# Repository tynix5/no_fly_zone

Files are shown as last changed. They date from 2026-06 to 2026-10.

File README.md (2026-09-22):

# no_fly_zone
STM32-based quadcopter running on custom hardware and custom flight controller software

## /firmware
Contains STM32 libraries, source code, and build settings for remote and quadcopter

### /no_fly_zone
Contains STM32 flight controller software

### /no_fly_zone_remote
Contains remote control software

### /scripts
AI-generated scripts for testing and validating flight controller outputs

### /stm32_lib
Contains all relevant libraries for sensors and peripheral management

## /hardware
Contains KiCAD schematics + PCB designs for remote and quadcopter

## /screenshots
Contains relevant screenshots for those in other READMEs

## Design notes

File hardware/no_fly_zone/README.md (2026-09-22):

# no_fly_zone Schematic + PCB

## Overview

The quadcopter requires several components

1. Microcontroller
2. Sensor Suite
3. Radio Communication
4. Power Circuitry
5. ESC
6. Motors

The flight controller chosen was the STM32F446RCT for its high maximum clock frequency, dedicated FPU, and abundant communication modules. The sensor suite in Revision 1.0 consists of a 6DOF IMU, magnetometer, barometer, and GPS. Each of these sensors provides useful data for the flight controller. The IMU provides information on pitch and roll, magnetometer on yaw, barometer on altitude, and GPS for extended yaw support as well as location tracking for future revisions. Onboard magnetometers are very susceptible to EMF fields from motors, other sensors, as well as PCB traces. Thus, the GPS can be used as a backup for heading. 

The nRF24L01 was chosen to communicate with the remote, also using the nRF24L01. In the future, a dedicated PA + LNA chip may be added on board to extend quadcopter range.

The power circuitry consists of an onboard buck converter on the bottom side of the PCB in order to reduce noise to other components. More details below.

## Revision 1.0
### Summary

The single schematic given here is separated into two boards. A singular board containing all components was not able to fit onto the quadcopter frame. Thus, a separate MCU board and sensor board were produced using KiKit and connectors were used to share power and communication.

### Schematics

#### Hierarchal Schematic

The hierarchal schematic provides a top-level overview of the two boards. The ESC connectors, power schematic, and RF schematic were all included on the MCU board. The sensor board contains only the sensor schematic.

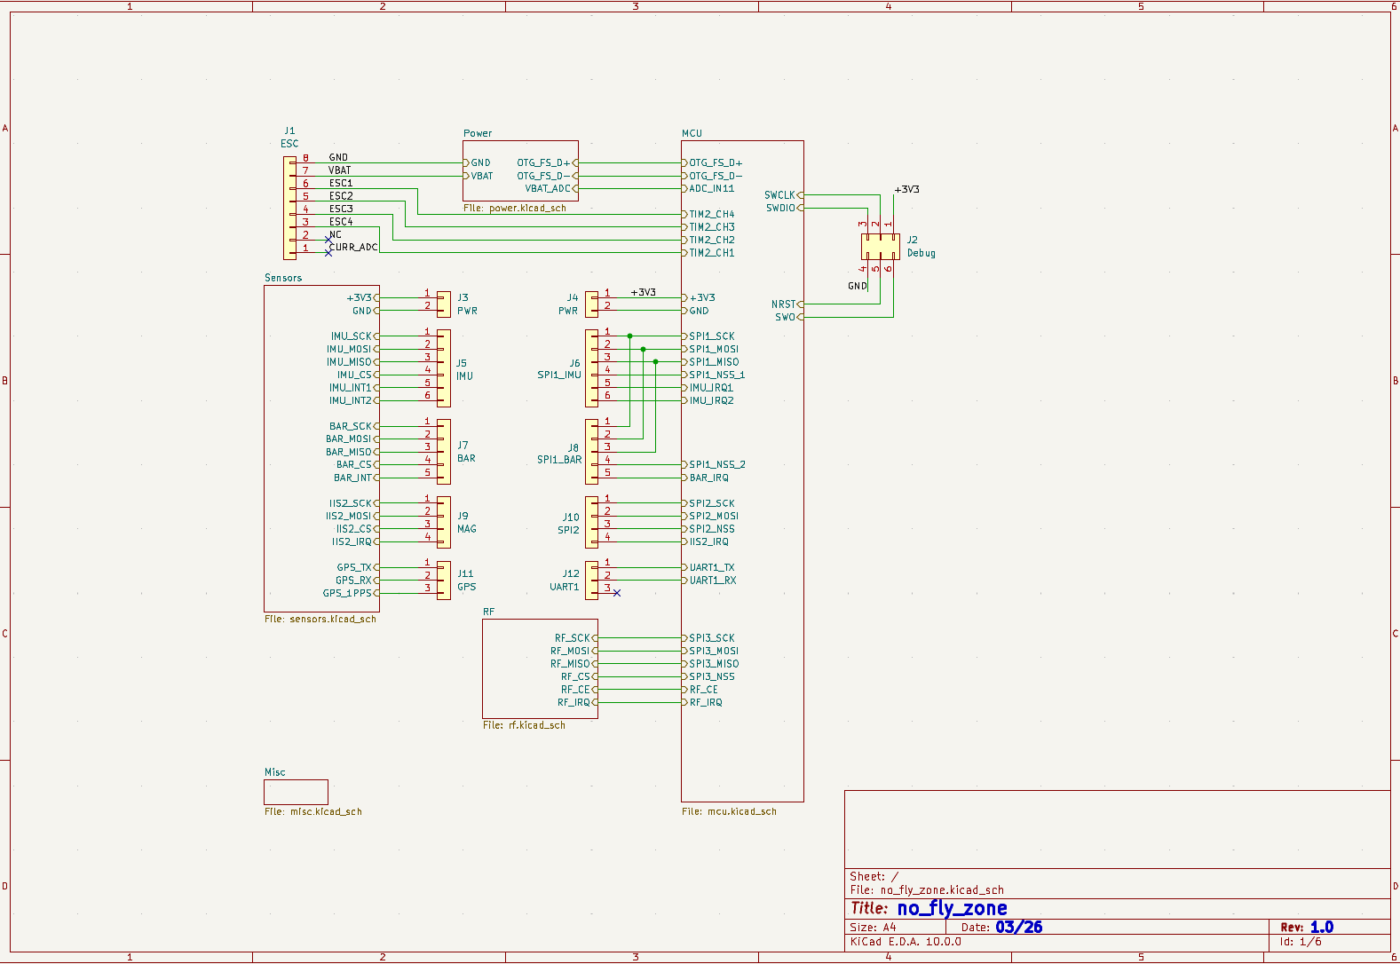
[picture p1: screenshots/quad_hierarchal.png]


#### MCU

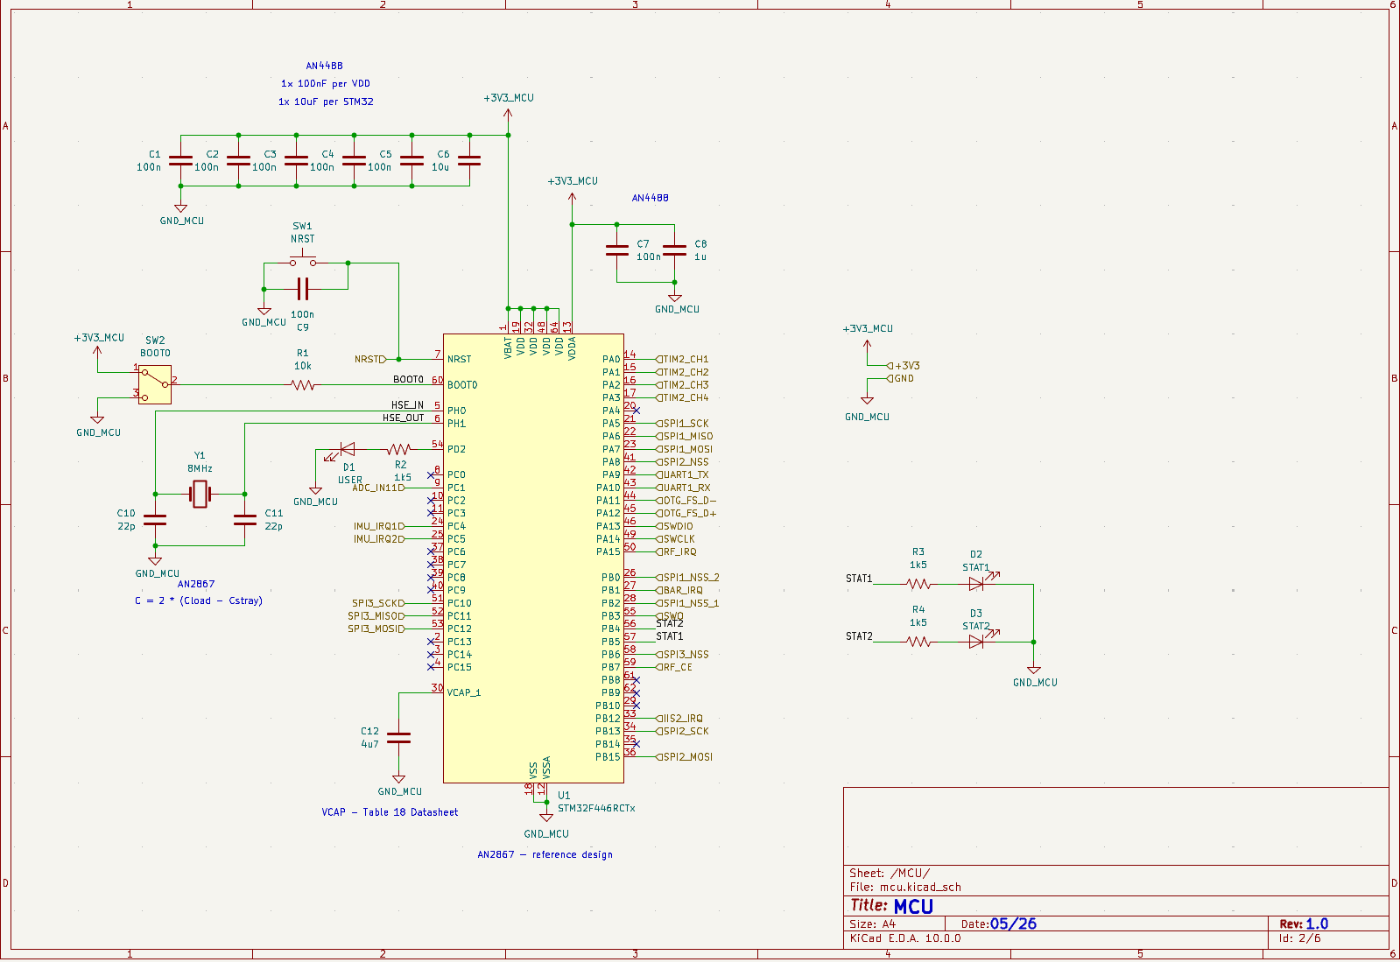
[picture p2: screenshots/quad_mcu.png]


#### Sensors

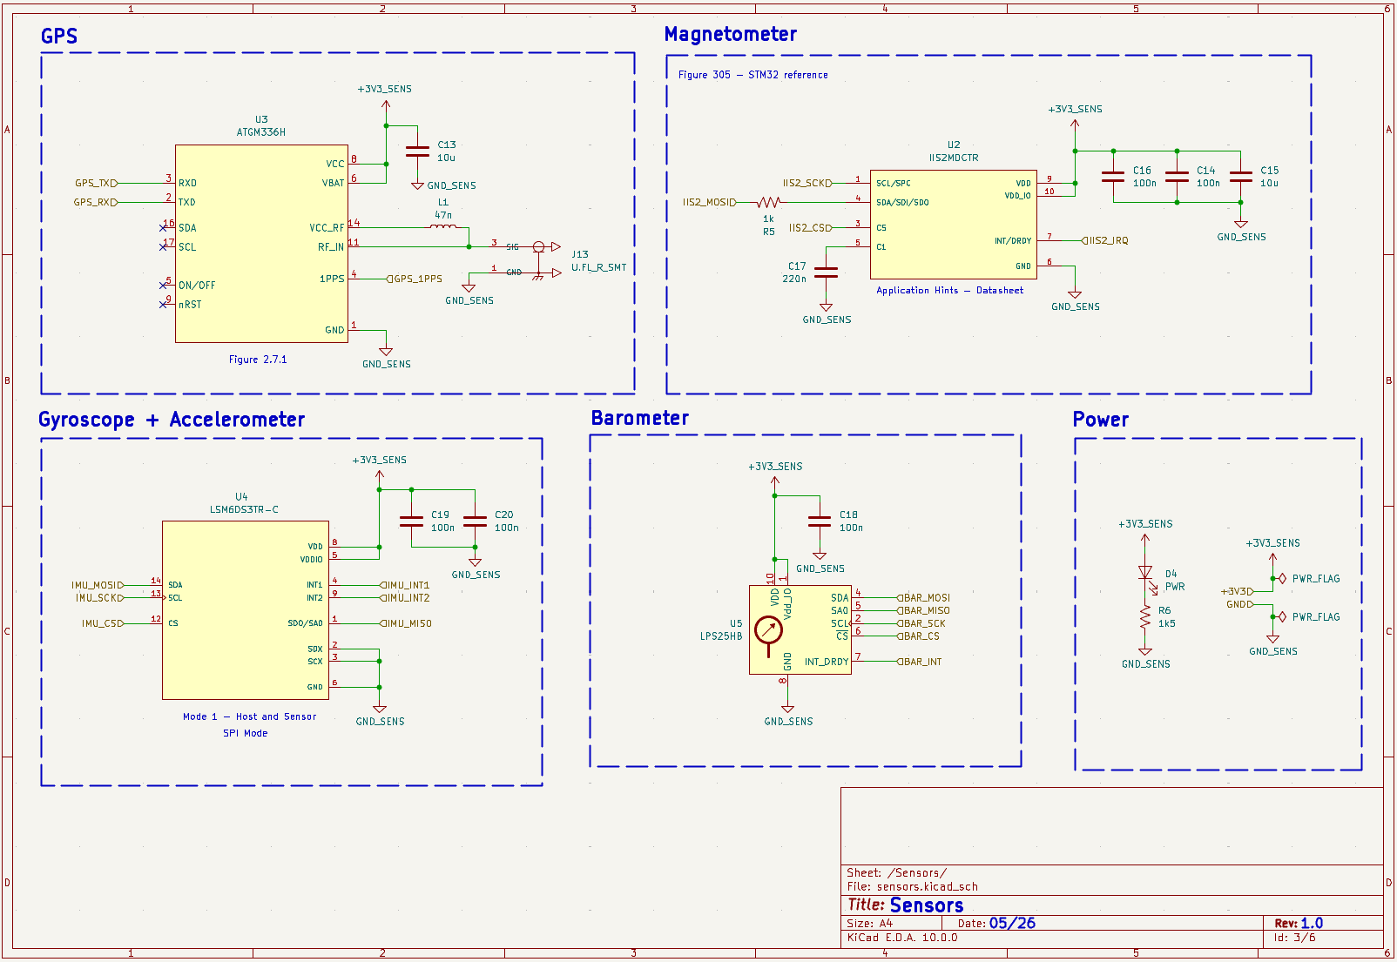
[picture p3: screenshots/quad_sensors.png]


#### Power

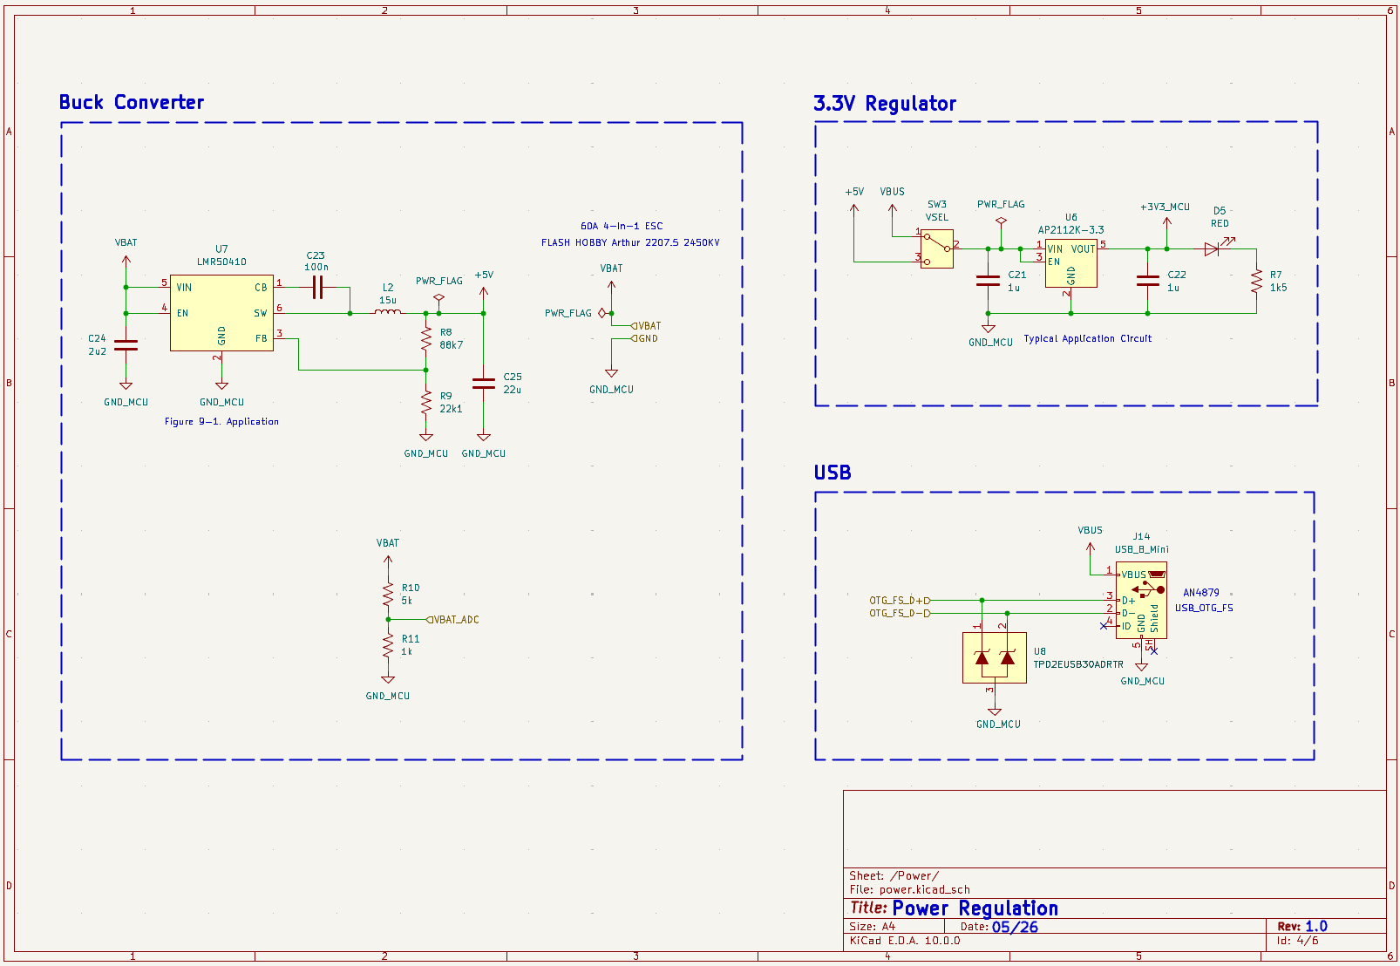
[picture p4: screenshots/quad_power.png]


#### RF

Like the RF section on the remote, the nRF24L01 is surrounded by a continuous ground plane on the top layer as well as the layer directly underneath the antenna for stability. Stitching vias are placed about ~6mm apart (between lambda/10 - lambda/20 of 2.4 GHz wavelength) near antenna for shielding.

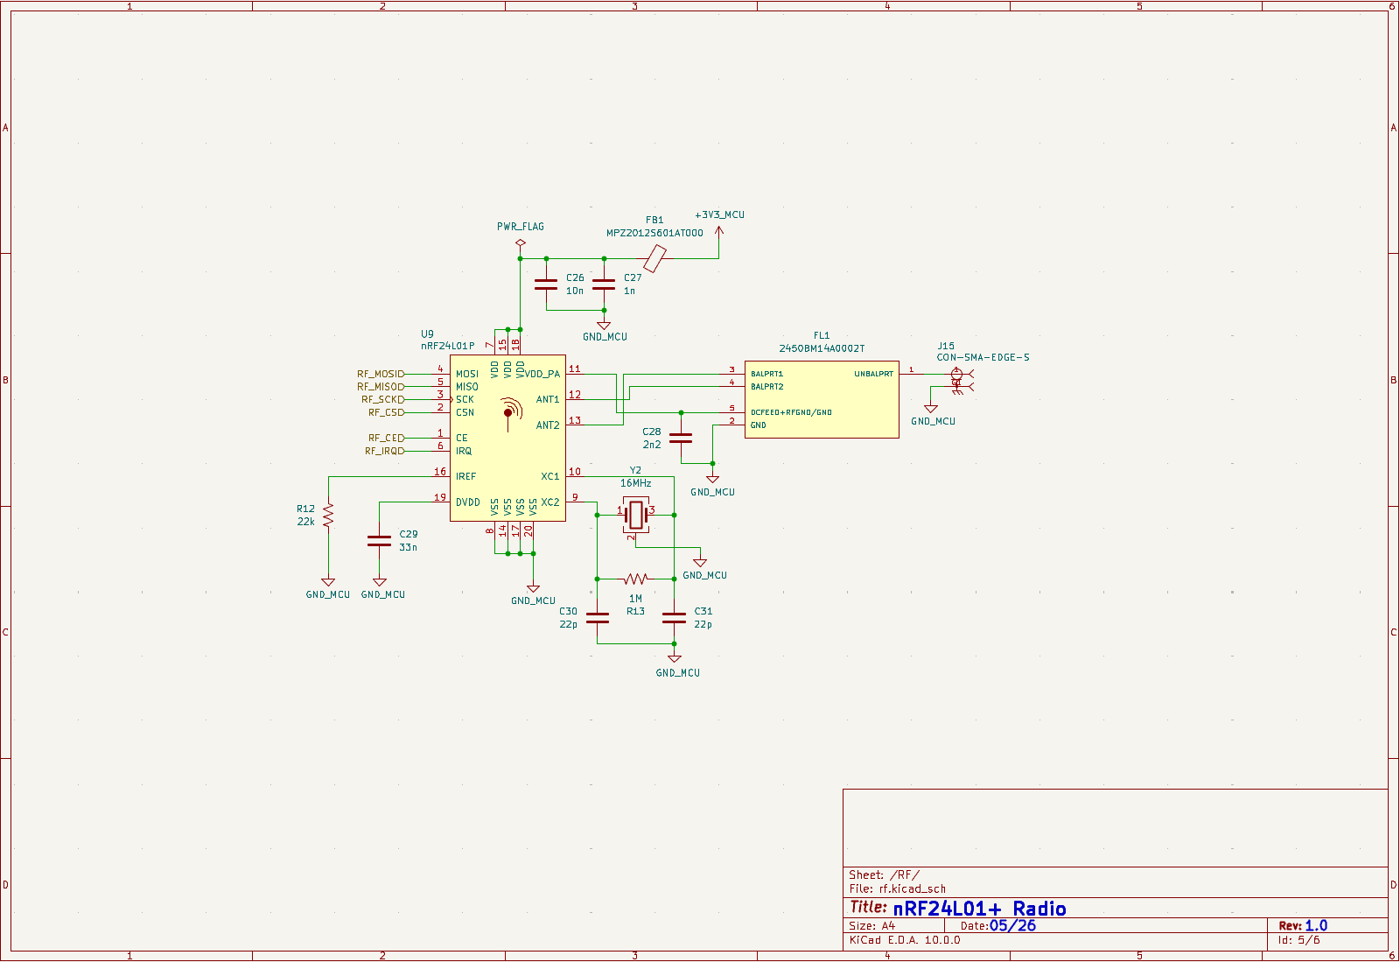
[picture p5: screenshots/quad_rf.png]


#### Misc

Contains 8 M3 screw holes, 4 for each board. Not shown for brevity.

#### PCB

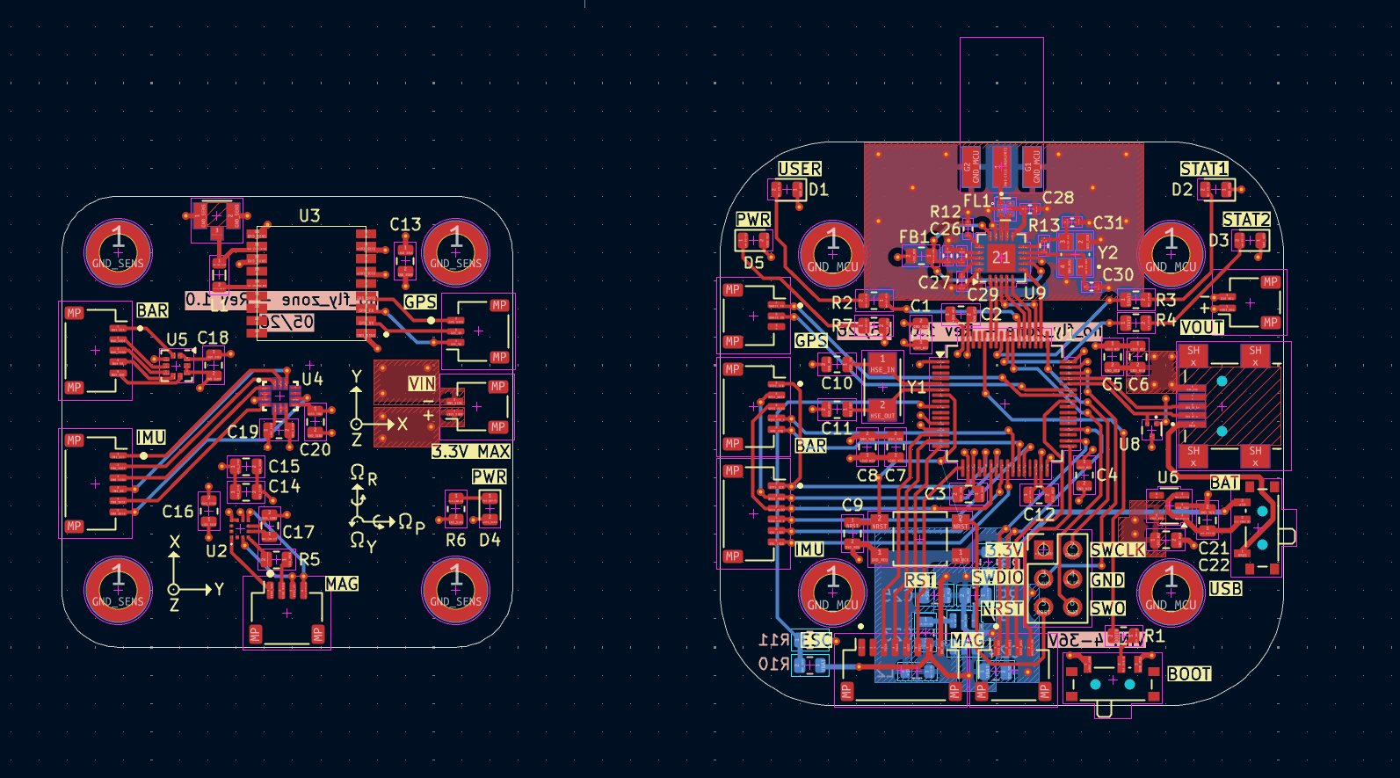
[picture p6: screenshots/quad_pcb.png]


#### 3D

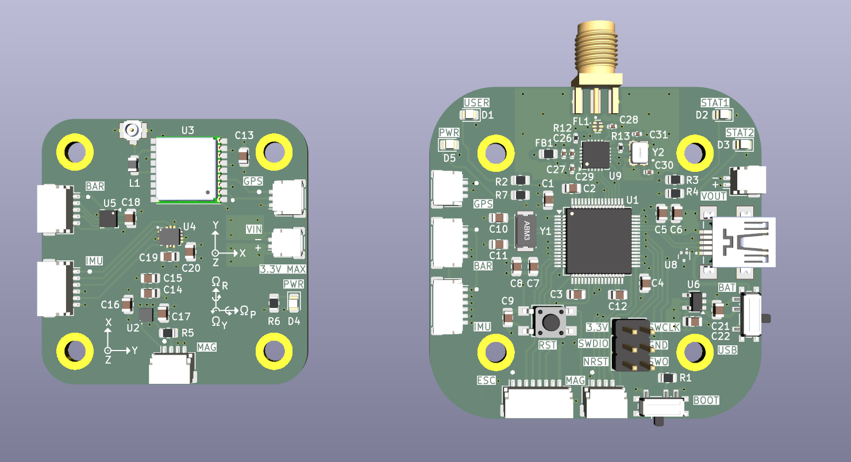
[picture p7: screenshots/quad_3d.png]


## Revision 2.0

### Summary 
This revision involved consolidating the sensor board and MCU and removing the onboard magnetometer and GPS. The goal of this project was to achieve simple flight manuevers and hovering, and using these sensors would require more in depth sensor fusion algorithms. The antenna section was improved with further RF shielding and stitching vias, as well as a taper from the RF unbalanced port to the SMA pad. The board stackup changed from SIG - GND - 3.3V - SIG to a SIG - GND - GND - SIG + 3.3V to reduce buck converter and RF noise. 

Revision 1.0 board worked, but there were some problems with the JST connectors, making it hard to keep communication with the sensors, and they would not have been very reliable in a noisy and harsh environment. Ground lines were needed next to every signal line, but only one ground line was used on the entire board (power connector).

### Changes
- Consolidated sensor and controller board
- Removed magnetometer and GPS
- Improved RF shielding and layout
- Layer stackup changed from SIG-GND-3.3V-SIG to SIG-GND-GND-3.3V

### Schematics

### Hierarchal Schematic
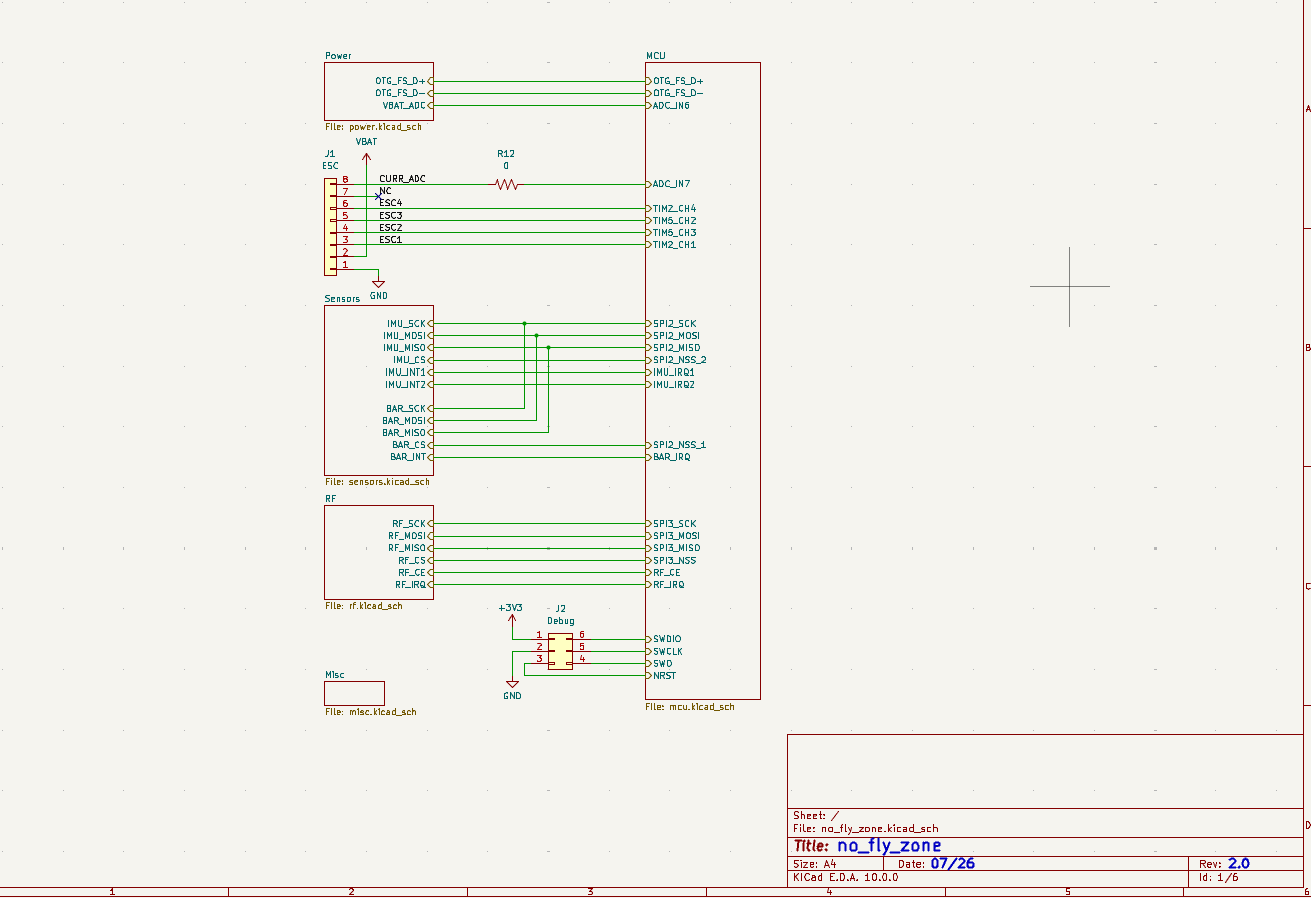
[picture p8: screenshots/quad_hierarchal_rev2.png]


#### MCU
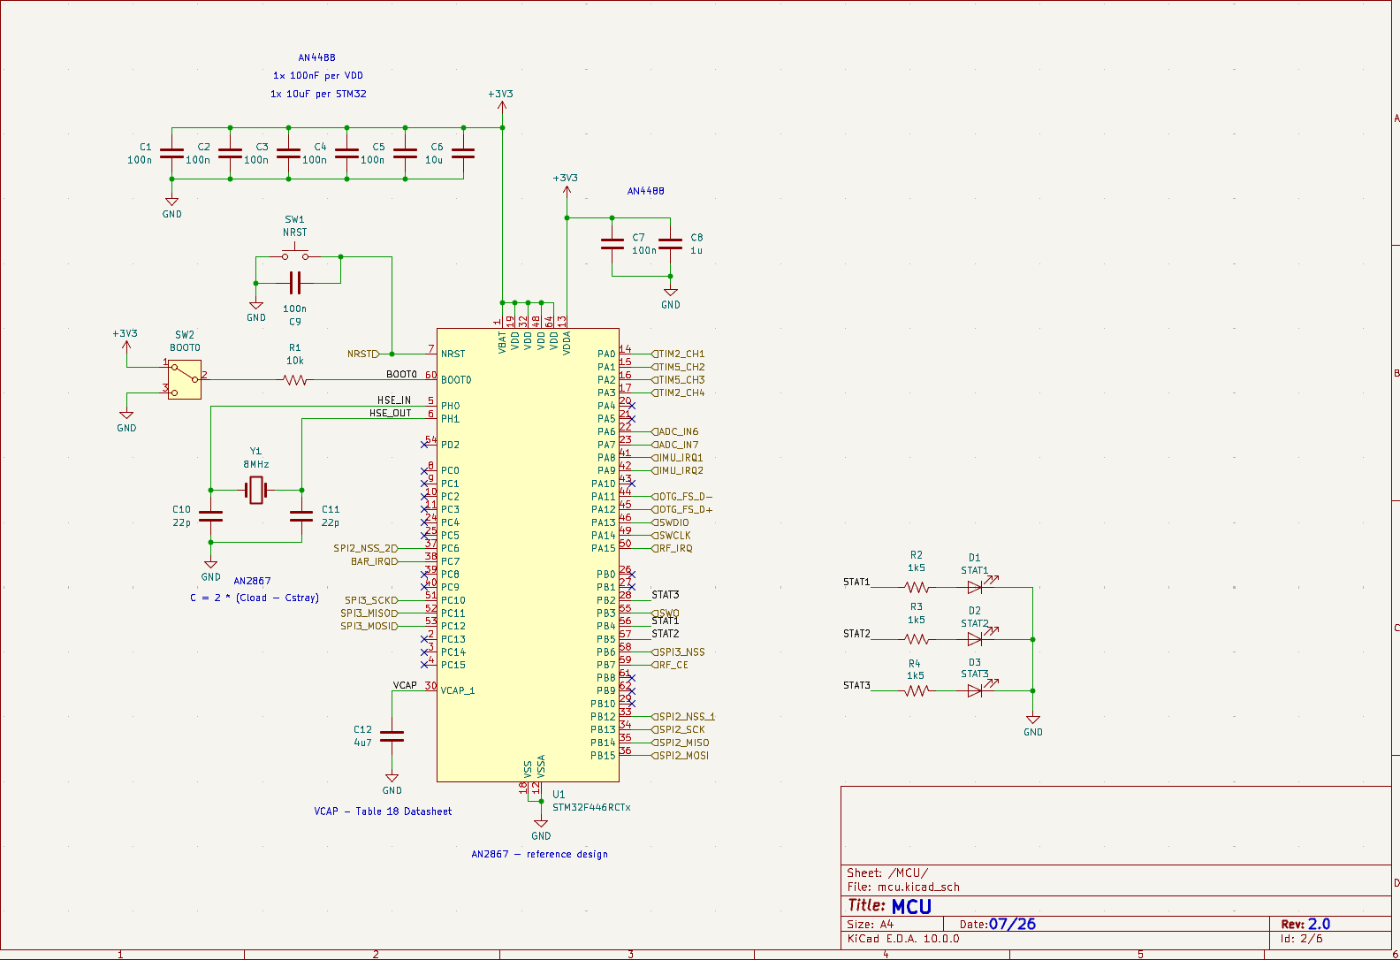
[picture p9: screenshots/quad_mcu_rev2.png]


#### Sensors
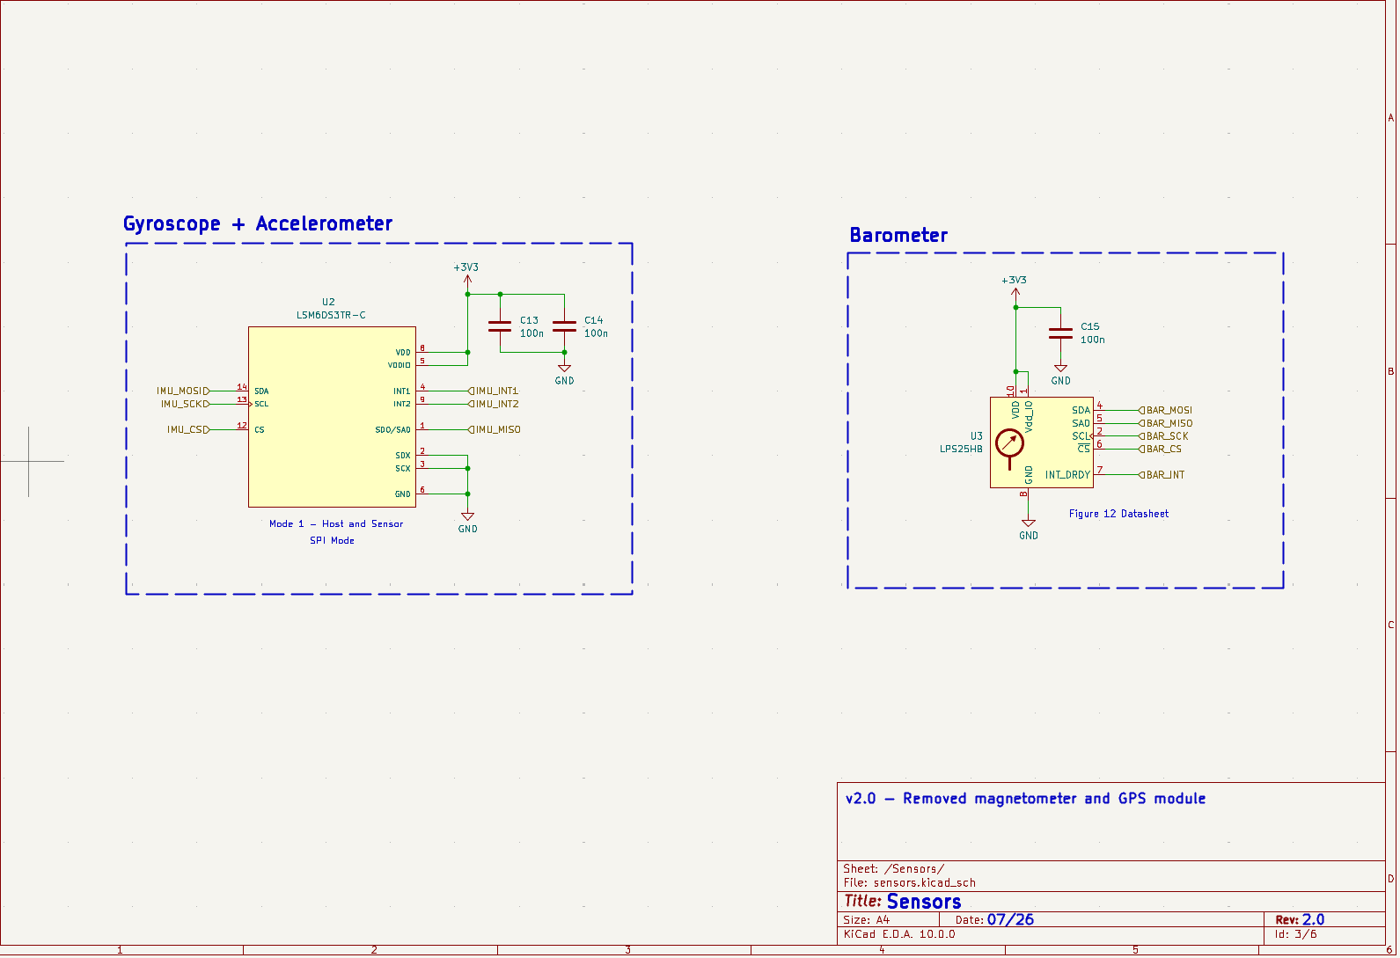
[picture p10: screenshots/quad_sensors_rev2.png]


#### Power
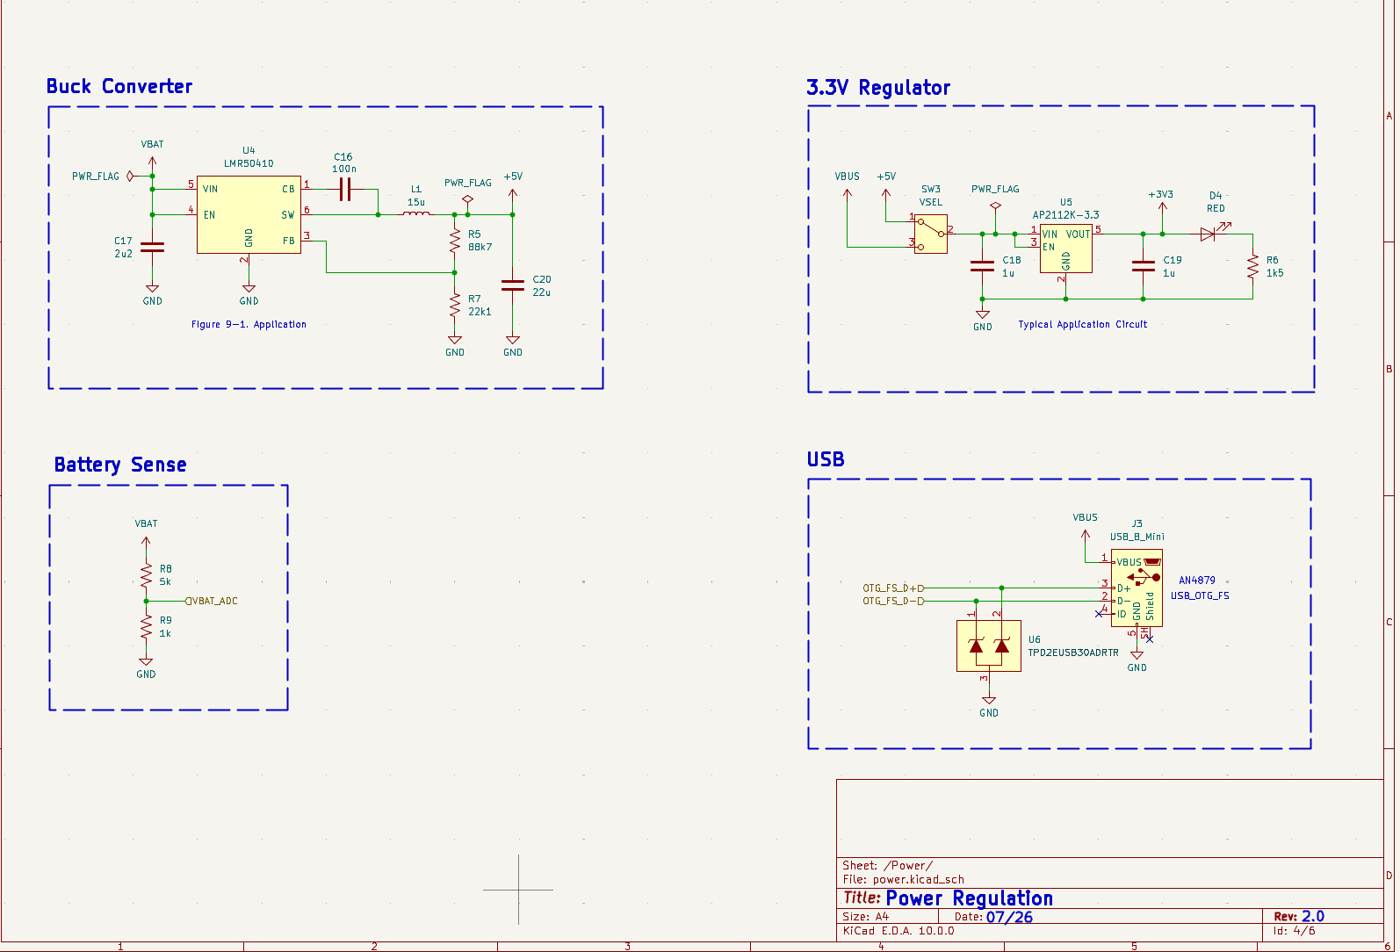
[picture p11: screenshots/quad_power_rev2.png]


#### RF
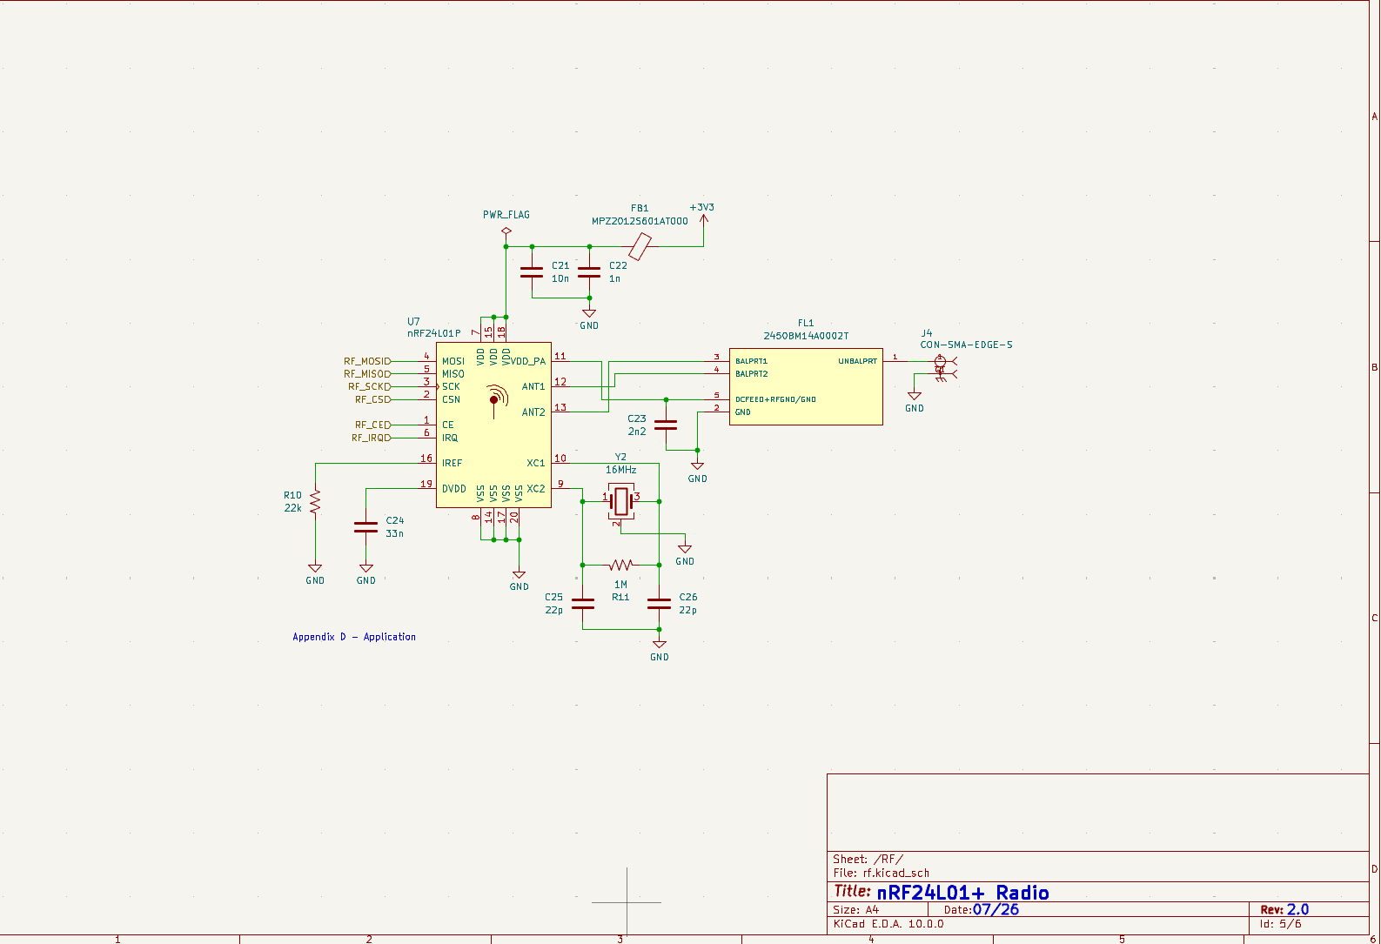
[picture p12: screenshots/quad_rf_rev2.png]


#### PCB

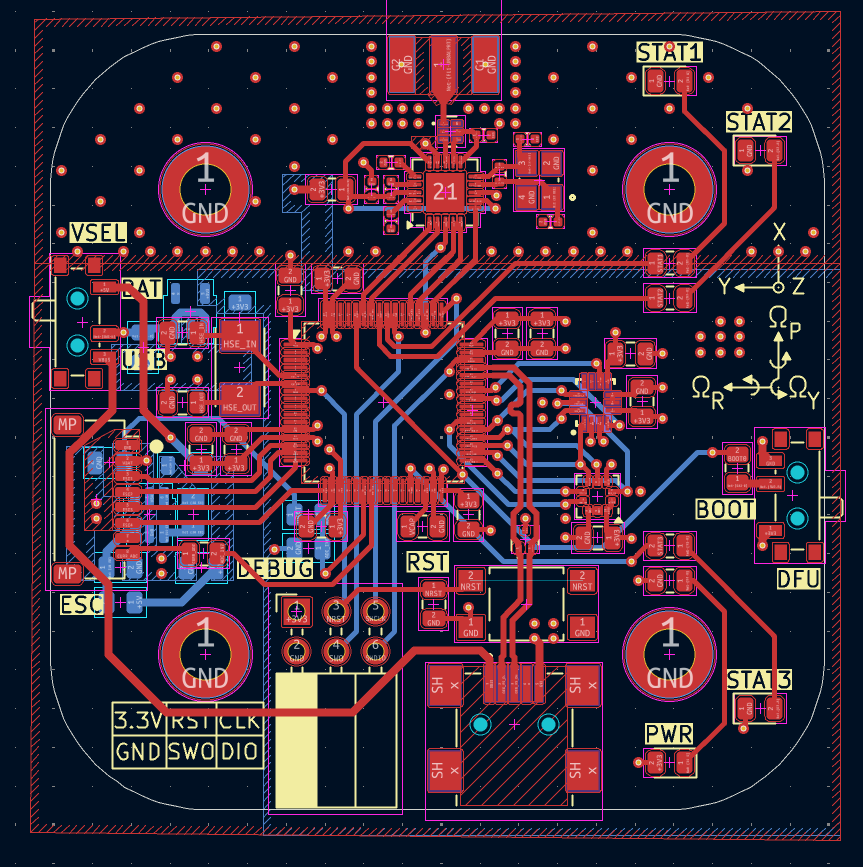
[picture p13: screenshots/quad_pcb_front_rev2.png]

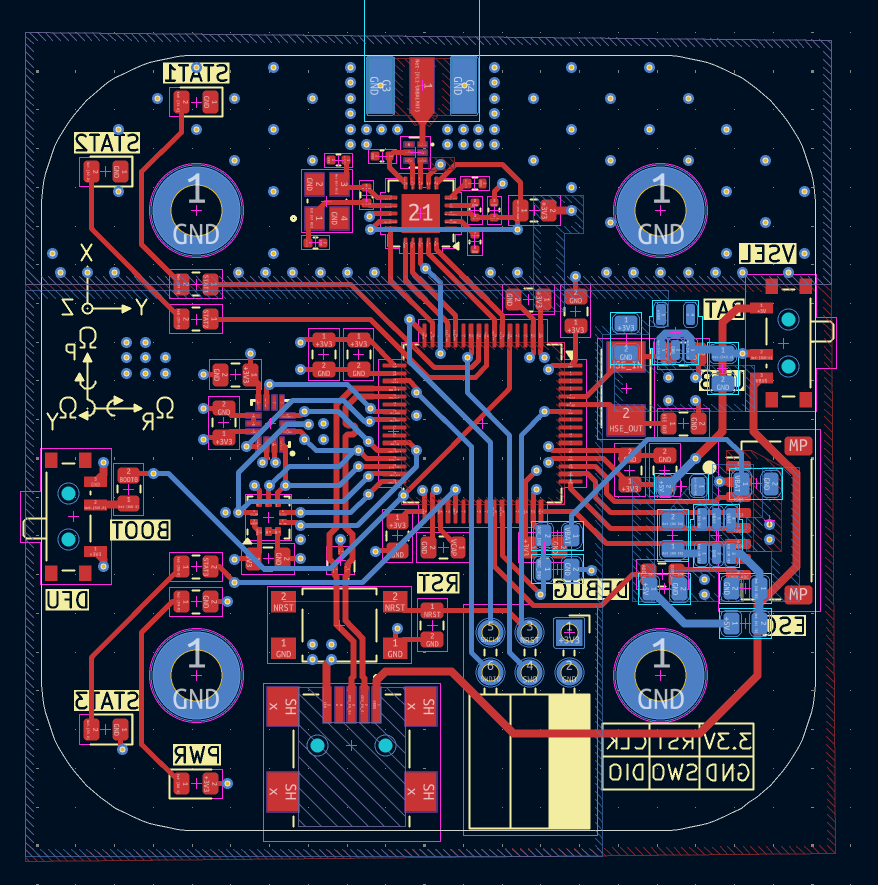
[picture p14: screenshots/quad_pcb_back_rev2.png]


#### 3D

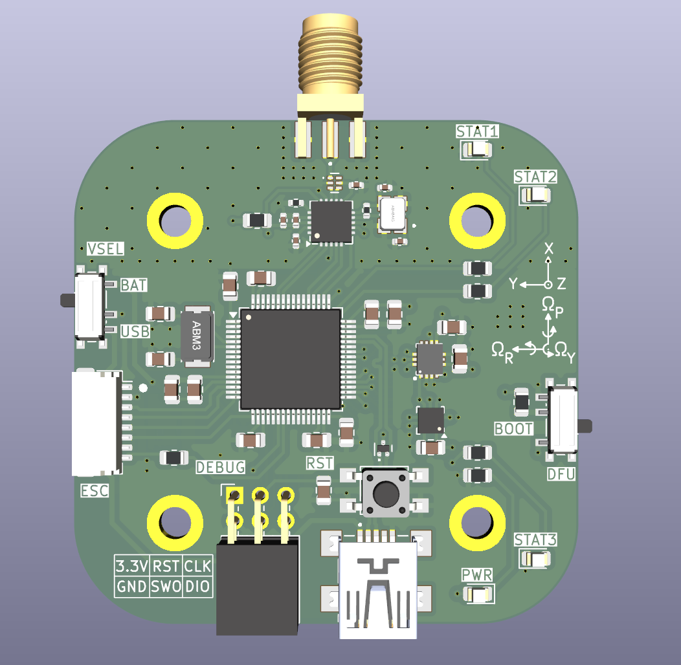
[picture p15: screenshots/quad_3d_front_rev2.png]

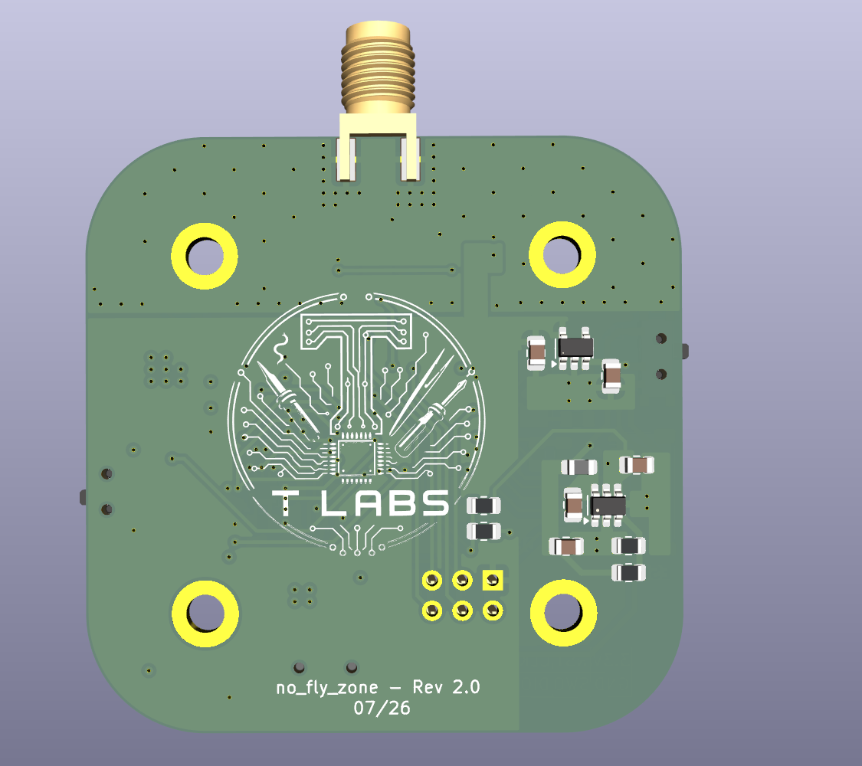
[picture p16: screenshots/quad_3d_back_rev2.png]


## Revision 2.1

### Summary 
While working with the Revision 2.0 flight controller, it was too large to fit comfortably on the quadcopter frame, so changes were made to reduce size while keeping functionality

### Changes
- Board size reduced from 50mm x 50mm to 40mm x 40mm
- Most part footprints reduced from 0805 packages to 0603
- Added TVS diodes to power inputs and connectors
- Removed ferrite bead in series with RF power supply
- Changed debug connector to STLINK specific
- Moved STAT3 from PB2 to PB8

#### MCU
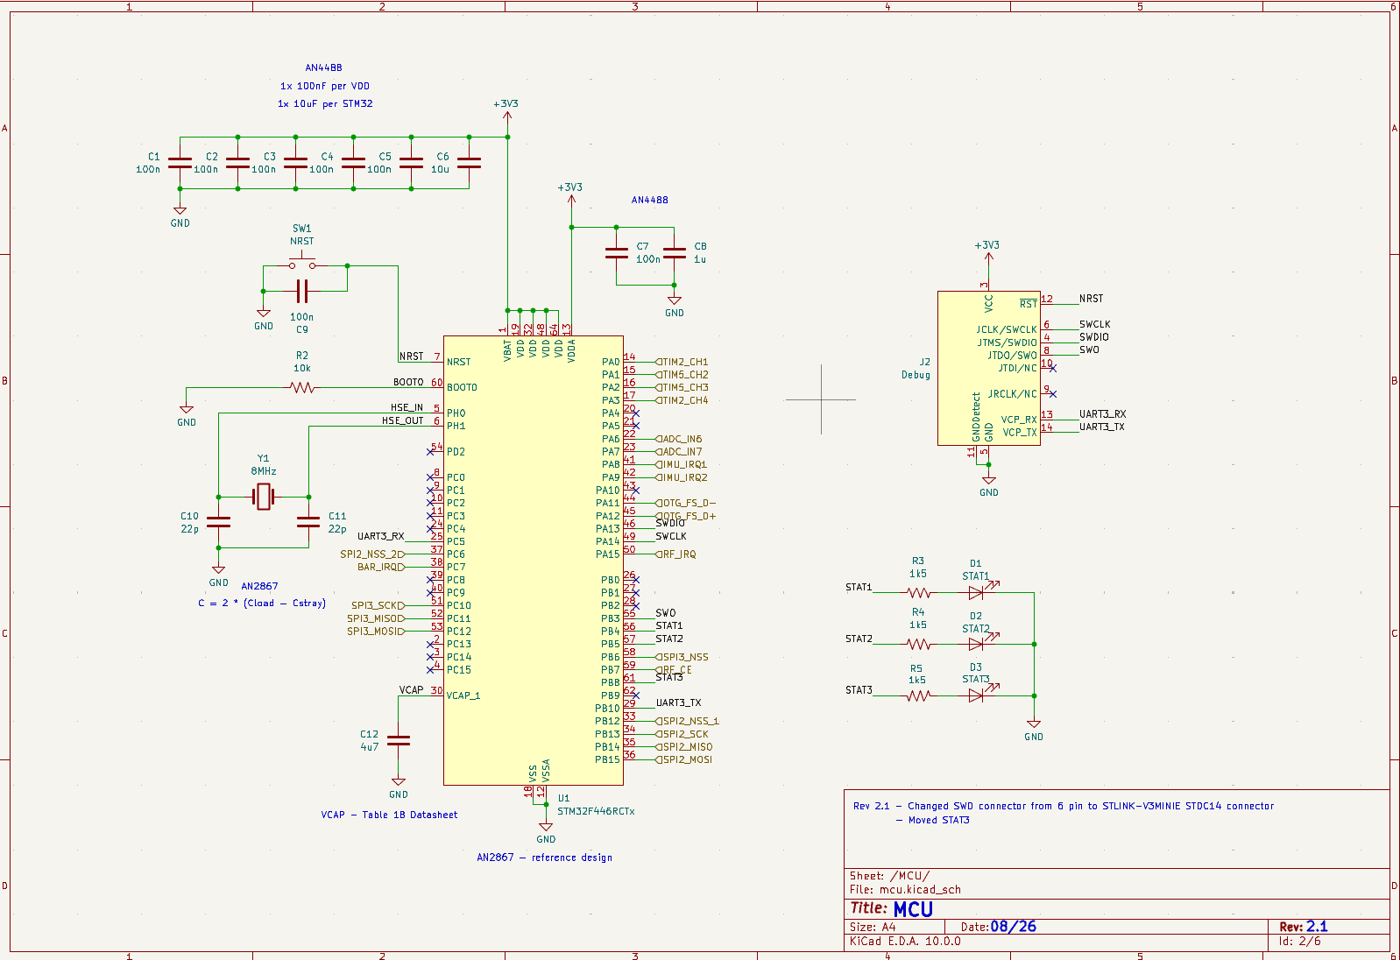
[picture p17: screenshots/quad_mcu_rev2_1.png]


#### Sensors
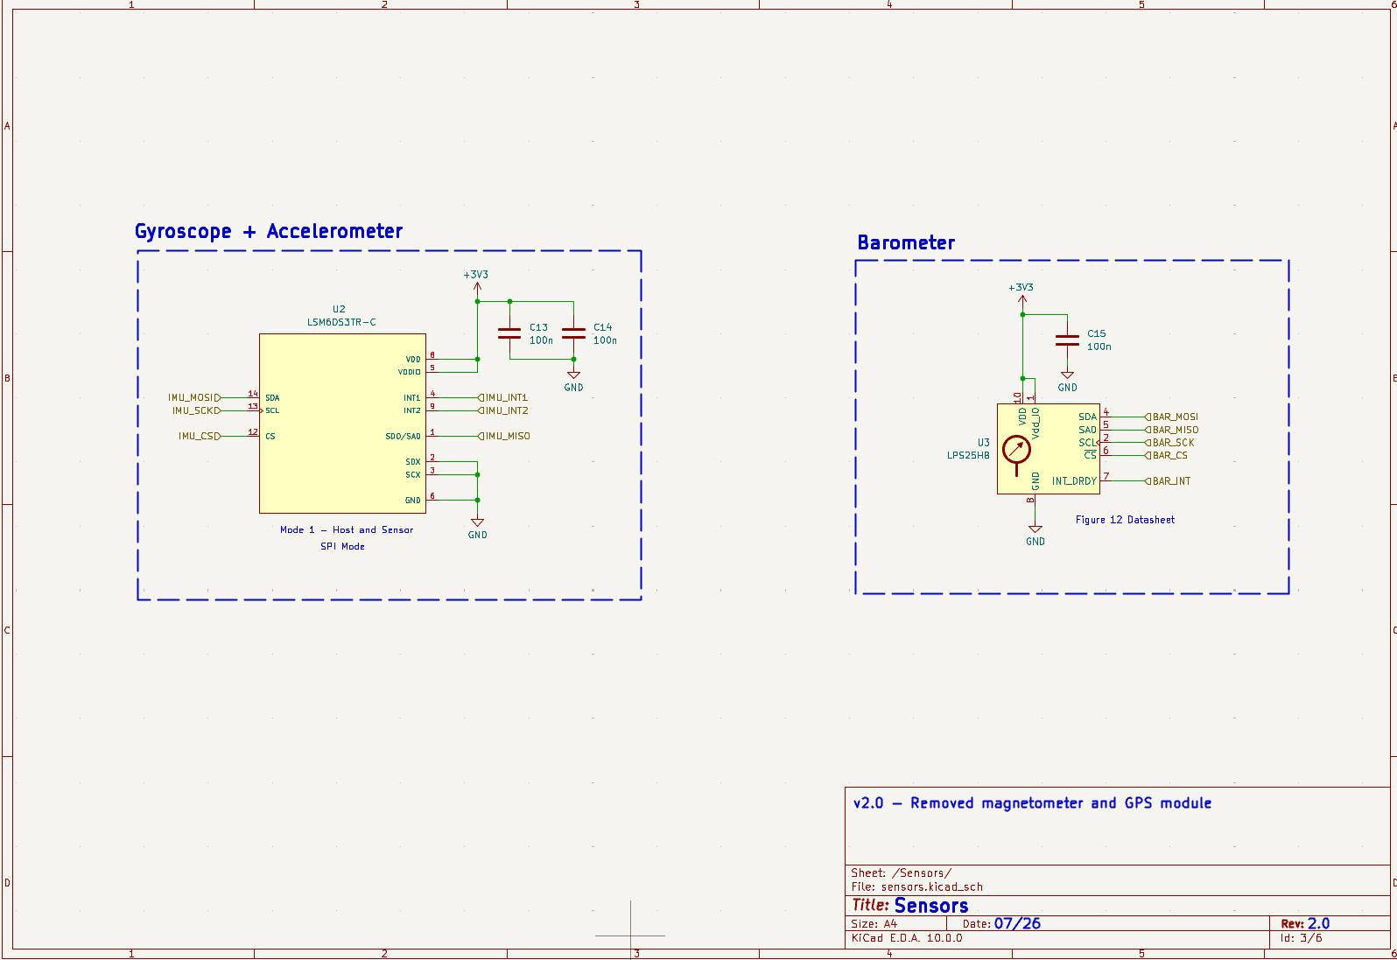
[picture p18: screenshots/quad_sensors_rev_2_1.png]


#### Power
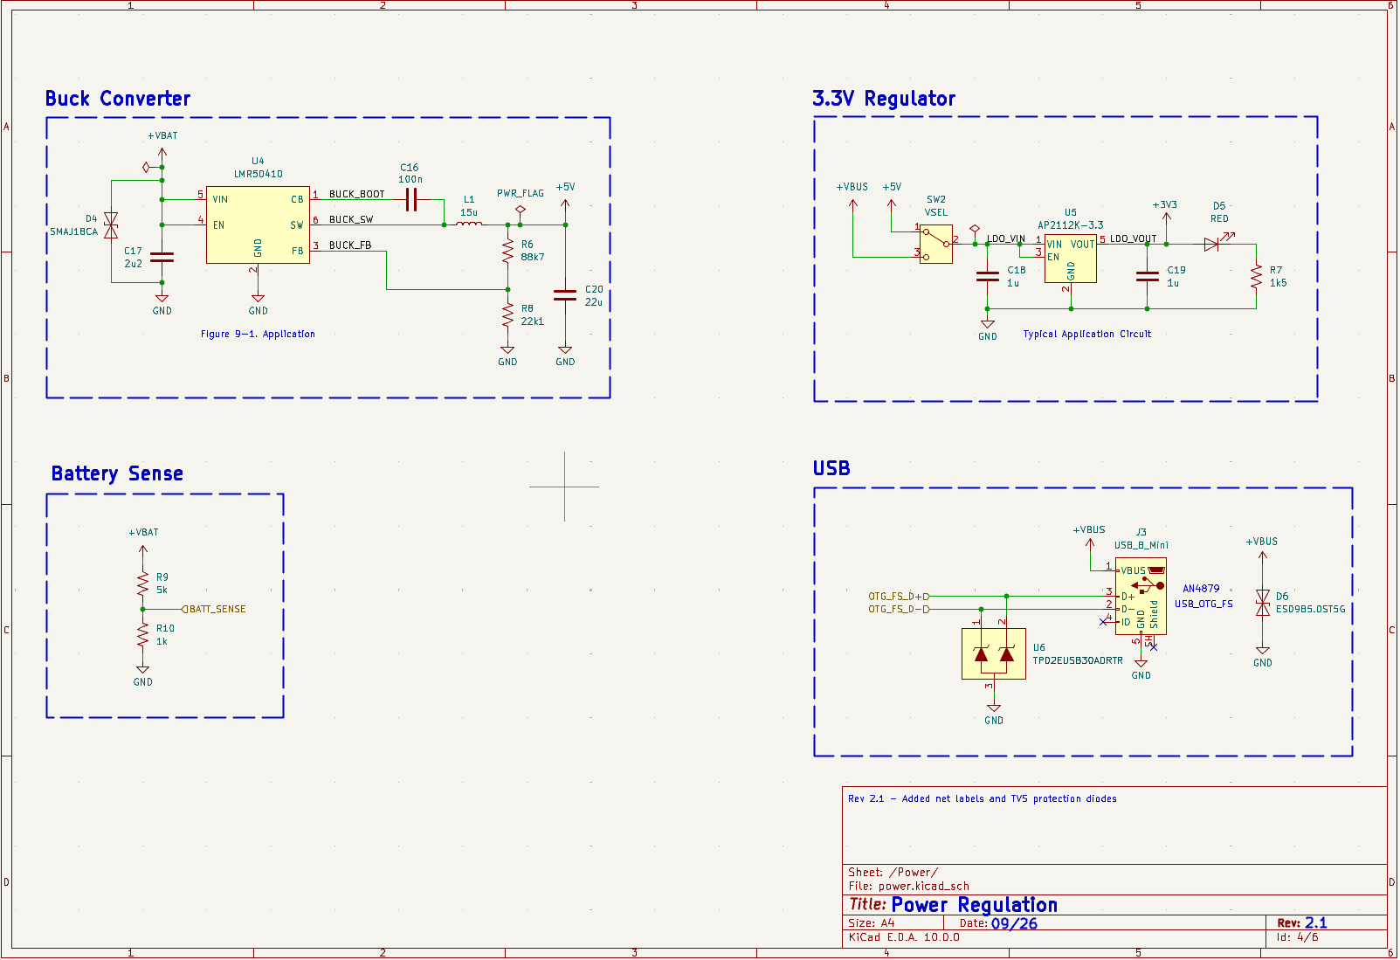
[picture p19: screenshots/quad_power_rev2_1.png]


#### RF
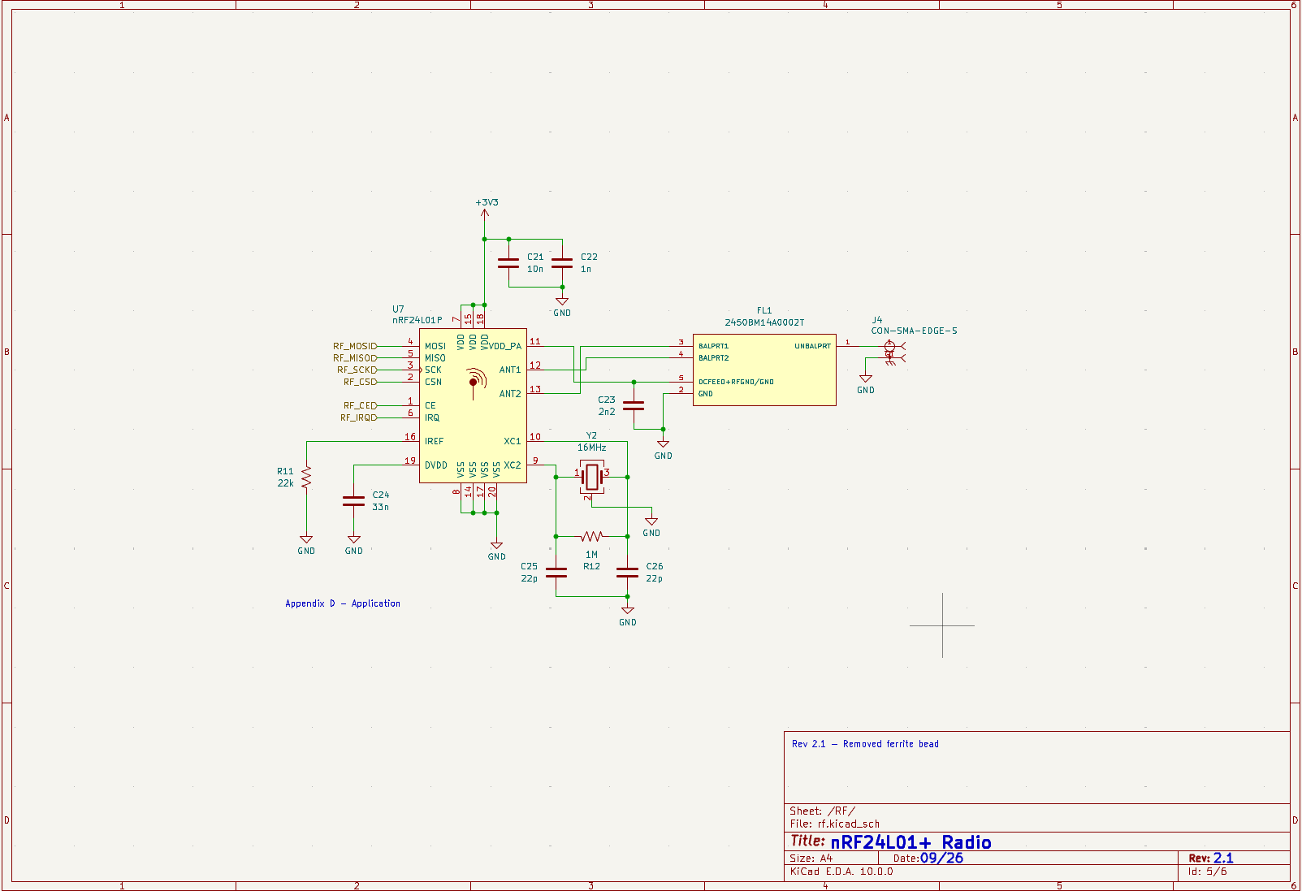
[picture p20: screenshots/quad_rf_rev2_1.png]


#### 3D
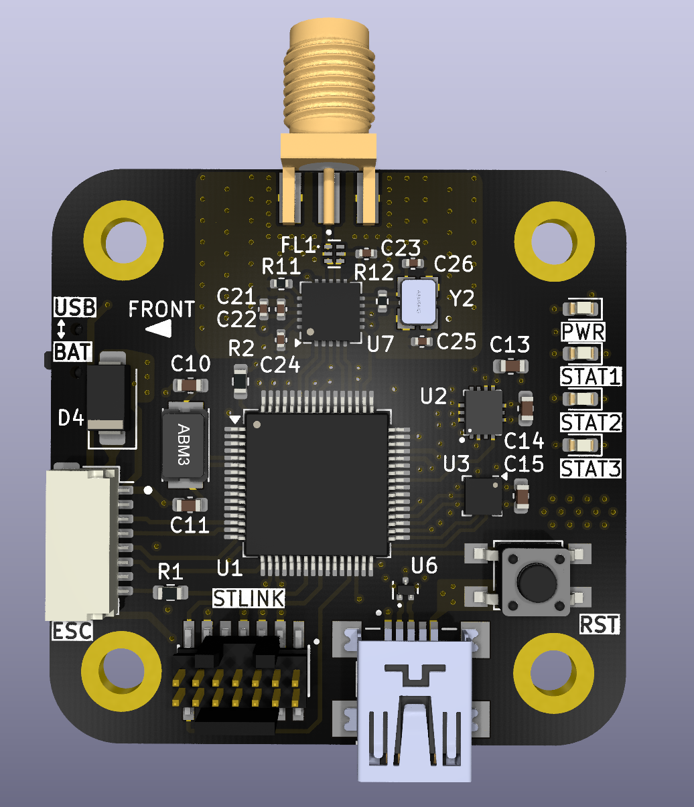
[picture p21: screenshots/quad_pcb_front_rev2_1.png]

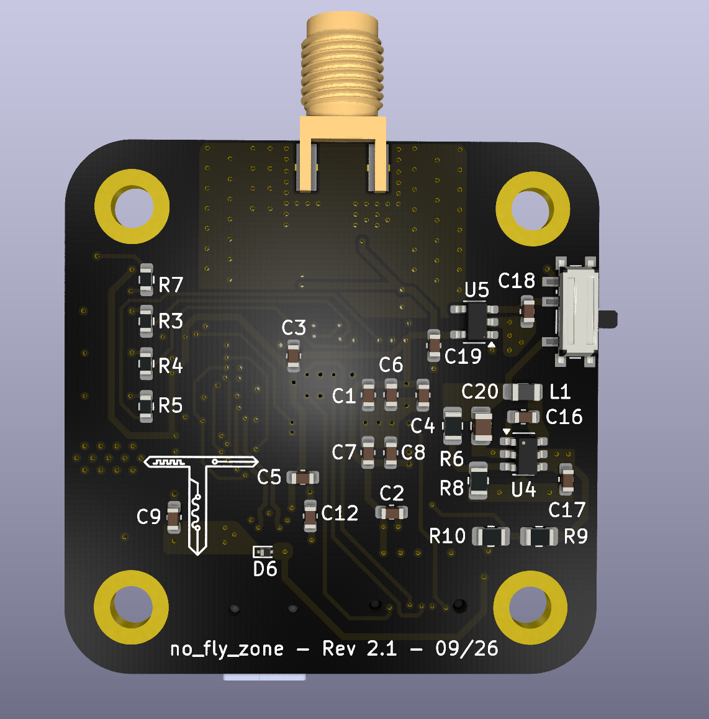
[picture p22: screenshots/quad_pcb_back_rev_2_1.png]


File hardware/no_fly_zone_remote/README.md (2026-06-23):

# no_fly_zone_remote Schematic + PCB
## Overview

The remote for this quadcopter requires several things

1. Microcontroller
2. Control Inputs - Joysticks, Encoders
3. Wireless Communication
4. Charging Circuitry
5. OLED

The STM32L432KC microcontroller was chosen for its small package, low power draw, and adequate maximum clock speed. The joysticks, PS5 TMR (Tunnel Magnetoresistance), were chosen due to their low deadzones, small footprint, and wide availability. The joysticks control the quadcopters throttle, yaw, pitch, and roll. The encoder included on the PCB is used to switch between various menus, displayed on the SSD1306 OLED, and for tuning quadcopter PID parameters easily. The nRF24L01 radio was chosen for its high availablity and simplicity in function. The charging circuity involves an autoswitching power multiplexer and a linear 1S LiPo charger. The autoswitcher IC automatically chooses the highest available power source. If only LiPo is connected, it is used to power the remote, but if LiPo and USB power are present, USB power is used to power the board and simultaneously charge the LiPo. The board can also be powered using only USB without a LiPo.

More details are given on the schematics for exact component parameters.

All footprints and schematics symbols were found online or in KiCAD libraries.

## Versions

The folder structure indicates there are two versions of the PCB: original and revised. The original PCB was never manufactured and used the wrong footprints for several parts, as well as did not have great PCB design characteristics. Instead, the revised version was manufactured and shows all correct footprints and better PCB design methodology. 

An important note on the revised version is Revision 1.0 used the wrong TVS diodes for USB D+ and D-, but these were changed to dedicated USB TVS diodes in a later revision.

## Schematics

### Hierarchal Schematic

The hierarchal schematic details how the MCU, sensors, and power schematics are connected.

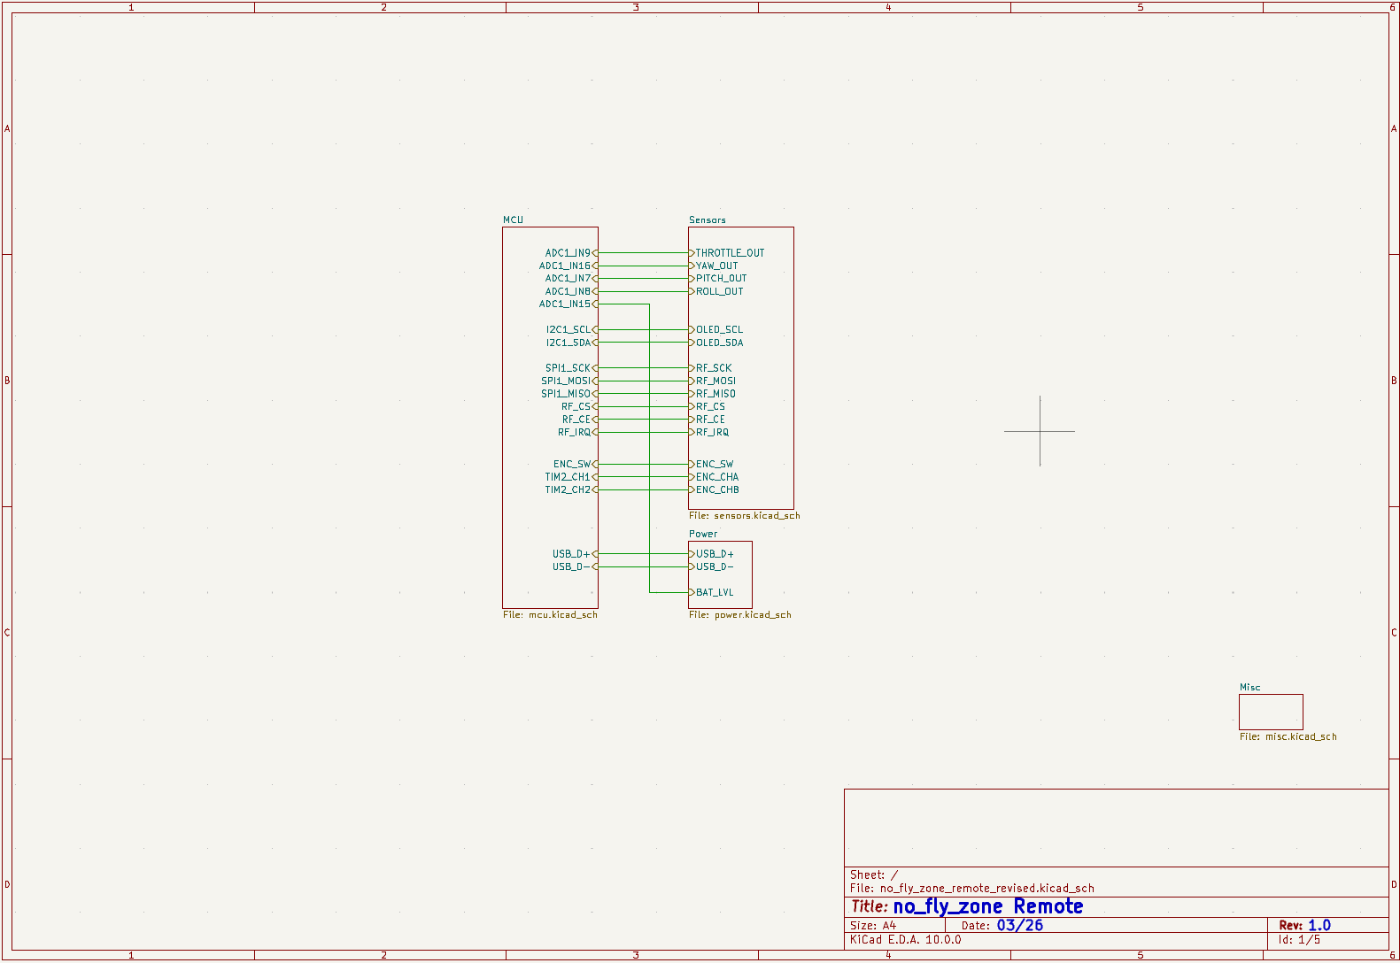
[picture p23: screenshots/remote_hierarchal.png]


### MCU

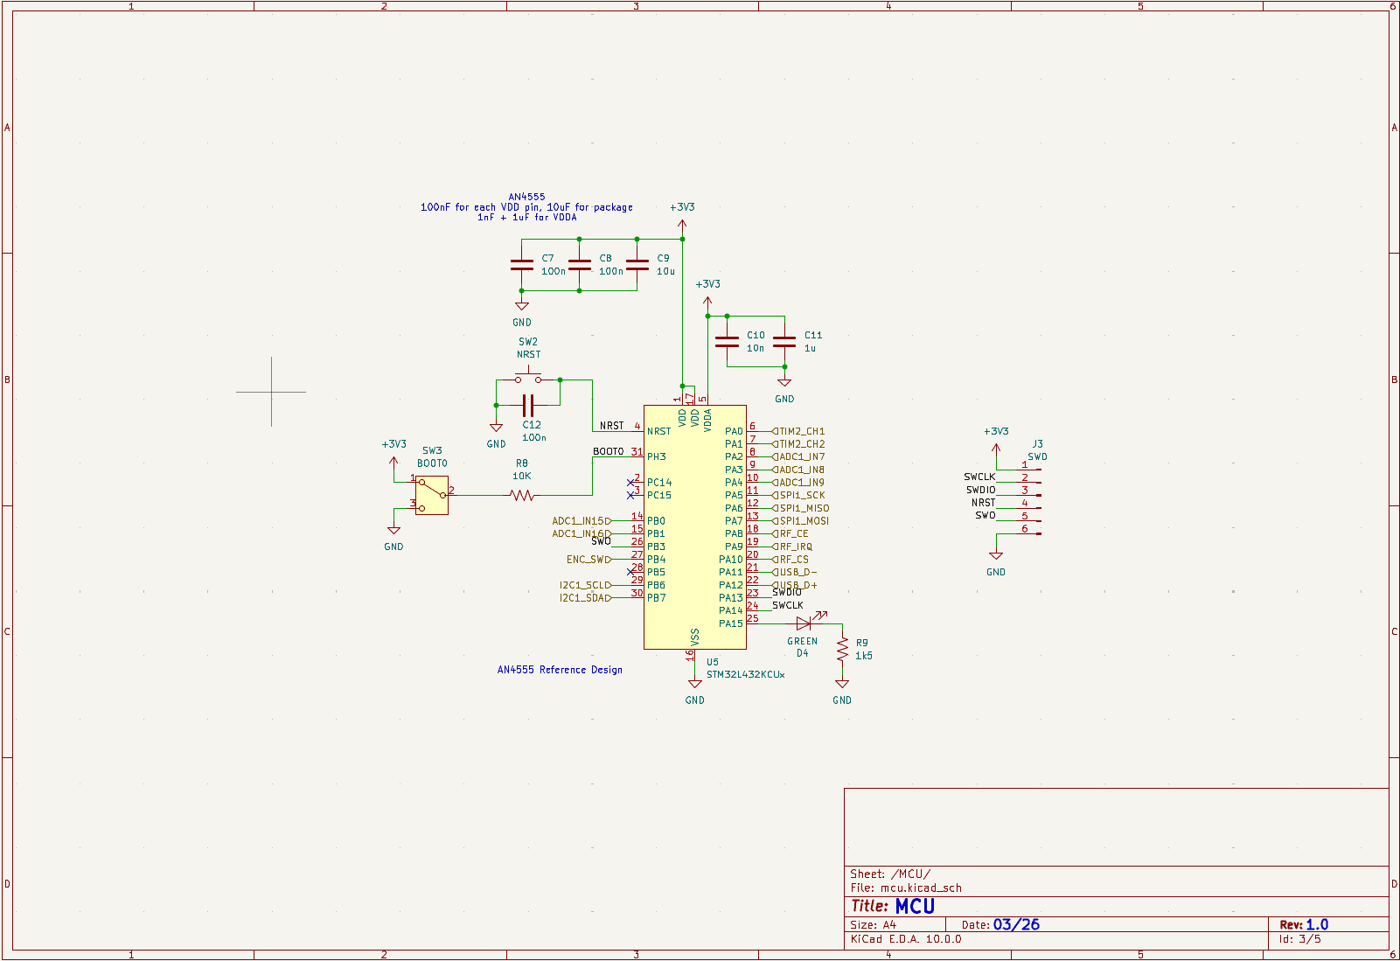
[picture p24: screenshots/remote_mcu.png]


### Sensors (Radio, OLED, Joysticks, Encoder)



### Misc

Contains four M3 screws with pads, not shown for brevity

### PCB

Note on radio layout: the nRF24L01 is surrounded by a continuous ground plane on the top layer as well as the layer directly underneath the antenna for stability. Stitching vias are placed about ~6mm apart (between lambda/10 - lambda/20 of 2.4 GHz wavelength) near antenna for shielding.



### 3D Model



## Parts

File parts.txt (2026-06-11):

Quadcopter
CPU: STM32F466RCT6
IMU (accel + gyro): LSM6DS3TR-C
Magnetometer: IIS2MDCTR
GPS: ATGM336H
Barometer: LPS25HB
Radio: nRF24L01
Motors: FLASH HOBBY Arthur 2207.5 Outrunner 2450KV
ESC: AERO SERLFIE 60A 4IN1 ESC 2S-6S LiPo
Rotors:
Battery:
Frame: FPVDrone 225mm FPV Racing Drone 5 inch

Controller
CPU: STM32L432KC
Joystick: Gulikit TMR
Encoder: Bourns PEC11R-2415F-S0024
Radio: nRF24L01
Battery: EEMB 3.7V LiPo Battery 1100mAh

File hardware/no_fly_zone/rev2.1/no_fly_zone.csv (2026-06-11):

Id | Designator | Footprint | Quantity | Designation | Supplier and ref
1 | C1, C2, C3, C4, C5, C7, C9, C14, C16, C18, C19, C20, C23 | C_0805_2012Metric | 13 | 100n
2 | C6, C13, C15 | C_0805_2012Metric | 3 | 10u
3 | C8, C21, C22 | C_0805_2012Metric | 3 | 1u
4 | C10, C11 | C_0805_2012Metric | 2 | 22p
5 | C12 | C_0805_2012Metric | 1 | 4u7
6 | C17 | C_0805_2012Metric | 1 | 220n
7 | C24 | C_0805_2012Metric | 1 | 2u2
8 | C25 | C_0805_2012Metric | 1 | 22u
9 | C26 | C_0402_1005Metric | 1 | 10n
10 | C27 | C_0402_1005Metric | 1 | 1n
11 | C28 | C_0402_1005Metric | 1 | 2n2
12 | C29 | C_0402_1005Metric | 1 | 33n
13 | C30, C31 | C_0402_1005Metric | 2 | 22p
14 | D1 | LED_0805_2012Metric | 1 | USER
15 | D2 | LED_0805_2012Metric | 1 | STAT1
16 | D3 | LED_0805_2012Metric | 1 | STAT2
17 | D4 | LED_0805_2012Metric | 1 | PWR
18 | D5 | LED_0805_2012Metric | 1 | RED
19 | FB1 | R_0805_2012Metric | 1 | MPZ2012S601AT000
20 | FL1 | FIL_2450BM14A0002T | 1 | 2450BM14A0002T
21 | J1 | JST_SH_SM08B-SRSS-TB_1x08-1MP_P1.00mm_Horizontal | 1 | ESC
22 | J2 | PinHeader_2x03_P2.54mm_Vertical | 1 | Debug
23 | J3, J4 | JST_SH_SM02B-SRSS-TB_1x02-1MP_P1.00mm_Horizontal | 2 | PWR
24 | J5 | JST_SH_SM06B-SRSS-TB_1x06-1MP_P1.00mm_Horizontal | 1 | IMU
25 | J6 | JST_SH_SM06B-SRSS-TB_1x06-1MP_P1.00mm_Horizontal | 1 | SPI1_IMU
26 | J7 | JST_SH_SM05B-SRSS-TB_1x05-1MP_P1.00mm_Horizontal | 1 | BAR
27 | J8 | JST_SH_SM05B-SRSS-TB_1x05-1MP_P1.00mm_Horizontal | 1 | SPI1_BAR
28 | J9 | JST_SH_SM04B-SRSS-TB_1x04-1MP_P1.00mm_Horizontal | 1 | MAG
29 | J10 | JST_SH_SM04B-SRSS-TB_1x04-1MP_P1.00mm_Horizontal | 1 | SPI2
30 | J11 | JST_SH_SM03B-SRSS-TB_1x03-1MP_P1.00mm_Horizontal | 1 | GPS
31 | J12 | JST_SH_SM03B-SRSS-TB_1x03-1MP_P1.00mm_Horizontal | 1 | UART1
32 | J13 | HRS_UFL_R_SMT | 1 | U.FL_R_SMT
33 | J14 | EDAC_690-005-299-043 | 1 | USB_B_Mini
34 | J15 | RFSOLUTIONS_CON-SMA-EDGE-S | 1 | CON-SMA-EDGE-S
35 | L1 | L_0805_2012Metric | 1 | 47n
36 | L2 | L_0805_2012Metric | 1 | 15u
37 | R1 | R_0805_2012Metric | 1 | 10k
38 | R2, R3, R4, R7 | R_0805_2012Metric | 4 | 1k5
39 | R5, R11 | R_0805_2012Metric | 2 | 1k
40 | R6 | R_0805_2012Metric | 1 | R_US
41 | R8 | R_0805_2012Metric | 1 | 88k7
42 | R9 | R_0805_2012Metric | 1 | 22k1
43 | R10 | R_0805_2012Metric | 1 | 5k
44 | R12 | R_0402_1005Metric | 1 | 22k
45 | R13 | R_0402_1005Metric | 1 | 1M
46 | SW1 | SW_SPST_TL3305A | 1 | NRST
47 | SW2 | SW_SPDT_PCM12 | 1 | BOOT0
48 | SW3 | SW_SPDT_PCM12 | 1 | VSEL
49 | U1 | LQFP-64_10x10mm_P0.5mm | 1 | STM32F446RCTx
50 | U2 | IIS2MDCTR | 1 | IIS2MDCTR
51 | U3 | ATGM336H | 1 | ATGM336H
52 | U4 | LSM6DS3TR | 1 | LSM6DS3TR-C
53 | U5 | ST_HLGA-10_2.5x2.5mm_P0.6mm_LayoutBorder3x2y | 1 | LPS25HB
54 | U6 | SOT-23-5 | 1 | AP2112K-3.3
55 | U7 | SOT-23-6 | 1 | LMR50410
56 | U8 | SOT-723 | 1 | ~
57 | U9 | QFN-20-1EP_4x4mm_P0.5mm_EP2.5x2.5mm | 1 | nRF24L01P
58 | Y1 | XTAL_ABM3-16.000MHZ-D2Y-T | 1 | 8MHz
59 | Y2 | XTAL_ABM8AIG-16.000MHZ-12-2Z-T3 | 1 | 16MHz

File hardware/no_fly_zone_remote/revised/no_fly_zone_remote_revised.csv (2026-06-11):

Id | Designator | Footprint | Quantity | Designation | Supplier and ref
1 | C1, C2, C7, C8, C12, C19, C20 | C_0805_2012Metric | 7 | 100n
2 | C3, C4, C11 | C_0805_2012Metric | 3 | 1u
3 | C5, C6, C9 | C_0805_2012Metric | 3 | 10u
4 | C10 | C_0805_2012Metric | 1 | 10n
5 | C13 | C_0402_1005Metric | 1 | 10n
6 | C14 | C_0402_1005Metric | 1 | 1n
7 | C15 | C_0402_1005Metric | 1 | 2n2
8 | C16 | C_0402_1005Metric | 1 | 33n
9 | C17, C18 | C_0402_1005Metric | 2 | 22p
10 | D1 | LED_0805_2012Metric | 1 | RED
11 | D2, D3 | DO-219AD_VIS | 2 | MSP3V3
12 | D4 | LED_0805_2012Metric | 1 | FULL
13 | D5 | LED_0805_2012Metric | 1 | CHARGING
14 | D6 | LED_0805_2012Metric | 1 | GREEN
15 | FB1 | R_0805_2012Metric | 1 | MPZ2012S601AT000
16 | FL1 | FIL_2450BM14A0002T | 1 | 2450BM14A0002T
17 | J1 | JST_PH_S2B-PH-K_1x02_P2.00mm_Horizontal | 1 | VBAT
18 | J2 | EDAC_690-005-299-043 | 1 | USB_B_Mini
19 | J3 | PinHeader_1x06_P2.54mm_Vertical | 1 | SWD
20 | J4 | RFSOLUTIONS_CON-SMA-EDGE-S | 1 | CON-SMA-EDGE-S
21 | R1, R2, R5, R6, R9 | R_0805_2012Metric | 5 | 1k5
22 | R3, R4 | R_0805_2012Metric | 2 | 50k
23 | R7 | R_0805_2012Metric | 1 | 6k
24 | R8 | R_0805_2012Metric | 1 | 10K
25 | R10 | R_0402_1005Metric | 1 | 22k
26 | R11, R12, R13, R15, R16 | R_0805_2012Metric | 5 | 10k
27 | R14 | R_0402_1005Metric | 1 | 1M
28 | S1 | XDCR_PEC11R-4220F-S0024 | 1 | PEC11R-4220F-S0024
29 | SW1 | SW_SPDT_PCM12 | 1 | ON/OFF
30 | SW2 | SW_SPST_TL3305A | 1 | NRST
31 | SW3 | SW_SPDT_PCM12 | 1 | BOOT0
32 | U1 | SOT-23-5 | 1 | AP2112K-3.3
33 | U2 | TPS2115A-TSSOP-8 | 1 | TPS2115
34 | U3 | SOIC-8-1EP_3.9x4.9mm_P1.27mm_EP2.41x3.3mm | 1 | TP4056-42-ESOP8
35 | U4 | QFN-32-1EP_5x5mm_P0.5mm_EP3.45x3.45mm | 1 | STM32L432KCUx
36 | U5 | PinHeader_1x04_P2.54mm_Vertical | 1 | ~
37 | U6 | QFN-20-1EP_4x4mm_P0.5mm_EP2.5x2.5mm | 1 | nRF24L01P
38 | U7, U8 | PS5_Joystick | 2 | PS5
39 | Y1 | XTAL_ABM8AIG-16.000MHZ-12-2Z-T3 | 1 | 16MHz

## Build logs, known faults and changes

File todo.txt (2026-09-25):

no_fly_zone_remote
1. how to speed up loop time
2. add handling if not receiving ack packets
3. add ssd1306_busy() function and do not attempt to create oled buffer if busy
4. add watchdog
5. add delay_ms and get_ms_tick replacing HAL_GetTick() (make sure timer is 32-bits)
6. add a joystick tuning page (page 2?)

no_fly_zone
Note. worst case scenario loop time is below 200us
1. Determine tau_z direction based on motor placement/direction
2. attempt recovery for failure to init
3. place torque commands into matrix for cleaner math
4. test to see why data is being sent faster than 200Hz?

stm32_lib
1. check for null pointers in delay_ms and delay_us (nrf)
2. dynamic memory allocation for dshot?
3. add comments to all libraries
4. clean up encoder implementation --> messy, hard to read
5. make public
6. Modify all libraries to separate API calls from physical layer calls
7. Add functionality for DMA, polling/blocking, EXTI, etc to libraries
8. Change universal return type to status_t
9. Change all structs *params to *_handle_t
10. Rename all private variables in struct starting with _
11. determine whether to use dynamic allocation or allow user to give presized array for pointers for buffers
12. change all functions to have form part_function() instead of genericName_function()
13. add input output functionality comments to all functions
14. specific enums instead of generic
15. user owns memory and passes it to struct
16. use const as much as possible
17. update comments on function input/output
18. static asserts
19. static size config for dshot
20. stdbool.h for Boolean
21. check for init in functions 
22. units in variable names

Hardware
1. Determine and set motor CW/CCW directions
2. Verify VBAT_SENSE and CURR_SENSE ranges on test board

Github
1. Add BOM for both remote and flight controller
2. Add more detail and pictures to READMEs

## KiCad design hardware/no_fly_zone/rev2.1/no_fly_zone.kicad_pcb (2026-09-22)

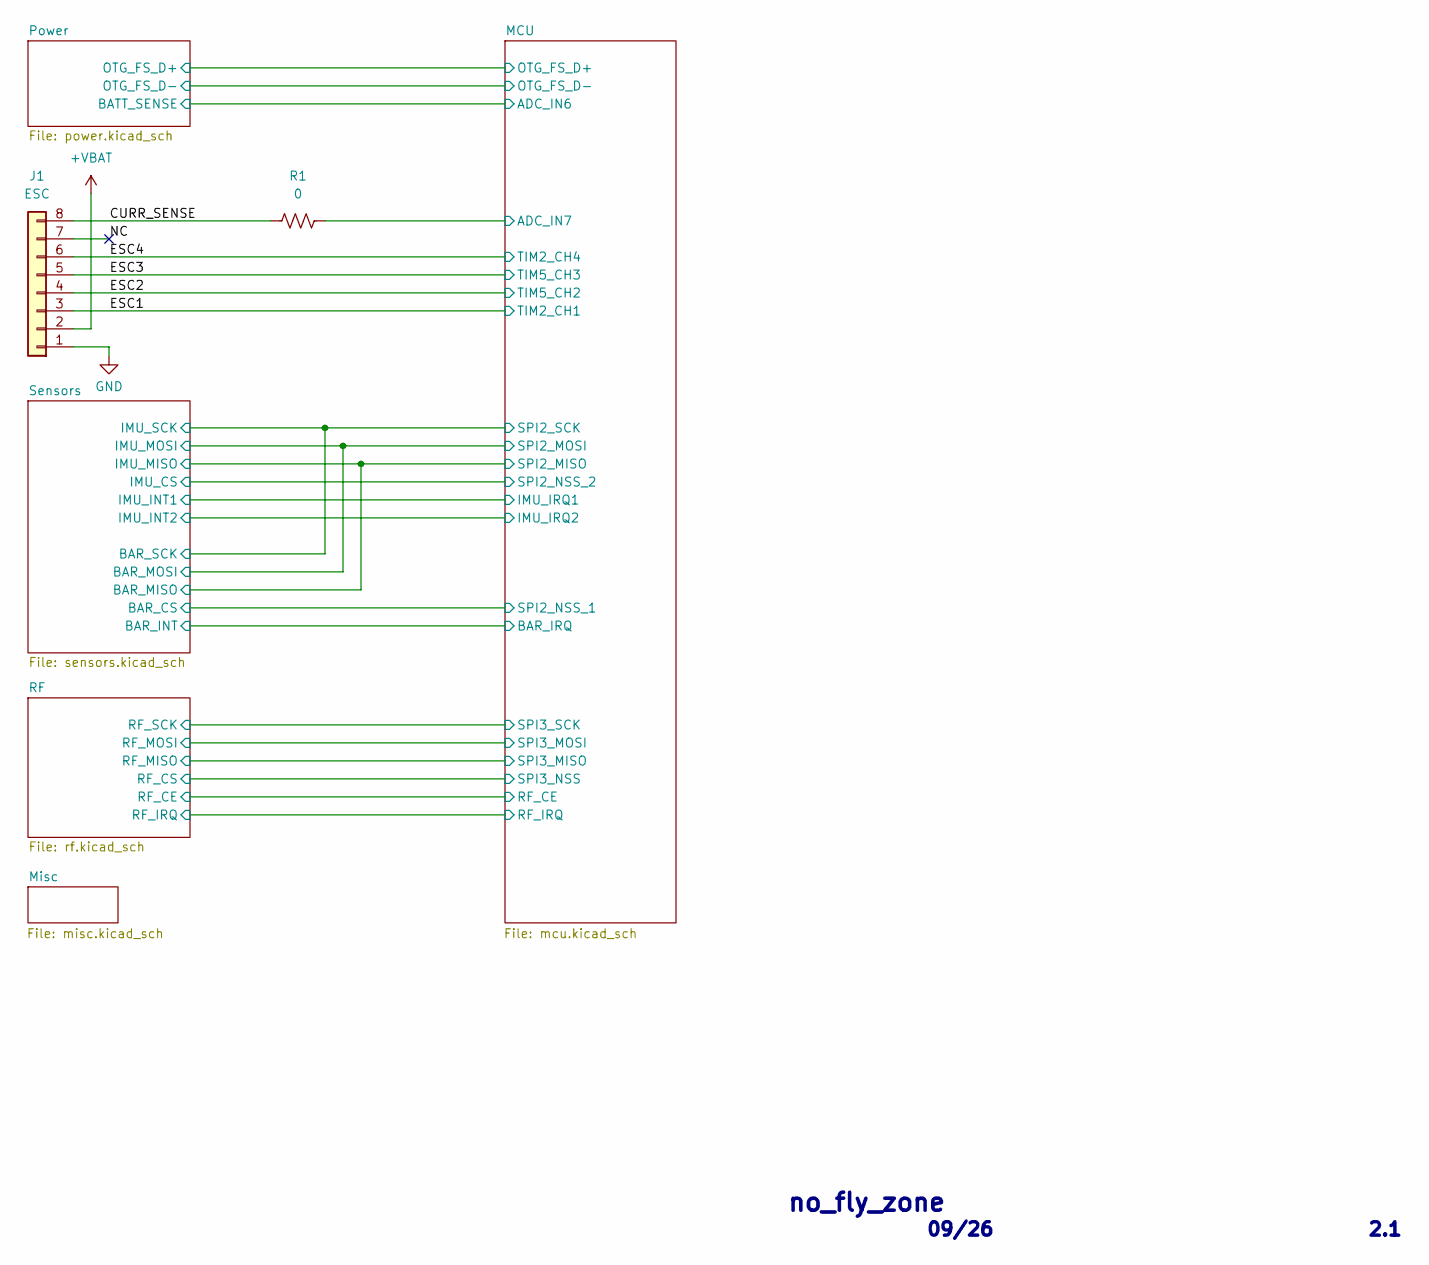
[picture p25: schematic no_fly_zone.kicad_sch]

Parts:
J1: ESC; JST_SH_SM08B-SRSS-TB_1x08-1MP_P1.00mm_Horizontal
R1: 0; R_0603_1608Metric

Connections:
+VBAT: J1.2; also elsewhere on the board
/CURR_SENSE: J1.8, R1.1
/ESC1: J1.3; also elsewhere on the board
/ESC2: J1.4; also elsewhere on the board
/ESC3: J1.5; also elsewhere on the board
/ESC4: J1.6; also elsewhere on the board
/MCU/ADC_IN7: R1.2; also elsewhere on the board
/NC: J1.7
GND: J1.1; also elsewhere on the board

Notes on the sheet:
no_fly_zone
2.1
09/26

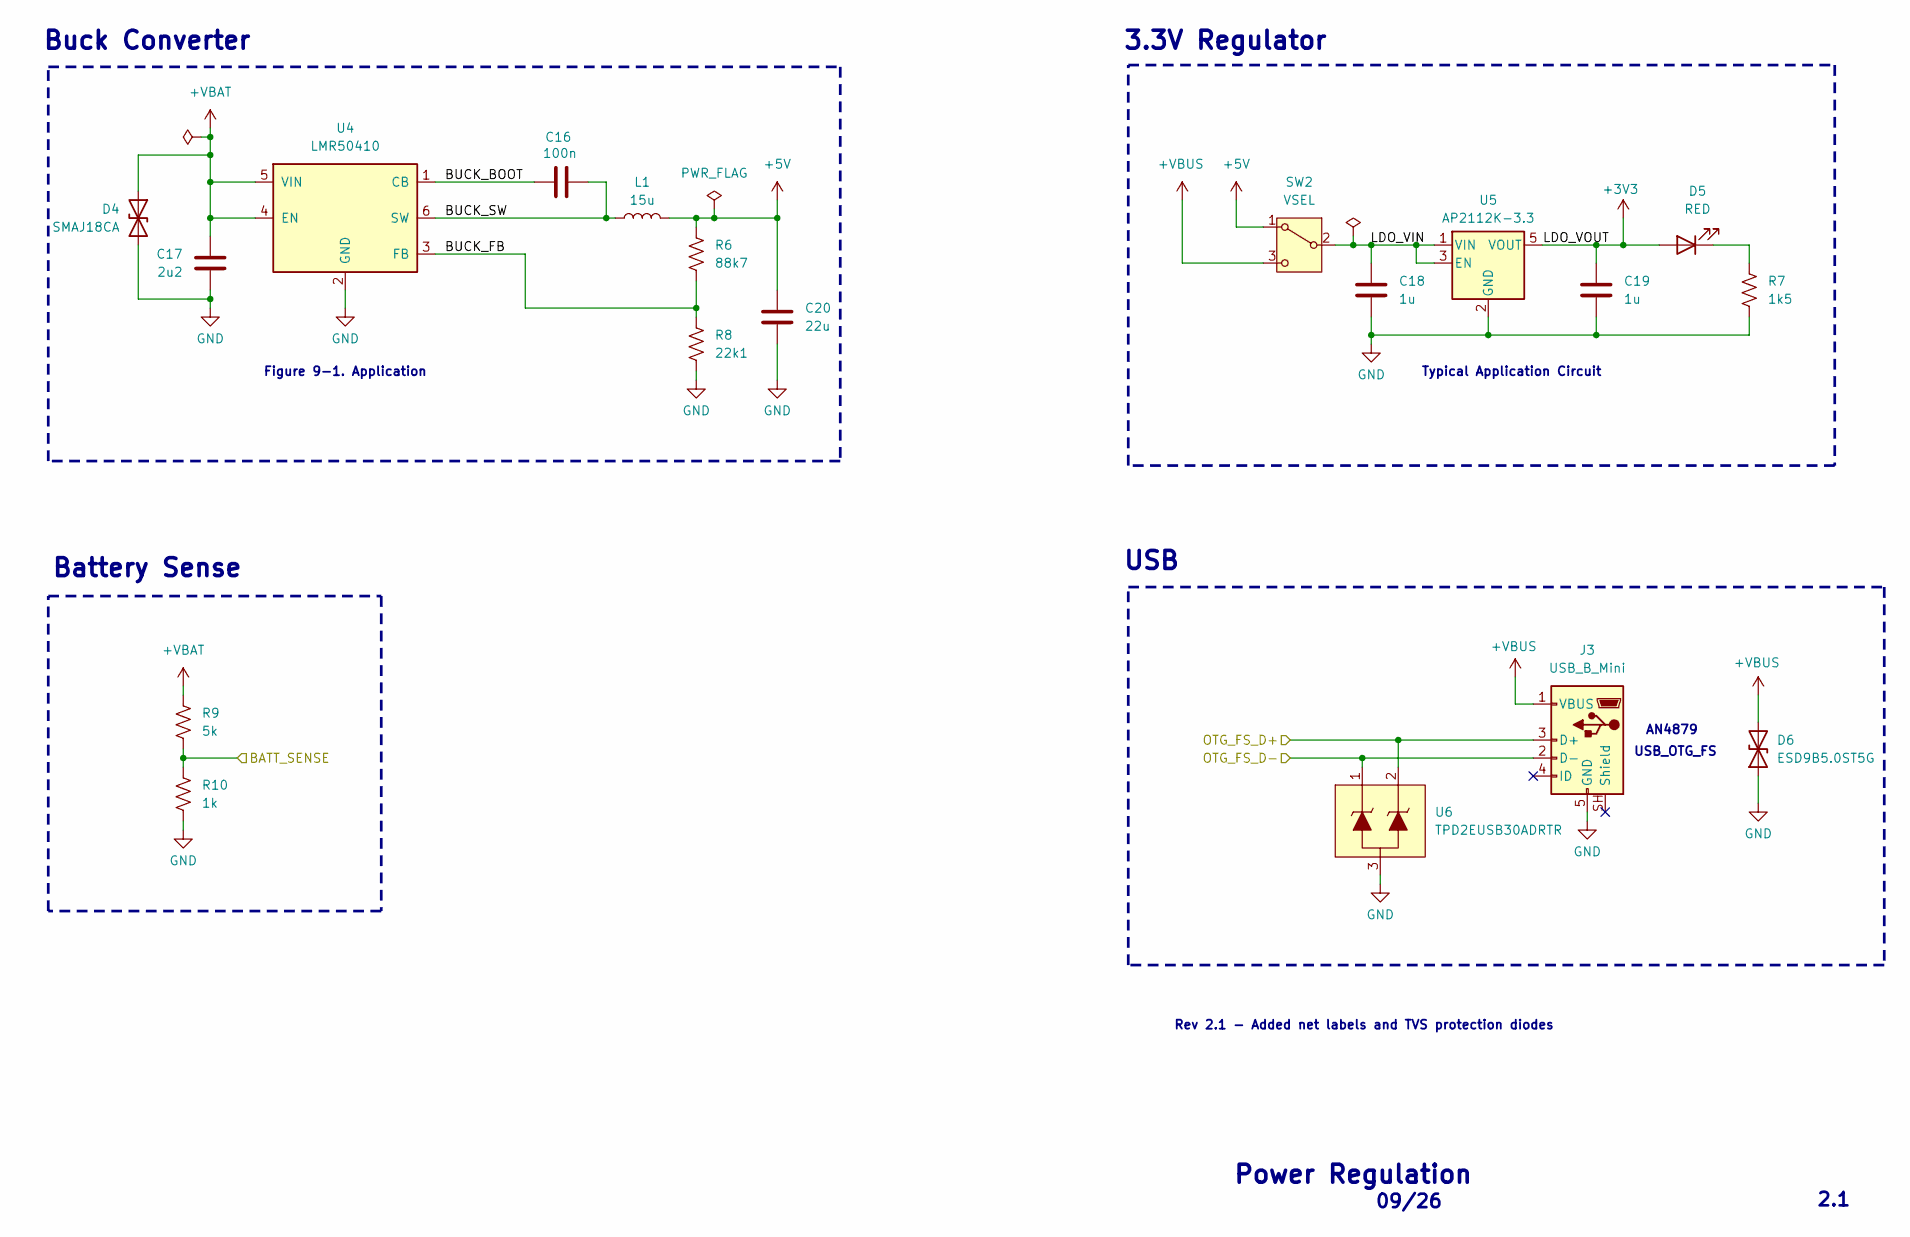
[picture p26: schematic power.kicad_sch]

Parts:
C16: 100n; C_0603_1608Metric
C17: 2u2; C_0603_1608Metric
C18, C19: 1u; C_0603_1608Metric
C20: 22u; C_0805_2012Metric
D4: SMAJ18CA; D_SMA
D5: RED; LED_0603_1608Metric
D6: ESD9B5.0ST5G; D_SOD-923
J3: USB_B_Mini; EDAC_690-005-299-043
L1: 15u; L_0805_2012Metric
R6: 88k7; R_0805_2012Metric
R7: 1k5; R_0603_1608Metric
R8: 22k1; R_0805_2012Metric
R9: 5k; R_0805_2012Metric
R10: 1k; R_0805_2012Metric
SW2: VSEL; SW_SPDT_PCM12
U4: LMR50410; SOT-23-6
U5: AP2112K-3.3; SOT-23-5
U6: SOT-723

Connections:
+3V3: C19.1, D5.2 (A), U5.5 (VOUT); also elsewhere on the board
+5V: C20.1, L1.2, R6.1, SW2.1 (A)
+VBAT: C17.1, D4.1 (A1), R9.1, U4.4 (EN), U4.5 (VIN); also elsewhere on the board
+VBUS: D6.2 (A2), J3.1 (VBUS), SW2.3 (C)
/MCU/ADC_IN6: R9.2, R10.1; also elsewhere on the board
/MCU/OTG_FS_D+: J3.3 (D+), U6.2; also elsewhere on the board
/MCU/OTG_FS_D-: J3.2 (D-), U6.1; also elsewhere on the board
/Power/BUCK_BOOT: C16.1, U4.1 (CB)
/Power/BUCK_FB: R6.2, R8.1, U4.3 (FB)
/Power/BUCK_SW: C16.2, L1.1, U4.6 (SW)
/Power/LDO_VIN: C18.1, SW2.2 (B), U5.1 (VIN), U5.3 (EN)
GND: C17.2, C18.2, C19.2, C20.2, D4.2 (A2), D6.1 (A1), J3.5 (GND), R7.2, R8.2, R10.2, U4.2 (GND), U5.2 (GND), U6.3; also elsewhere on the board
unnamed: D5.1 (K), R7.1

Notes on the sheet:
USB
Figure 9-1. Application
USB_OTG_FS
09/26
AN4879
Buck Converter
Power Regulation
3.3V Regulator
Rev 2.1 - Added net labels and TVS protection diodes
2.1
Battery Sense
Typical Application Circuit

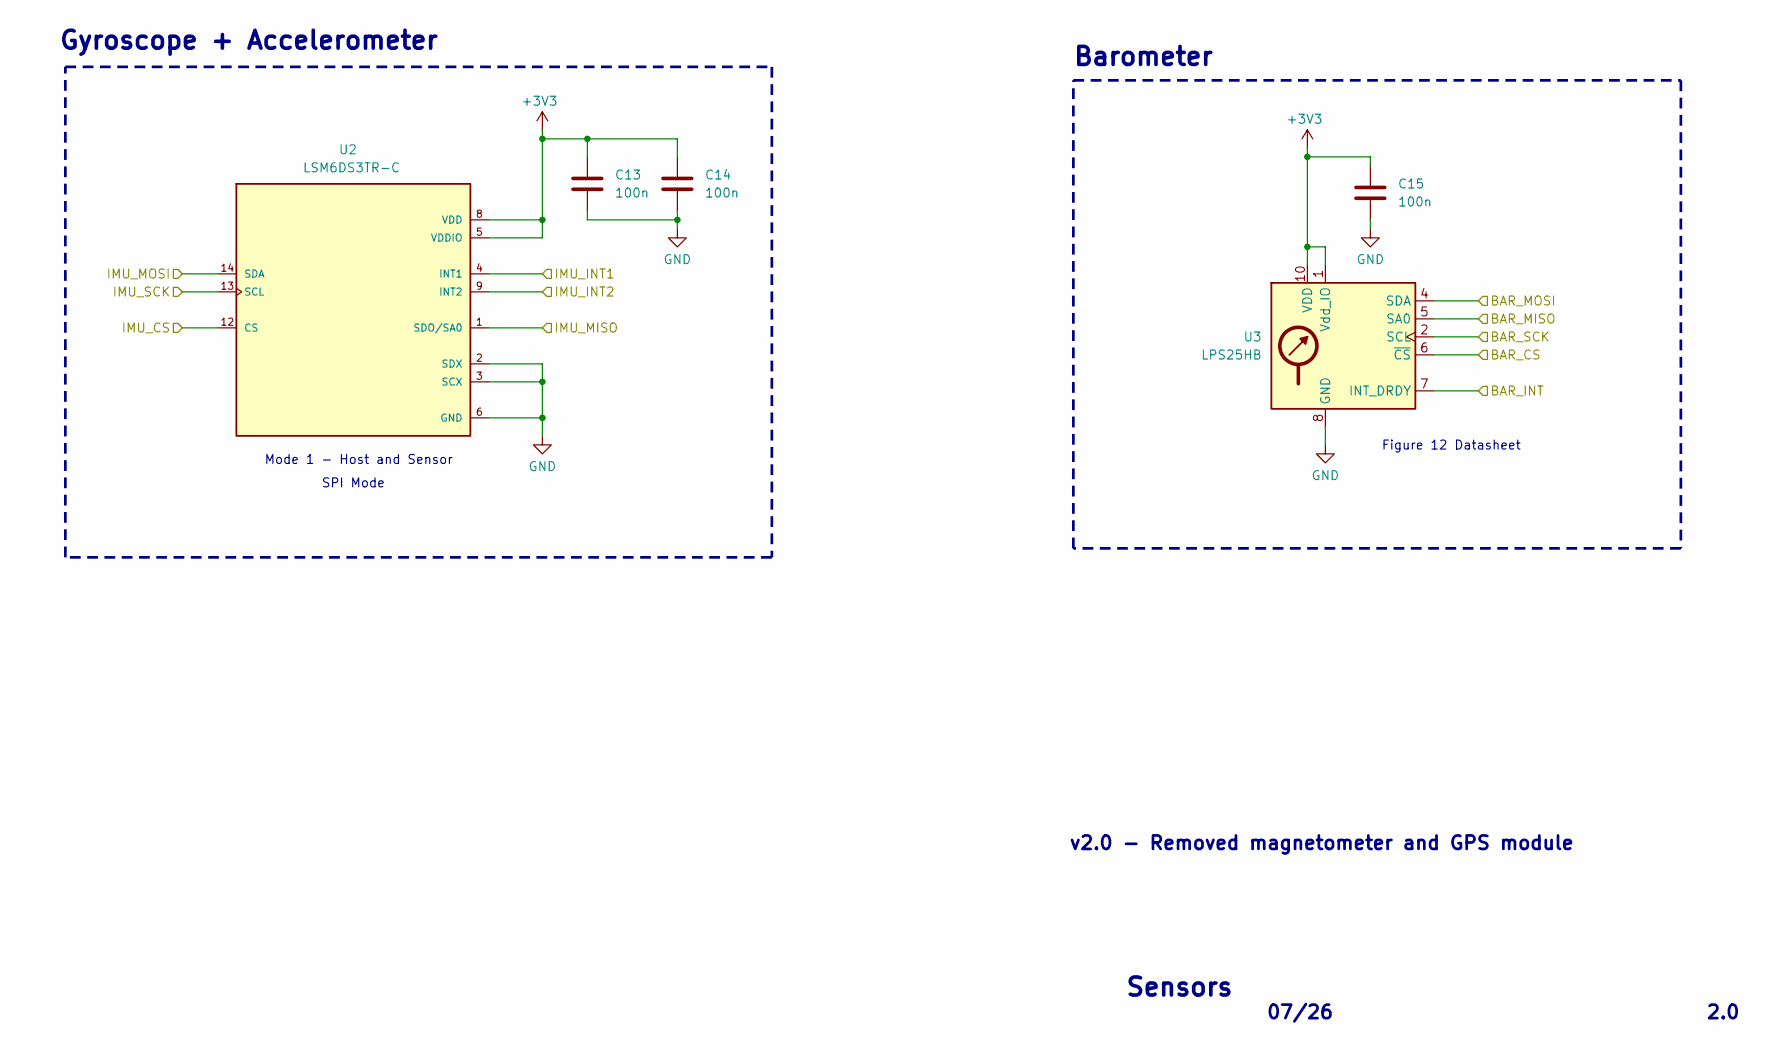
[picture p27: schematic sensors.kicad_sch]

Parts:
C13, C14, C15: 100n; C_0603_1608Metric
U2: LSM6DS3TR-C; LSM6DS3TR
U3: LPS25HB; ST_HLGA-10_2.5x2.5mm_P0.6mm_LayoutBorder3x2y

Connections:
+3V3: C13.1, C14.1, C15.1, U2.5 (VDDIO), U2.8 (VDD), U3.1 (Vdd_IO), U3.10 (VDD); also elsewhere on the board
/MCU/BAR_IRQ: U3.7 (INT_DRDY); also elsewhere on the board
/MCU/IMU_IRQ1: U2.4 (INT1); also elsewhere on the board
/MCU/IMU_IRQ2: U2.9 (INT2); also elsewhere on the board
/MCU/SPI2_MISO: U2.1 (SDO/SA0), U3.5 (SA0); also elsewhere on the board
/MCU/SPI2_MOSI: U2.14 (SDA), U3.4 (SDA); also elsewhere on the board
/MCU/SPI2_NSS_1: U3.6 (~CS); also elsewhere on the board
/MCU/SPI2_NSS_2: U2.12 (CS); also elsewhere on the board
/MCU/SPI2_SCK: U2.13 (SCL), U3.2 (SCL); also elsewhere on the board
GND: C13.2, C14.2, C15.2, U2.2 (SDX), U2.3 (SCX), U2.6 (GND), U2.7 (GND), U3.3 (GND), U3.8 (GND), U3.9 (GND); also elsewhere on the board

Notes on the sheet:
SPI Mode
Barometer
07/26
Mode 1 - Host and Sensor
2.0
Gyroscope + Accelerometer
Figure 12 Datasheet
v2.0 - Removed magnetometer and GPS module
Sensors

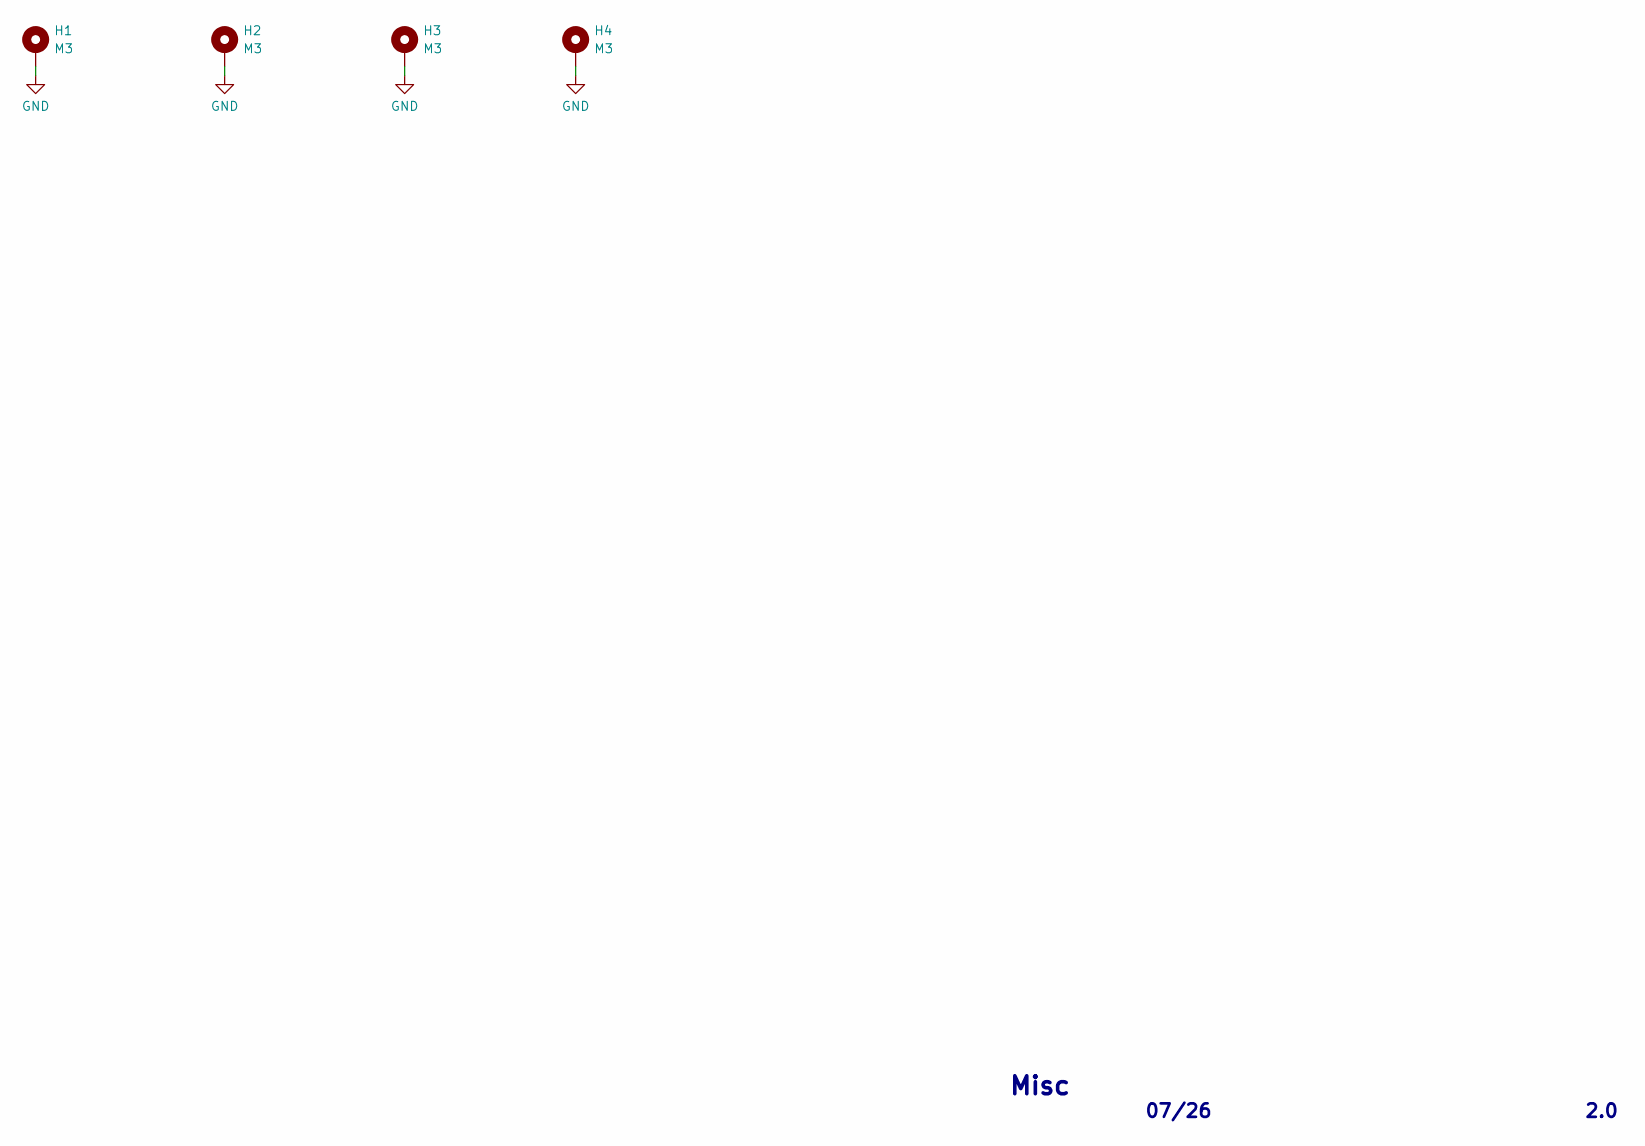
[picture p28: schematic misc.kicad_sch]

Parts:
H1, H2, H3, H4: M3; MountingHole_3.2mm_M3_DIN965_Pad

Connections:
GND: H1.1 (1_1), H2.1 (1_1), H3.1 (1_1), H4.1 (1_1); also elsewhere on the board

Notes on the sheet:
07/26
2.0
Misc

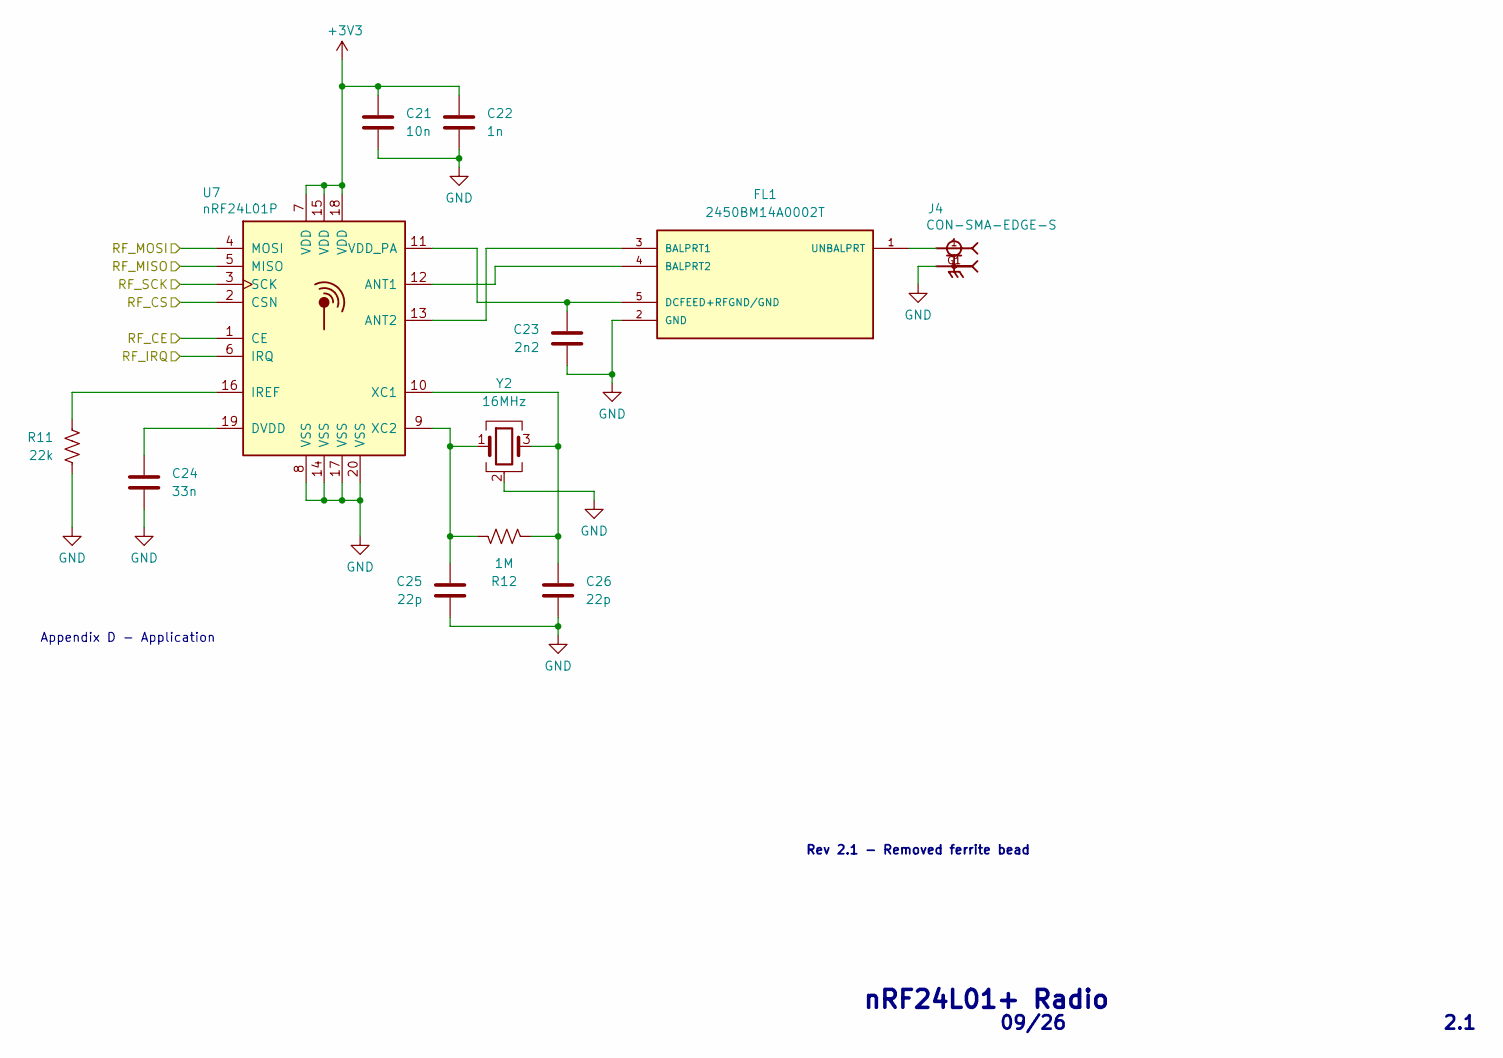
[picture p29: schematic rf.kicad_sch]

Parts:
C21: 10n; C_0402_1005Metric
C22: 1n; C_0402_1005Metric
C23: 2n2; C_0402_1005Metric
C24: 33n; C_0402_1005Metric
C25, C26: 22p; C_0402_1005Metric
FL1: 2450BM14A0002T; FIL_2450BM14A0002T
J4: CON-SMA-EDGE-S; RFSOLUTIONS_CON-SMA-EDGE-S
R11: 22k; R_0402_1005Metric
R12: 1M; R_0402_1005Metric
U7: nRF24L01P; QFN-20-1EP_4x4mm_P0.5mm_EP2.5x2.5mm
Y2: 16MHz; XTAL_ABM8AIG-16.000MHZ-12-2Z-T3

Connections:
+3V3: C21.1, C22.1, U7.7 (VDD), U7.15 (VDD), U7.18 (VDD); also elsewhere on the board
/MCU/RF_CE: U7.1 (CE); also elsewhere on the board
/MCU/RF_IRQ: U7.6 (IRQ); also elsewhere on the board
/MCU/SPI3_MISO: U7.5 (MISO); also elsewhere on the board
/MCU/SPI3_MOSI: U7.4 (MOSI); also elsewhere on the board
/MCU/SPI3_NSS: U7.2 (CSN); also elsewhere on the board
/MCU/SPI3_SCK: U7.3 (SCK); also elsewhere on the board
GND: C21.2, C22.2, C23.2, C24.2, C25.2, C26.2, FL1.2 (GND), J4.G1, J4.G2, J4.G3, J4.G4, R11.2, U7.8 (VSS), U7.14 (VSS), U7.17 (VSS), U7.20 (VSS), Y2.2 (G), Y2.4 (G); also elsewhere on the board
unnamed: FL1.3 (BALPRT1), U7.13 (ANT2)
unnamed: FL1.4 (BALPRT2), U7.12 (ANT1)
unnamed: C23.1, FL1.5 (DCFEED+RFGND/GND), U7.11 (VDD_PA)
unnamed: FL1.1 (UNBALPRT), J4.1
unnamed: C24.1, U7.19 (DVDD)
unnamed: R11.1, U7.16 (IREF)
unnamed: C26.1, R12.1, U7.10 (XC1), Y2.3
unnamed: C25.1, R12.2, U7.9 (XC2), Y2.1

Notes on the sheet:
Appendix D - Application
Rev 2.1 - Removed ferrite bead
2.1
nRF24L01+ Radio
09/26

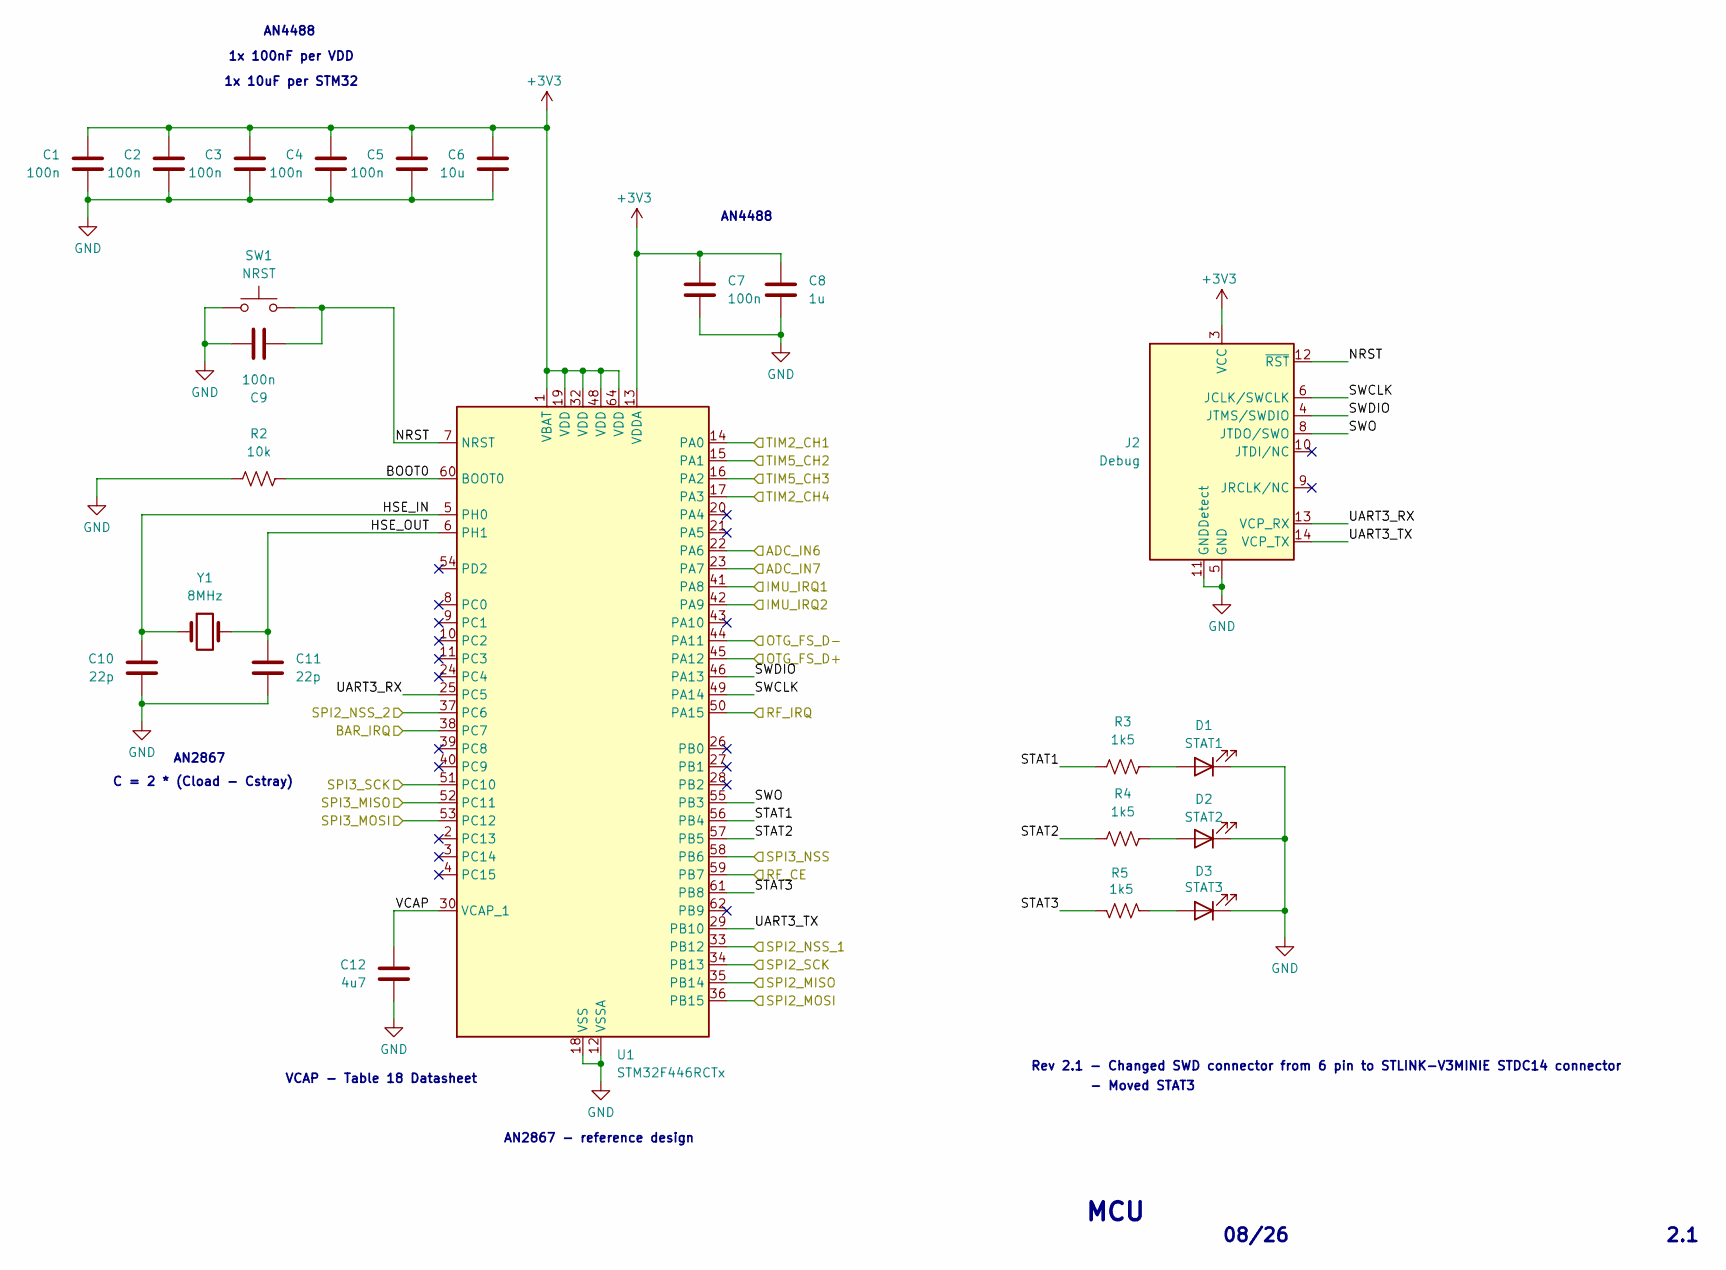
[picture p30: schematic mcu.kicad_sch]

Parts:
C1, C2, C3, C4, C5, C7, C9: 100n; C_0603_1608Metric
C6: 10u; C_0603_1608Metric
C8: 1u; C_0603_1608Metric
C10, C11: 22p; C_0603_1608Metric
C12: 4u7; C_0603_1608Metric
D1: STAT1; LED_0603_1608Metric
D2: STAT2; LED_0603_1608Metric
D3: STAT3; LED_0603_1608Metric
J2: Debug; SAMTEC_FTSH-107-01-L-DV-K-A
R2: 10k; R_0603_1608Metric
R3, R4, R5: 1k5; R_0603_1608Metric
SW1: NRST; SW_SPST_TL3305A
U1: STM32F446RCTx; LQFP-64_10x10mm_P0.5mm
Y1: 8MHz; XTAL_ABM3-16.000MHZ-D2Y-T

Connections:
+3V3: C1.1, C2.1, C3.1, C4.1, C5.1, C6.1, C7.1, C8.1, J2.3 (VCC), U1.1 (VBAT), U1.13 (VDDA), U1.19 (VDD), U1.32 (VDD), U1.48 (VDD), U1.64 (VDD); also elsewhere on the board
/ESC1: U1.14 (PA0); also elsewhere on the board
/ESC2: U1.15 (PA1); also elsewhere on the board
/ESC3: U1.16 (PA2); also elsewhere on the board
/ESC4: U1.17 (PA3); also elsewhere on the board
/MCU/ADC_IN6: U1.22 (PA6); also elsewhere on the board
/MCU/ADC_IN7: U1.23 (PA7); also elsewhere on the board
/MCU/BAR_IRQ: U1.38 (PC7); also elsewhere on the board
/MCU/BOOT0: R2.2, U1.60 (BOOT0)
/MCU/HSE_IN: C10.1, U1.5 (PH0), Y1.1
/MCU/HSE_OUT: C11.1, U1.6 (PH1), Y1.2
/MCU/IMU_IRQ1: U1.41 (PA8); also elsewhere on the board
/MCU/IMU_IRQ2: U1.42 (PA9); also elsewhere on the board
/MCU/NRST: C9.1, J2.12 (~RST), SW1.2, U1.7 (NRST)
/MCU/OTG_FS_D+: U1.45 (PA12); also elsewhere on the board
/MCU/OTG_FS_D-: U1.44 (PA11); also elsewhere on the board
/MCU/RF_CE: U1.59 (PB7); also elsewhere on the board
/MCU/RF_IRQ: U1.50 (PA15); also elsewhere on the board
/MCU/SPI2_MISO: U1.35 (PB14); also elsewhere on the board
/MCU/SPI2_MOSI: U1.36 (PB15); also elsewhere on the board
/MCU/SPI2_NSS_1: U1.33 (PB12); also elsewhere on the board
/MCU/SPI2_NSS_2: U1.37 (PC6); also elsewhere on the board
/MCU/SPI2_SCK: U1.34 (PB13); also elsewhere on the board
/MCU/SPI3_MISO: U1.52 (PC11); also elsewhere on the board
/MCU/SPI3_MOSI: U1.53 (PC12); also elsewhere on the board
/MCU/SPI3_NSS: U1.58 (PB6); also elsewhere on the board
/MCU/SPI3_SCK: U1.51 (PC10); also elsewhere on the board
/MCU/STAT1: R3.1, U1.56 (PB4)
/MCU/STAT2: R4.1, U1.57 (PB5)
/MCU/STAT3: R5.2, U1.61 (PB8)
/MCU/SWCLK: J2.6 (JCLK/SWCLK), U1.49 (PA14)
/MCU/SWDIO: J2.4 (JTMS/SWDIO), U1.46 (PA13)
/MCU/SWO: J2.8 (JTDO/SWO), U1.55 (PB3)
/MCU/UART3_RX: J2.13 (VCP_RX), U1.25 (PC5)
/MCU/UART3_TX: J2.14 (VCP_TX), U1.29 (PB10)
/MCU/VCAP: C12.1, U1.30 (VCAP_1)
GND: C1.2, C2.2, C3.2, C4.2, C5.2, C6.2, C7.2, C8.2, C9.2, C10.2, C11.2, C12.2, D1.1 (K), D2.1 (K), D3.1 (K), J2.5 (GND), J2.7 (GND), J2.11 (GNDDetect), R2.1, SW1.1, U1.12 (VSSA), U1.18 (VSS), U1.31 (VSS), U1.47 (VSS), U1.63 (VSS); also elsewhere on the board
unnamed: D1.2 (A), R3.2
unnamed: D2.2 (A), R4.2
unnamed: D3.2 (A), R5.1

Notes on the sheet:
AN4488
1x 100nF per VDD
2.1
MCU
08/26
- Moved STAT3
VCAP - Table 18 Datasheet
Rev 2.1 - Changed SWD connector from 6 pin to STLINK-V3MINIE STDC14 connector
AN2867 - reference design
1x 10uF per STM32
C = 2 * (Cload - Cstray)
AN2867

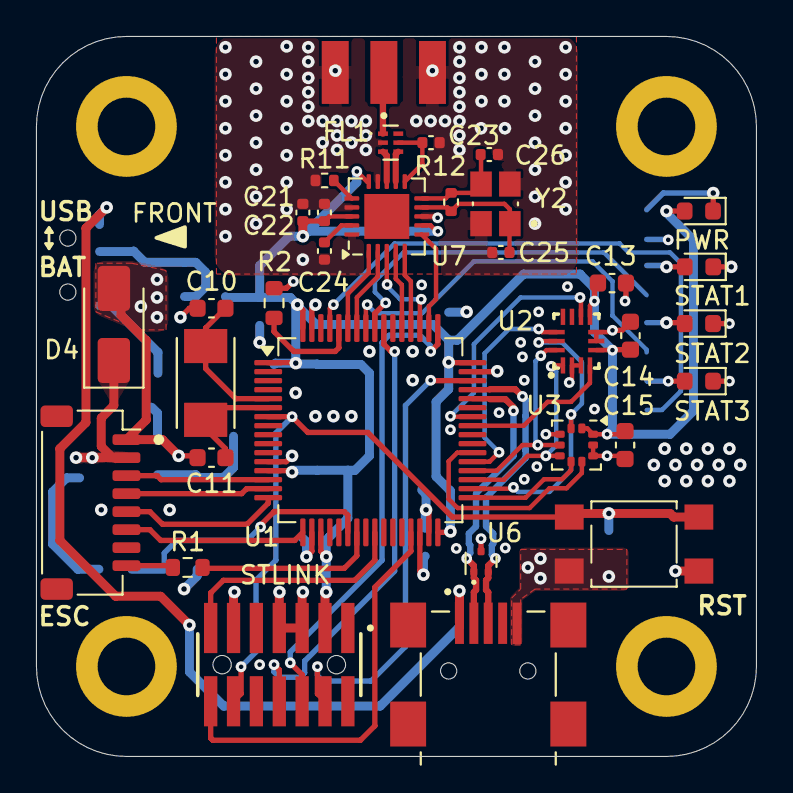
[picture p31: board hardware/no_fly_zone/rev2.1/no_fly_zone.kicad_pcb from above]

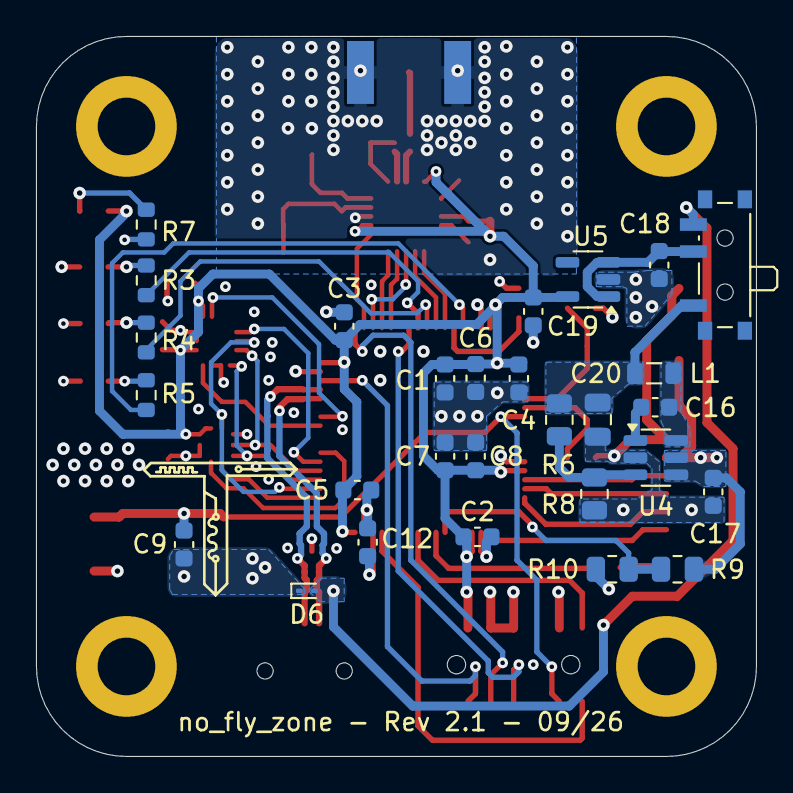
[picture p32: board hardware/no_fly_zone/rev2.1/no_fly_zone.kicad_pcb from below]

Board: 4 copper layers, 40.0 x 40.0 mm, 65 parts (28 on the bottom side), 57 nets.

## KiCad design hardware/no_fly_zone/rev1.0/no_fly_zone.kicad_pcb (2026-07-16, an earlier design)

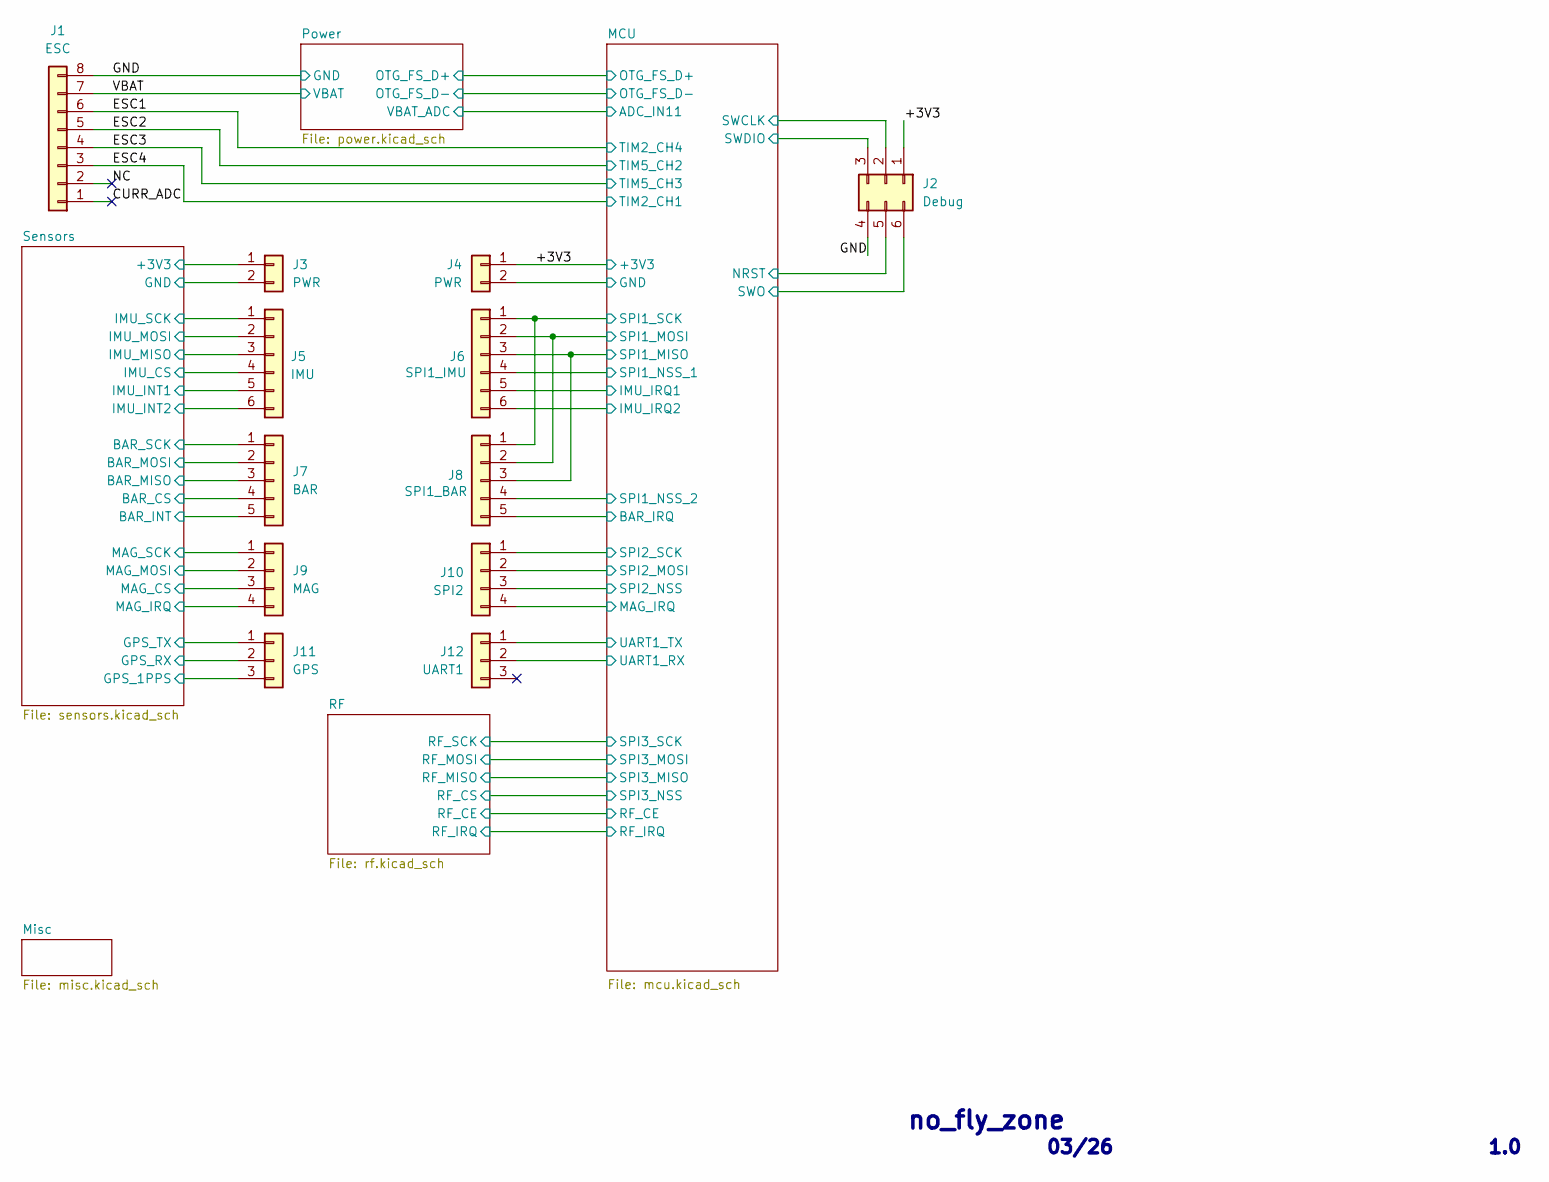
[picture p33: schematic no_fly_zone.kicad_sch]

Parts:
J1: ESC; JST_SH_SM08B-SRSS-TB_1x08-1MP_P1.00mm_Horizontal
J2: Debug; PinHeader_2x03_P2.54mm_Vertical
J3, J4: PWR; JST_SH_SM02B-SRSS-TB_1x02-1MP_P1.00mm_Horizontal
J5: IMU; JST_SH_SM06B-SRSS-TB_1x06-1MP_P1.00mm_Horizontal
J6: SPI1_IMU; JST_SH_SM06B-SRSS-TB_1x06-1MP_P1.00mm_Horizontal
J7: BAR; JST_SH_SM05B-SRSS-TB_1x05-1MP_P1.00mm_Horizontal
J8: SPI1_BAR; JST_SH_SM05B-SRSS-TB_1x05-1MP_P1.00mm_Horizontal
J9: MAG; JST_SH_SM04B-SRSS-TB_1x04-1MP_P1.00mm_Horizontal
J10: SPI2; JST_SH_SM04B-SRSS-TB_1x04-1MP_P1.00mm_Horizontal
J11: GPS; JST_SH_SM03B-SRSS-TB_1x03-1MP_P1.00mm_Horizontal
J12: UART1; JST_SH_SM03B-SRSS-TB_1x03-1MP_P1.00mm_Horizontal

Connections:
+3V3_MCU: J2.1, J4.1; also elsewhere on the board
+3V3_SENS: J3.1; also elsewhere on the board
/CURR_ADC: J1.1
/ESC1: J1.6; also elsewhere on the board
/ESC2: J1.5; also elsewhere on the board
/ESC3: J1.4; also elsewhere on the board
/ESC4: J1.3; also elsewhere on the board
/MCU/BAR_IRQ: J8.5; also elsewhere on the board
/MCU/IIS2_IRQ: J10.4; also elsewhere on the board
/MCU/IMU_IRQ1: J6.5; also elsewhere on the board
/MCU/IMU_IRQ2: J6.6; also elsewhere on the board
/MCU/NRST: J2.5; also elsewhere on the board
/MCU/SPI1_MISO: J6.3, J8.3; also elsewhere on the board
/MCU/SPI1_MOSI: J6.2, J8.2; also elsewhere on the board
/MCU/SPI1_NSS_1: J6.4; also elsewhere on the board
/MCU/SPI1_NSS_2: J8.4; also elsewhere on the board
/MCU/SPI1_SCK: J6.1, J8.1; also elsewhere on the board
/MCU/SPI2_MOSI: J10.2; also elsewhere on the board
/MCU/SPI2_NSS: J10.3; also elsewhere on the board
/MCU/SPI2_SCK: J10.1; also elsewhere on the board
/MCU/SWCLK: J2.2; also elsewhere on the board
/MCU/SWDIO: J2.3; also elsewhere on the board
/MCU/SWO: J2.6; also elsewhere on the board
/MCU/UART1_RX: J12.2; also elsewhere on the board
/MCU/UART1_TX: J12.1; also elsewhere on the board
/NC: J1.2
/Sensors/BAR_CS: J7.4; also elsewhere on the board
/Sensors/BAR_INT: J7.5; also elsewhere on the board
/Sensors/BAR_MISO: J7.3; also elsewhere on the board
/Sensors/BAR_MOSI: J7.2; also elsewhere on the board
/Sensors/BAR_SCK: J7.1; also elsewhere on the board
/Sensors/GPS_1PPS: J11.3; also elsewhere on the board
/Sensors/GPS_RX: J11.2; also elsewhere on the board
/Sensors/GPS_TX: J11.1; also elsewhere on the board
/Sensors/IMU_CS: J5.4; also elsewhere on the board
/Sensors/IMU_INT1: J5.5; also elsewhere on the board
/Sensors/IMU_INT2: J5.6; also elsewhere on the board
/Sensors/IMU_MISO: J5.3; also elsewhere on the board
/Sensors/IMU_MOSI: J5.2; also elsewhere on the board
/Sensors/IMU_SCK: J5.1; also elsewhere on the board
/Sensors/MAG_CS: J9.3; also elsewhere on the board
/Sensors/MAG_IRQ: J9.4; also elsewhere on the board
/Sensors/MAG_MOSI: J9.2; also elsewhere on the board
/Sensors/MAG_SCK: J9.1; also elsewhere on the board
GND_MCU: J1.8, J2.4, J4.2; also elsewhere on the board
GND_SENS: J3.2; also elsewhere on the board
VBAT: J1.7; also elsewhere on the board

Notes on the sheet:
no_fly_zone
1.0
03/26

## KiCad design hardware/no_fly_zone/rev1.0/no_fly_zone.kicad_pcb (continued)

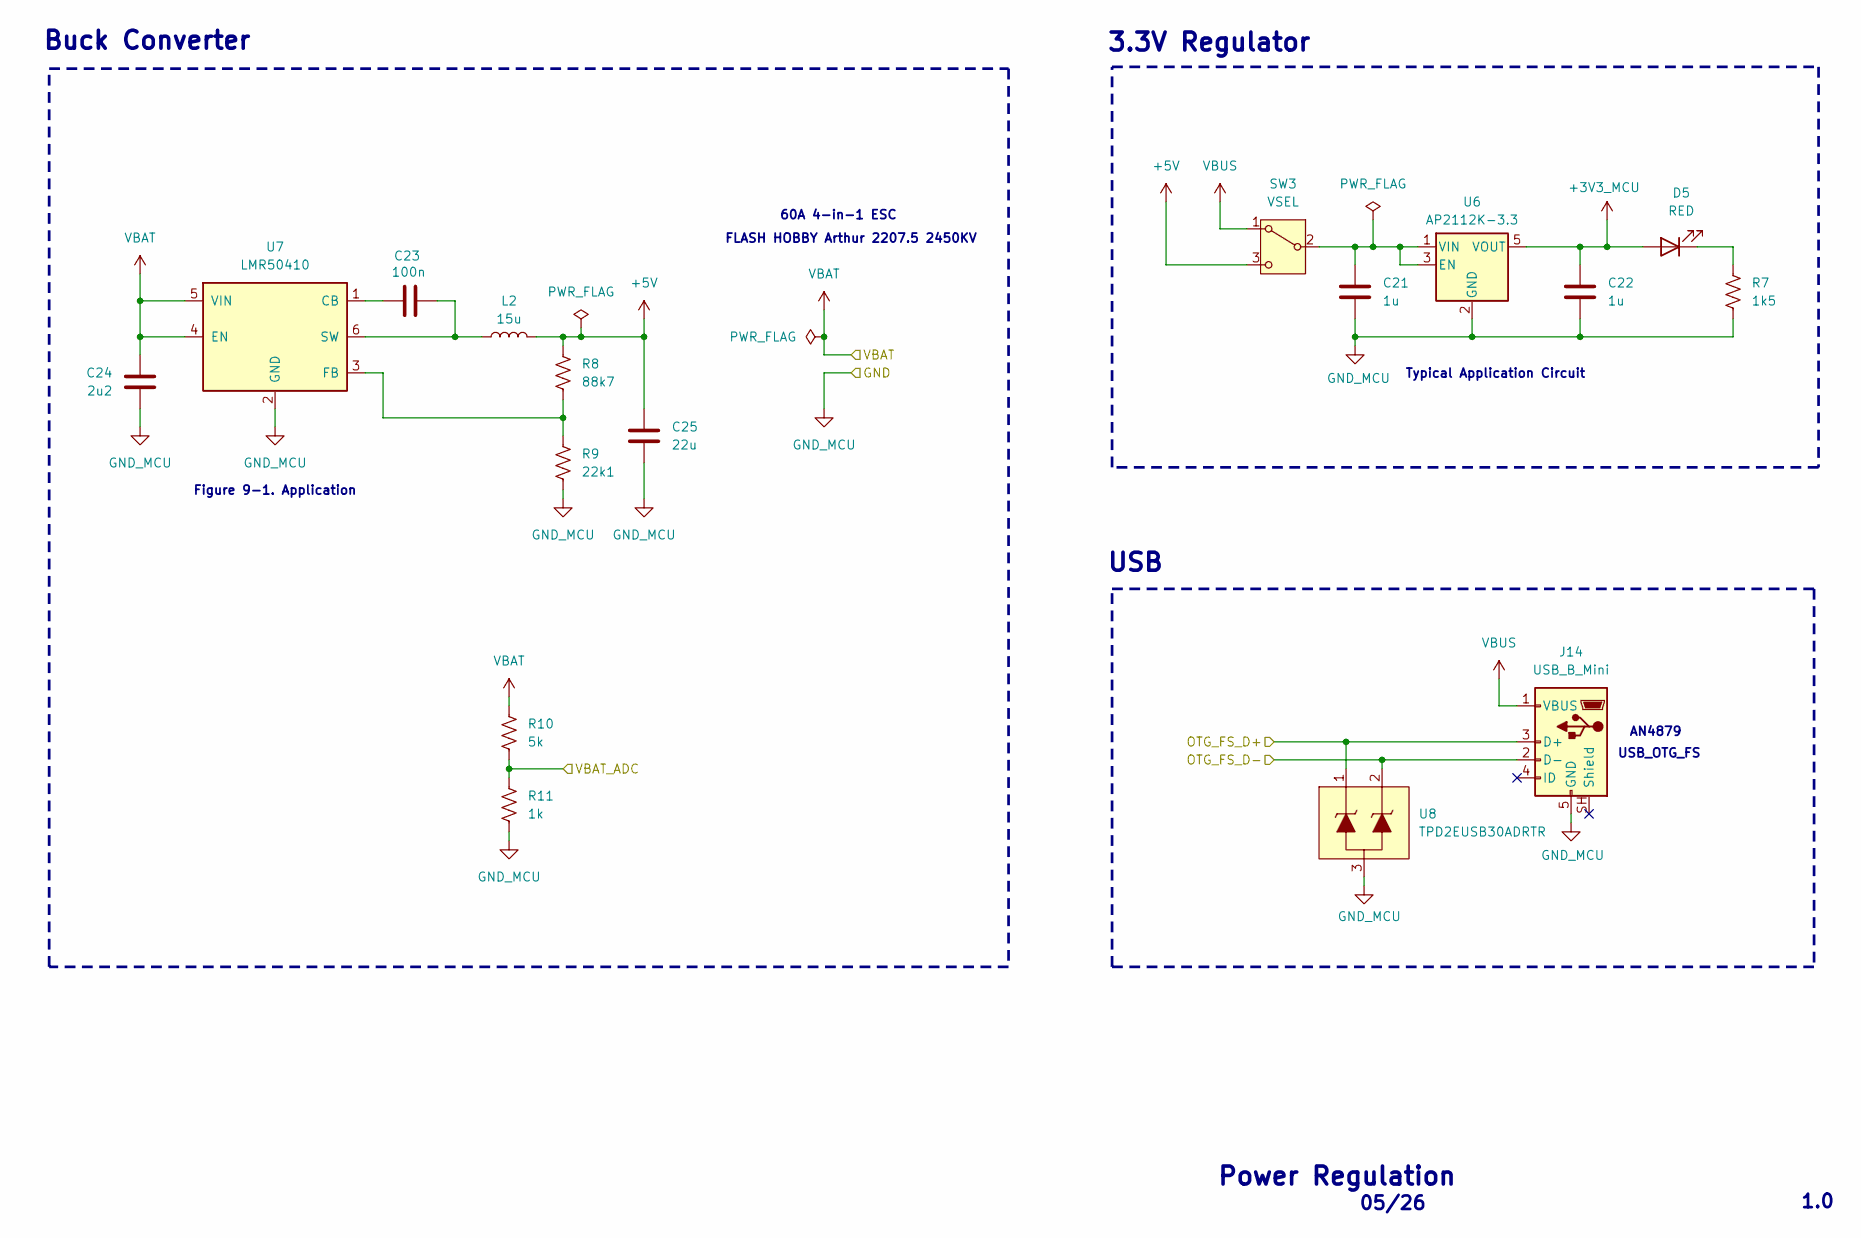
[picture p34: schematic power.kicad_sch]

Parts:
C21, C22: 1u; C_0805_2012Metric
C23: 100n; C_0805_2012Metric
C24: 2u2; C_0805_2012Metric
C25: 22u; C_0805_2012Metric
D5: RED; LED_0805_2012Metric
J14: USB_B_Mini; EDAC_690-005-299-043
L2: 15u; L_0805_2012Metric
R7: 1k5; R_0805_2012Metric
R8: 88k7; R_0805_2012Metric
R9: 22k1; R_0805_2012Metric
R10: 5k; R_0805_2012Metric
R11: 1k; R_0805_2012Metric
SW3: VSEL; SW_SPDT_PCM12
U6: AP2112K-3.3; SOT-23-5
U7: LMR50410; SOT-23-6
U8: SOT-723

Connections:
+3V3_MCU: C22.1, D5.2 (A), U6.5 (VOUT); also elsewhere on the board
+5V: C25.1, L2.2, R8.1, SW3.3 (C)
/MCU/ADC_IN11: R10.2, R11.1; also elsewhere on the board
/MCU/OTG_FS_D+: J14.3 (D+), U8.1; also elsewhere on the board
/MCU/OTG_FS_D-: J14.2 (D-), U8.2; also elsewhere on the board
GND_MCU: C21.2, C22.2, C24.2, C25.2, J14.5 (GND), R7.2, R9.2, R11.2, U6.2 (GND), U7.2 (GND), U8.3; also elsewhere on the board
unnamed: D5.1 (K), R7.1
unnamed: C21.1, SW3.2 (B), U6.1 (VIN), U6.3 (EN)
unnamed: C23.1, U7.1 (CB)
unnamed: R8.2, R9.1, U7.3 (FB)
unnamed: C23.2, L2.1, U7.6 (SW)
VBAT: C24.1, R10.1, U7.4 (EN), U7.5 (VIN); also elsewhere on the board
VBUS: J14.1 (VBUS), SW3.1 (A)

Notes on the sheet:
USB
Figure 9-1. Application
USB_OTG_FS
60A 4-in-1 ESC
FLASH HOBBY Arthur 2207.5 2450KV
05/26
AN4879
Buck Converter
Power Regulation
3.3V Regulator
1.0
Typical Application Circuit

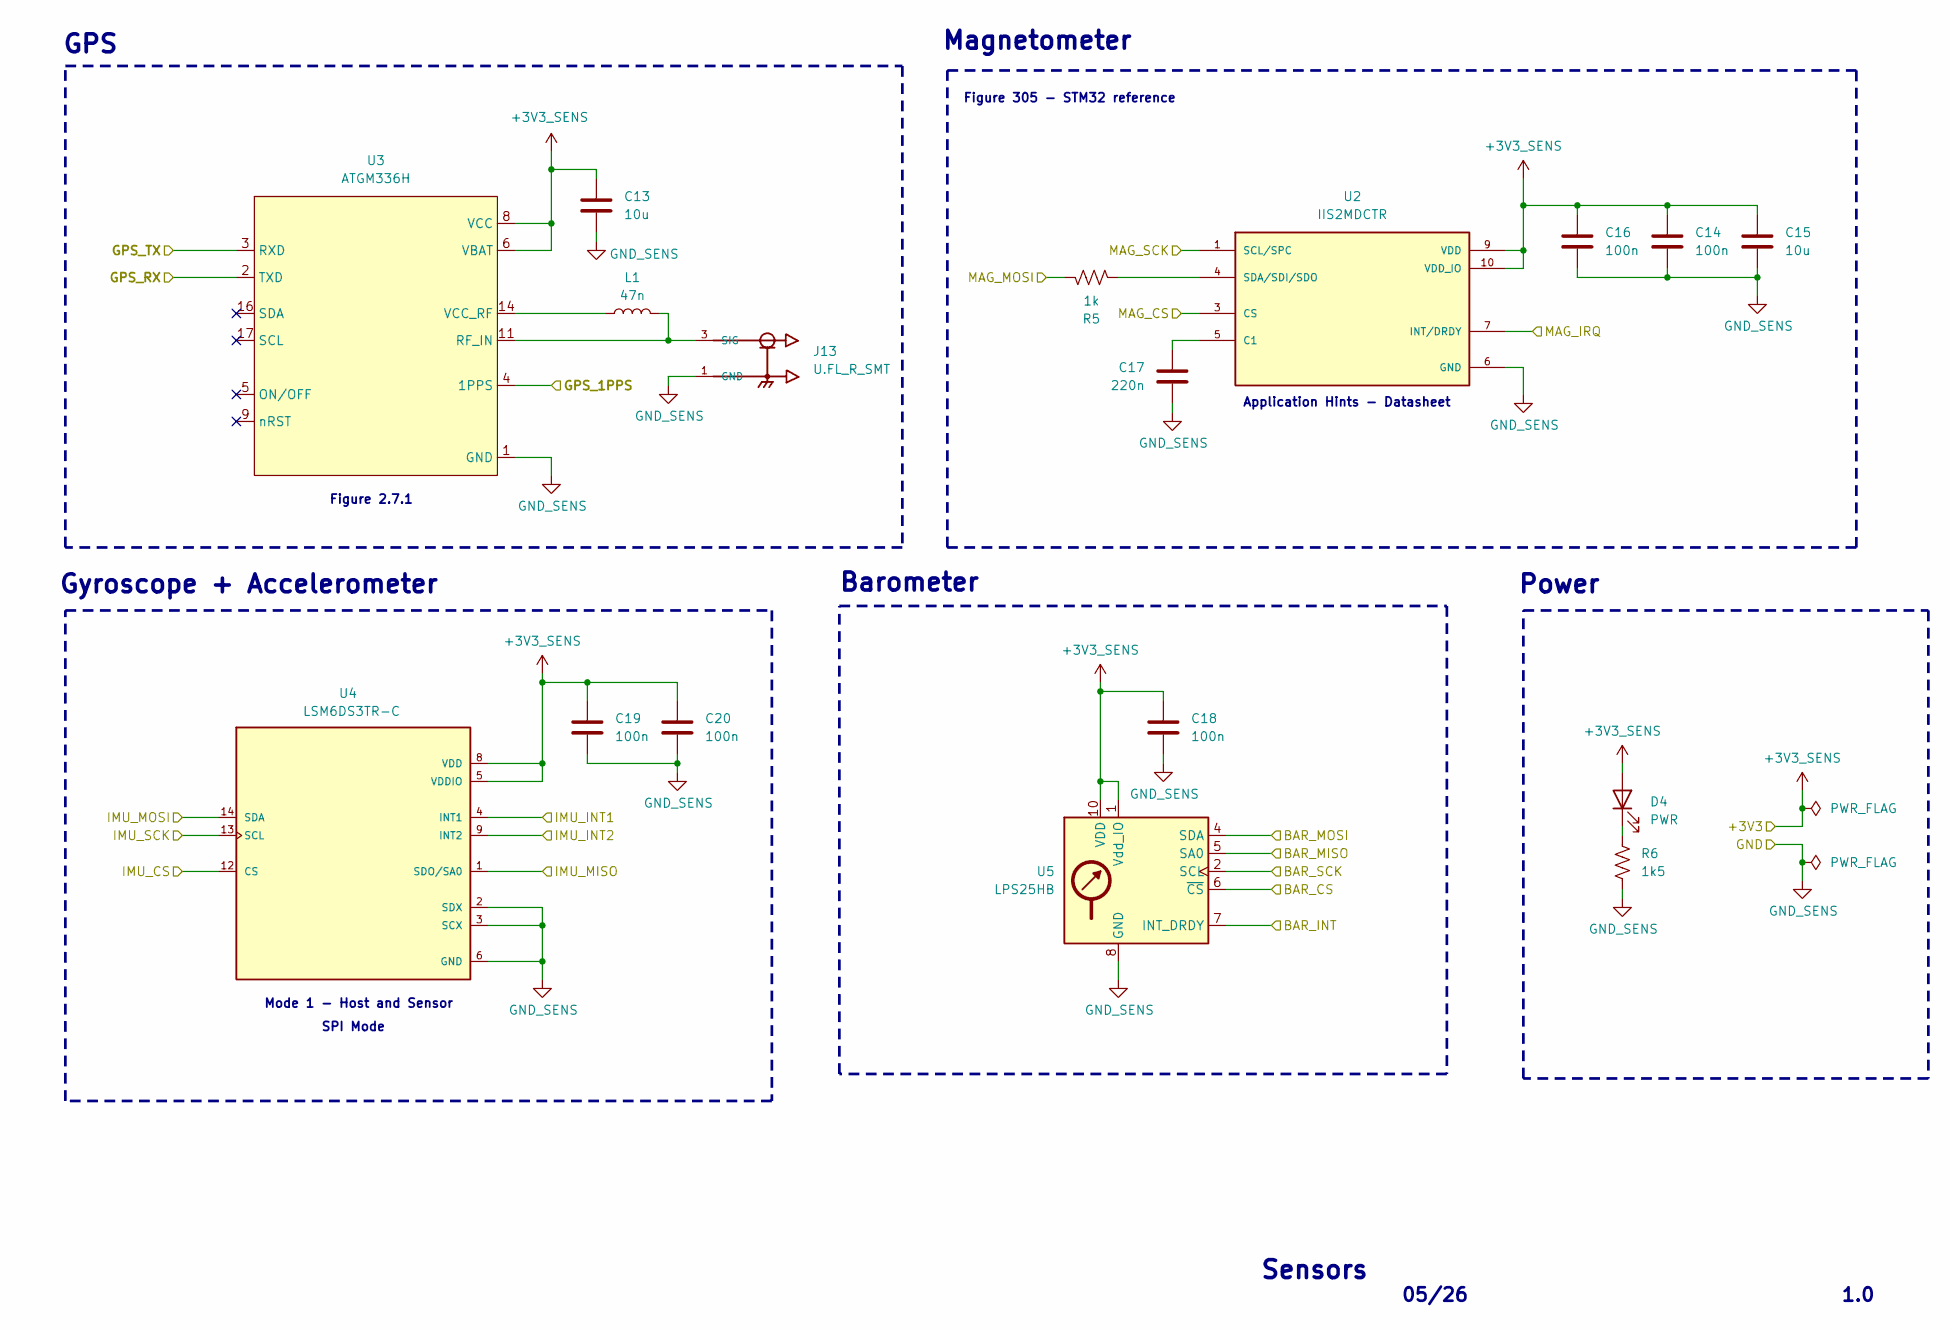
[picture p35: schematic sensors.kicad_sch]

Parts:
C13, C15: 10u; C_0805_2012Metric
C14, C16, C18, C19, C20: 100n; C_0805_2012Metric
C17: 220n; C_0805_2012Metric
D4: PWR; LED_0805_2012Metric
J13: U.FL_R_SMT; HRS_UFL_R_SMT
L1: 47n; L_0805_2012Metric
R5: 1k; R_0805_2012Metric
R6: 1k5; R_0805_2012Metric
U2: IIS2MDCTR; MOUSER_PART_NUMBER 511-IIS2MDCTR
U3: ATGM336H
U4: LSM6DS3TR-C; LSM6DS3TR
U5: LPS25HB; ST_HLGA-10_2.5x2.5mm_P0.6mm_LayoutBorder3x2y

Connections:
+3V3_SENS: C13.1, C14.1, C15.1, C16.1, C18.1, C19.1, C20.1, D4.2 (A), U2.9 (VDD), U2.10 (VDD_IO), U3.6 (VBAT), U3.8 (VCC), U4.5 (VDDIO), U4.8 (VDD), U5.1 (Vdd_IO), U5.10 (VDD); also elsewhere on the board
/Sensors/BAR_CS: U5.6 (~CS); also elsewhere on the board
/Sensors/BAR_INT: U5.7 (INT_DRDY); also elsewhere on the board
/Sensors/BAR_MISO: U5.5 (SA0); also elsewhere on the board
/Sensors/BAR_MOSI: U5.4 (SDA); also elsewhere on the board
/Sensors/BAR_SCK: U5.2 (SCL); also elsewhere on the board
/Sensors/GPS_1PPS: U3.4 (1PPS); also elsewhere on the board
/Sensors/GPS_RX: U3.2 (TXD); also elsewhere on the board
/Sensors/GPS_TX: U3.3 (RXD); also elsewhere on the board
/Sensors/IMU_CS: U4.12 (CS); also elsewhere on the board
/Sensors/IMU_INT1: U4.4 (INT1); also elsewhere on the board
/Sensors/IMU_INT2: U4.9 (INT2); also elsewhere on the board
/Sensors/IMU_MISO: U4.1 (SDO/SA0); also elsewhere on the board
/Sensors/IMU_MOSI: U4.14 (SDA); also elsewhere on the board
/Sensors/IMU_SCK: U4.13 (SCL); also elsewhere on the board
/Sensors/MAG_CS: U2.3 (CS); also elsewhere on the board
/Sensors/MAG_IRQ: U2.7 (INT/DRDY); also elsewhere on the board
/Sensors/MAG_MOSI: R5.1; also elsewhere on the board
/Sensors/MAG_SCK: U2.1 (SCL/SPC); also elsewhere on the board
GND_SENS: C13.2, C14.2, C15.2, C16.2, C17.2, C18.2, C19.2, C20.2, J13.1 (GND), J13.2 (GND), R6.2, U2.6 (GND), U2.8 (GND), U3.1 (GND), U3.10 (GND), U3.12 (GND), U4.2 (SDX), U4.3 (SCX), U4.6 (GND), U4.7 (GND), U5.3 (GND), U5.8 (GND), U5.9 (GND); also elsewhere on the board
unnamed: D4.1 (K), R6.1
unnamed: J13.3 (SIG), L1.1, U3.11 (RF_IN)
unnamed: C17.1, U2.5 (C1)
unnamed: R5.2, U2.4 (SDA/SDI/SDO)
unnamed: L1.2, U3.14 (VCC_RF)

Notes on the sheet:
SPI Mode
Barometer
05/26
GPS
Figure 305 - STM32 reference
Mode 1 - Host and Sensor
1.0
Application Hints - Datasheet
Gyroscope + Accelerometer
Power
Magnetometer
Figure 2.7.1
Sensors

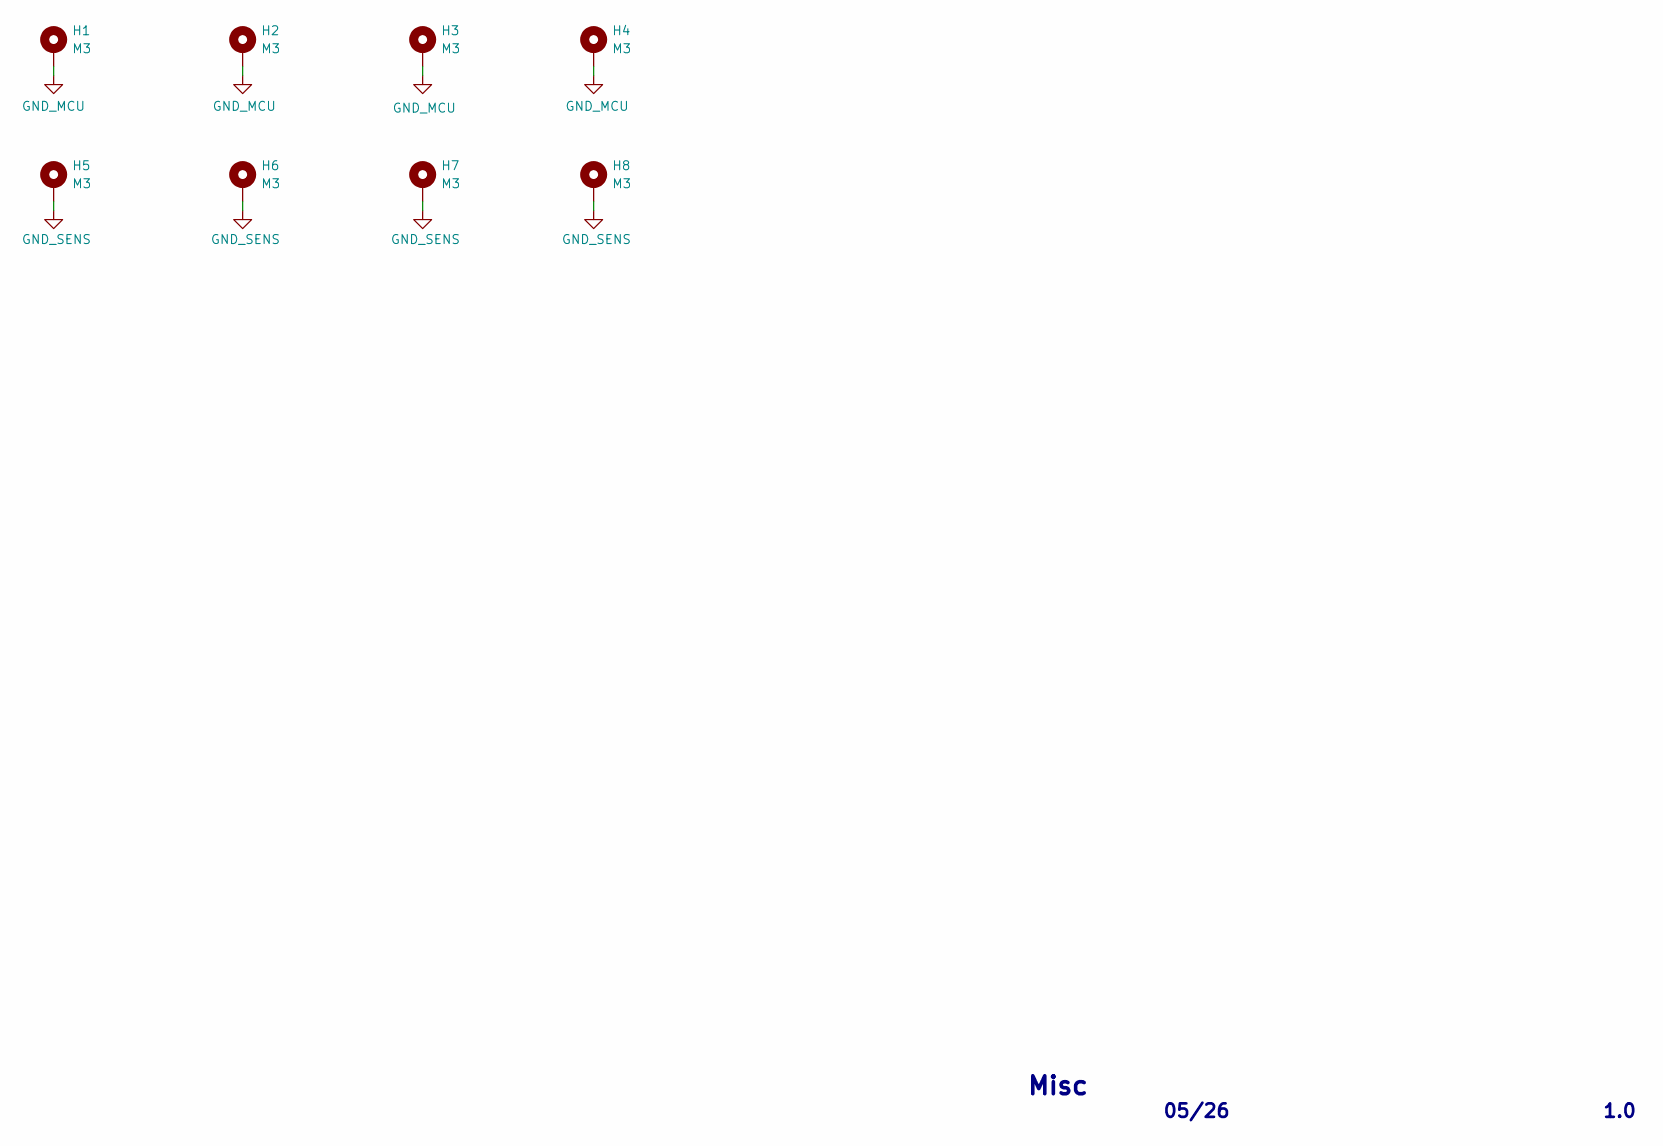
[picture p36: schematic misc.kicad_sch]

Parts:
H1, H2, H3, H4, H5, H6, H7, H8: M3; MountingHole_3.2mm_M3_DIN965_Pad

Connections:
GND_MCU: H1.1 (1_1), H2.1 (1_1), H3.1 (1_1), H4.1 (1_1); also elsewhere on the board
GND_SENS: H5.1 (1_1), H6.1 (1_1), H7.1 (1_1), H8.1 (1_1); also elsewhere on the board

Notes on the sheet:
05/26
1.0
Misc


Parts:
C26: 10n; C_0402_1005Metric
C27: 1n; C_0402_1005Metric
C28: 2n2; C_0402_1005Metric
C29: 33n; C_0402_1005Metric
C30, C31: 22p; C_0402_1005Metric
FB1: MPZ2012S601AT000; R_0805_2012Metric
FL1: 2450BM14A0002T; FIL_2450BM14A0002T
J15: CON-SMA-EDGE-S; RFSOLUTIONS_CON-SMA-EDGE-S
R12: 22k; R_0402_1005Metric
R13: 1M; R_0402_1005Metric
U9: nRF24L01P; QFN-20-1EP_4x4mm_P0.5mm_EP2.5x2.5mm
Y2: 16MHz; XTAL_ABM8AIG-16.000MHZ-12-2Z-T3

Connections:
+3V3_MCU: FB1.2; also elsewhere on the board
/MCU/RF_CE: U9.1 (CE); also elsewhere on the board
/MCU/RF_IRQ: U9.6 (IRQ); also elsewhere on the board
/MCU/SPI3_MISO: U9.5 (MISO); also elsewhere on the board
/MCU/SPI3_MOSI: U9.4 (MOSI); also elsewhere on the board
/MCU/SPI3_NSS: U9.2 (CSN); also elsewhere on the board
/MCU/SPI3_SCK: U9.3 (SCK); also elsewhere on the board
GND_MCU: C26.2, C27.2, C28.2, C29.2, C30.2, C31.2, FL1.2 (GND), J15.G1, J15.G2, J15.G3, J15.G4, R12.2, U9.8 (VSS), U9.14 (VSS), U9.17 (VSS), U9.20 (VSS), Y2.2 (G), Y2.4 (G); also elsewhere on the board
unnamed: C26.1, C27.1, FB1.1, U9.7 (VDD), U9.15 (VDD), U9.18 (VDD)
unnamed: FL1.3 (BALPRT1), U9.13 (ANT2)
unnamed: FL1.4 (BALPRT2), U9.12 (ANT1)
unnamed: C28.1, FL1.5 (DCFEED+RFGND/GND), U9.11 (VDD_PA)
unnamed: FL1.1 (UNBALPRT), J15.1
unnamed: C29.1, U9.19 (DVDD)
unnamed: R12.1, U9.16 (IREF)
unnamed: C31.1, R13.1, U9.10 (XC1), Y2.3
unnamed: C30.1, R13.2, U9.9 (XC2), Y2.1

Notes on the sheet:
1.0
nRF24L01+ Radio
05/26


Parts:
C1, C2, C3, C4, C5, C7, C9: 100n; C_0805_2012Metric
C6: 10u; C_0805_2012Metric
C8: 1u; C_0805_2012Metric
C10, C11: 22p; C_0805_2012Metric
C12: 4u7; C_0805_2012Metric
D1: USER; LED_0805_2012Metric
D2: STAT1; LED_0805_2012Metric
D3: STAT2; LED_0805_2012Metric
R1: 10k; R_0805_2012Metric
R2, R3, R4: 1k5; R_0805_2012Metric
SW1: NRST; SW_SPST_TL3305A
SW2: BOOT0; SW_SPDT_PCM12
U1: STM32F446RCTx; LQFP-64_10x10mm_P0.5mm
Y1: 8MHz; XTAL_ABM3-16.000MHZ-D2Y-T

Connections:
+3V3_MCU: C1.1, C2.1, C3.1, C4.1, C5.1, C6.1, C7.1, C8.1, SW2.1 (A), U1.1 (VBAT), U1.13 (VDDA), U1.19 (VDD), U1.32 (VDD), U1.48 (VDD), U1.64 (VDD); also elsewhere on the board
/ESC1: U1.17 (PA3); also elsewhere on the board
/ESC2: U1.16 (PA2); also elsewhere on the board
/ESC3: U1.15 (PA1); also elsewhere on the board
/ESC4: U1.14 (PA0); also elsewhere on the board
/MCU/ADC_IN11: U1.9 (PC1); also elsewhere on the board
/MCU/BAR_IRQ: U1.27 (PB1); also elsewhere on the board
/MCU/BOOT0: R1.2, U1.60 (BOOT0)
/MCU/HSE_IN: C10.1, U1.5 (PH0), Y1.1
/MCU/HSE_OUT: C11.1, U1.6 (PH1), Y1.2
/MCU/IIS2_IRQ: U1.33 (PB12); also elsewhere on the board
/MCU/IMU_IRQ1: U1.24 (PC4); also elsewhere on the board
/MCU/IMU_IRQ2: U1.25 (PC5); also elsewhere on the board
/MCU/NRST: C9.1, SW1.2, U1.7 (NRST); also elsewhere on the board
/MCU/OTG_FS_D+: U1.45 (PA12); also elsewhere on the board
/MCU/OTG_FS_D-: U1.44 (PA11); also elsewhere on the board
/MCU/RF_CE: U1.59 (PB7); also elsewhere on the board
/MCU/RF_IRQ: U1.50 (PA15); also elsewhere on the board
/MCU/SPI1_MISO: U1.22 (PA6); also elsewhere on the board
/MCU/SPI1_MOSI: U1.23 (PA7); also elsewhere on the board
/MCU/SPI1_NSS_1: U1.28 (PB2); also elsewhere on the board
/MCU/SPI1_NSS_2: U1.26 (PB0); also elsewhere on the board
/MCU/SPI1_SCK: U1.21 (PA5); also elsewhere on the board
/MCU/SPI2_MOSI: U1.36 (PB15); also elsewhere on the board
/MCU/SPI2_NSS: U1.41 (PA8); also elsewhere on the board
/MCU/SPI2_SCK: U1.34 (PB13); also elsewhere on the board
/MCU/SPI3_MISO: U1.52 (PC11); also elsewhere on the board
/MCU/SPI3_MOSI: U1.53 (PC12); also elsewhere on the board
/MCU/SPI3_NSS: U1.58 (PB6); also elsewhere on the board
/MCU/SPI3_SCK: U1.51 (PC10); also elsewhere on the board
/MCU/STAT1: R3.1, U1.57 (PB5)
/MCU/STAT2: R4.1, U1.56 (PB4)
/MCU/SWCLK: U1.49 (PA14); also elsewhere on the board
/MCU/SWDIO: U1.46 (PA13); also elsewhere on the board
/MCU/SWO: U1.55 (PB3); also elsewhere on the board
/MCU/UART1_RX: U1.43 (PA10); also elsewhere on the board
/MCU/UART1_TX: U1.42 (PA9); also elsewhere on the board
GND_MCU: C1.2, C2.2, C3.2, C4.2, C5.2, C6.2, C7.2, C8.2, C9.2, C10.2, C11.2, C12.2, D1.1 (K), D2.1 (K), D3.1 (K), SW1.1, SW2.3 (C), U1.12 (VSSA), U1.18 (VSS), U1.31 (VSS), U1.47 (VSS), U1.63 (VSS); also elsewhere on the board
unnamed: D1.2 (A), R2.2
unnamed: D2.2 (A), R3.2
unnamed: D3.2 (A), R4.2
unnamed: R1.1, SW2.2 (B)
unnamed: R2.1, U1.54 (PD2)
unnamed: C12.1, U1.30 (VCAP_1)

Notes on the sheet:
AN4488
1x 100nF per VDD
1.0
MCU
05/26
VCAP - Table 18 Datasheet
AN2867 - reference design
1x 10uF per STM32
C = 2 * (Cload - Cstray)
AN2867



Board: 4 copper layers, 108.4 x 50.0 mm, 90 parts (9 on the bottom side), 86 nets.

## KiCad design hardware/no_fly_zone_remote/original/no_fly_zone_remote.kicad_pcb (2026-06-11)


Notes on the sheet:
no_fly_zone Remote
03/26
1.0


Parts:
C1, C2: 100n; C_0805_2012Metric
C3, C4: 1u; C_0805_2012Metric
C5, C6: 10u; C_0805_2012Metric
D1: RED; LED_0805_2012Metric
D2, D3: MSP3V3; DO-219AD_VIS
D4: FULL; LED_0805_2012Metric
D5: CHARGING; LED_0805_2012Metric
J1: VBAT; JST_PH_S2B-PH-K_1x02_P2.00mm_Horizontal
J2: USB_B_Mini; EDAC_690-005-299-043
R1, R5, R6: 1k5; R_0805_2012Metric
R2: 2k5; R_0805_2012Metric
R3, R4: 1M; R_0805_2012Metric
R7: 5k; R_0805_2012Metric
SW1: ON/OFF; PinHeader_1x02_P2.54mm_Vertical
U1: AP2112K-3.3; SOT-23-5
U2: TPS2115; TPS2115A-TSSOP-8
U3: TP4056-42-ESOP8; SOIC-8-1EP_3.9x4.9mm_P1.27mm_EP2.41x3.3mm

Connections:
+3V3: C4.1, D1.2 (A), U1.5 (VOUT); also elsewhere on the board
/MCU/ADC1_IN15: R3.2, R4.1; also elsewhere on the board
/MCU/USB_D+: D2.1, J2.3 (D+); also elsewhere on the board
/MCU/USB_D-: D3.1, J2.2 (D-); also elsewhere on the board
GND: C1.2, C2.2, C3.2, C4.2, C5.2, C6.2, D2.2, D3.2, J1.1, J2.5 (GND), R1.2, R2.2, R4.2, R7.2, U1.2 (GND), U2.3 (D1), U2.5 (GND), U3.1 (TEMP), U3.3 (GND), U3.9 (EPAD); also elsewhere on the board
unnamed: D1.1 (K), R1.1
unnamed: D4.1 (K), R5.1
unnamed: D5.1 (K), R6.1
unnamed: J1.2, SW1.1 (A)
unnamed: R2.1, U2.4 (ILIM)
unnamed: R7.1, U3.2 (PROG)
unnamed: R6.2, U3.7 (~CHRG)
unnamed: R5.2, U3.6 (~STDBY)
VBAT: C1.1, C6.1, R3.1, SW1.2 (B), U2.8 (IN1), U3.5 (BAT)
VBUS: C2.1, C5.1, D4.2 (A), D5.2 (A), J2.1 (VBUS), U2.6 (IN2), U3.4 (V_{CC}), U3.8 (CE)
VSEL: C3.1, U1.1 (VIN), U1.3 (EN), U2.7 (OUT)

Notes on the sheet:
Power + Charging
Power Input
3.3V Regulator
Rprog = 1100 / 0.22 = 5000
Imax = 500 / 2500 = 200mA
1.0
Rprog = 1100 / Ibat
Imax = 500 / RILIM
Autoswitching Power Mux
If VBUS (USB power) not present, use VBAT. If VBUS present, use VBUS so LiPo can charge
03/26
Autoswitching configuration - Figure 14
3.7V LiPo Charger
Charging and Cycle Status Indicator - No Temperature Monitoring
USB_OTG_FS
AN4879
Full LiPo: 4.2V Empty LiPo: 2.5V ADC resolution: 12 bits Voltage resolution: 3.3V / 2^12 = 0.8 mV BAT_LVL at full: 2.1V BAT_LVL at empty: 1.25V States between full and empty: (2.1V - 1.25V) / 0.8mV = ~1060 states

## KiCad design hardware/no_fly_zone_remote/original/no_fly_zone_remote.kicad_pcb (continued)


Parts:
C13: 10n; C_0402_1005Metric
C14: 1n; C_0402_1005Metric
C15: 2n2; C_0402_1005Metric
C16: 33n; C_0402_1005Metric
C17, C18: 22p; C_0402_1005Metric
FB1: MPZ2012S601AT000; R_0805_2012Metric
FL1: 2450BM14A0002T; FIL_2450BM14A0002T
J4: CON-SMA-EDGE-S; RFSOLUTIONS_CON-SMA-EDGE-S
R10: 22k; R_0402_1005Metric
R11: 1M; R_0402_1005Metric
U5: PinHeader_1x04_P2.54mm_Vertical
U6: nRF24L01P; QFN-20-1EP_4x4mm_P0.5mm_EP2.5x2.5mm
U7, U8: Joystick 2-Axis Resistive; XDCR_COM-09032
Y1: 16MHz; XTAL_ABM8AIG-16.000MHZ-12-2Z-T3

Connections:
+3V3: FB1.2, U5.1 (VCC), U7.H1 (H+), U7.V1 (V+), U8.H1 (H+), U8.V1 (V+); also elsewhere on the board
/MCU/ADC1_IN5: U7.V2 (V); also elsewhere on the board
/MCU/ADC1_IN6: U7.H2 (H); also elsewhere on the board
/MCU/ADC1_IN7: U8.V2 (V); also elsewhere on the board
/MCU/ADC1_IN8: U8.H2 (H); also elsewhere on the board
/MCU/I2C1_SCL: U5.3 (SCL); also elsewhere on the board
/MCU/I2C1_SDA: U5.4 (SDA); also elsewhere on the board
/MCU/RF_CE: U6.1 (CE); also elsewhere on the board
/MCU/RF_IRQ: U6.6 (IRQ); also elsewhere on the board
/MCU/SPI1_MISO: U6.5 (MISO); also elsewhere on the board
/MCU/SPI1_MOSI: U6.4 (MOSI); also elsewhere on the board
/MCU/SPI1_NSS: U6.2 (CSN); also elsewhere on the board
/MCU/SPI1_SCK: U6.3 (SCK); also elsewhere on the board
GND: C13.2, C14.2, C15.2, C16.2, C17.2, C18.2, FL1.2 (GND), J4.G1, J4.G2, J4.G3, J4.G4, R10.2, U5.2 (GND), U6.8 (VSS), U6.14 (VSS), U6.17 (VSS), U6.20 (VSS), U7.H3 (H-), U7.V3 (V-), U8.H3 (H-), U8.V3 (V-), Y1.2 (G), Y1.4 (G); also elsewhere on the board
unnamed: C13.1, C14.1, FB1.1, U6.7 (VDD), U6.15 (VDD), U6.18 (VDD)
unnamed: FL1.3 (BALPRT1), U6.13 (ANT2)
unnamed: FL1.4 (BALPRT2), U6.12 (ANT1)
unnamed: C15.1, FL1.5 (DCFEED+RFGND/GND), U6.11 (VDD_PA)
unnamed: FL1.1 (UNBALPRT), J4.1
unnamed: C16.1, U6.19 (DVDD)
unnamed: R10.1, U6.16 (IREF)
unnamed: C18.1, R11.1, U6.10 (XC1), Y1.3
unnamed: C17.1, R11.2, U6.9 (XC2), Y1.1

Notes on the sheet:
03/26
Figure 2 - Reference Design
nRF24L01+ Radio
SSD1306
Joysticks
OLED
1.0
Sensors
Throttle/Yaw Joystick
Pitch/Roll Joystick
Possible Improvements - Add RFX210C for power boost


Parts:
C7, C8, C12: 100n; C_0805_2012Metric
C9: 10u; C_0805_2012Metric
C10: 10n; C_0805_2012Metric
C11: 1u; C_0805_2012Metric
D6: GREEN; LED_0805_2012Metric
J3: SWD; PinHeader_1x06_P2.54mm_Vertical
R8: 10K; R_0805_2012Metric
R9: 1k5; R_0805_2012Metric
SW2: NRST; SW_SPST_TL3305A
SW3: BOOT0; SW_SPDT_PCM12
U4: STM32L432KCUx; QFN-32-1EP_5x5mm_P0.5mm_EP3.45x3.45mm

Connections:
+3V3: C7.1, C8.1, C9.1, C10.1, C11.1, J3.1, SW3.1 (A), U4.1 (VDD), U4.5 (VDDA), U4.17 (VDD); also elsewhere on the board
/MCU/ADC1_IN5: U4.6 (PA0); also elsewhere on the board
/MCU/ADC1_IN6: U4.7 (PA1); also elsewhere on the board
/MCU/ADC1_IN7: U4.8 (PA2); also elsewhere on the board
/MCU/ADC1_IN8: U4.9 (PA3); also elsewhere on the board
/MCU/ADC1_IN15: U4.14 (PB0); also elsewhere on the board
/MCU/BOOT0: R8.2, U4.31 (PH3)
/MCU/I2C1_SCL: U4.29 (PB6); also elsewhere on the board
/MCU/I2C1_SDA: U4.30 (PB7); also elsewhere on the board
/MCU/NRST: C12.1, J3.4, SW2.2, U4.4 (NRST)
/MCU/RF_CE: U4.18 (PA8); also elsewhere on the board
/MCU/RF_IRQ: U4.19 (PA9); also elsewhere on the board
/MCU/SPI1_MISO: U4.12 (PA6); also elsewhere on the board
/MCU/SPI1_MOSI: U4.13 (PA7); also elsewhere on the board
/MCU/SPI1_NSS: U4.10 (PA4); also elsewhere on the board
/MCU/SPI1_SCK: U4.11 (PA5); also elsewhere on the board
/MCU/SWCLK: J3.2, U4.24 (PA14)
/MCU/SWDIO: J3.3, U4.23 (PA13)
/MCU/SWO: J3.5, U4.26 (PB3)
/MCU/USB_D+: U4.22 (PA12); also elsewhere on the board
/MCU/USB_D-: U4.21 (PA11); also elsewhere on the board
GND: C7.2, C8.2, C9.2, C10.2, C11.2, C12.2, J3.6, R9.2, SW2.1, SW3.3 (C), U4.16 (VSS), U4.32 (VSS), U4.33 (VSS); also elsewhere on the board
unnamed: D6.2 (A), U4.25 (PA15)
unnamed: D6.1 (K), R9.1
unnamed: R8.1, SW3.2 (B)

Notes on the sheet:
03/26
AN4555 Reference Design
AN4555 100nF for each VDD pin, 10uF for package 1nF + 1uF for VDDA
MCU
1.0


Board: 4 copper layers, 103.2 x 52.0 mm, 53 parts (0 on the bottom side), 45 nets.

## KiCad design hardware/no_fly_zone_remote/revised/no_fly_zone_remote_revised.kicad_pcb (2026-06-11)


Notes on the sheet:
no_fly_zone Remote
03/26
1.0


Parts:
H1, H2, H3, H4: M3; MountingHole_3.2mm_M3_Pad

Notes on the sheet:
1.0
05/26
Miscellaneous


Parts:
C1, C2: 100n; C_0805_2012Metric
C3, C4: 1u; C_0805_2012Metric
C5, C6: 10u; C_0805_2012Metric
D1: RED; LED_0805_2012Metric
D2: FULL; LED_0805_2012Metric
D3: CHARGING; LED_0805_2012Metric
J1: VBAT; JST_PH_S2B-PH-K_1x02_P2.00mm_Horizontal
J2: USB_B_Mini; EDAC_690-005-299-043
R1, R2, R5, R6: 1k5; R_0805_2012Metric
R3, R4: 10k; R_0805_2012Metric
R7: 6k; R_0805_2012Metric
SW1: ON/OFF; SW_SPDT_PCM12
U1: AP2112K-3.3; SOT-23-5
U2: TPS2115; TPS2115A-TSSOP-8
U3: SOT-723
U4: TP4056-42-ESOP8; SOIC-8-1EP_3.9x4.9mm_P1.27mm_EP2.41x3.3mm

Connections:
+3V3: C4.1, D1.2 (A), U1.5 (VOUT); also elsewhere on the board
/MCU/ADC1_IN15: R3.2, R4.1; also elsewhere on the board
/MCU/USB_D+: J2.3 (D+), U3.1; also elsewhere on the board
/MCU/USB_D-: J2.2 (D-), U3.2; also elsewhere on the board
GND: C1.2, C2.2, C3.2, C4.2, C5.2, C6.2, J1.1, J2.5 (GND), R1.2, R2.2, R4.2, R7.2, U1.2 (GND), U2.3 (D1), U2.5 (GND), U3.3, U4.1 (TEMP), U4.3 (GND), U4.9 (EPAD); also elsewhere on the board
unnamed: D1.1 (K), R1.1
unnamed: D2.1 (K), R5.1
unnamed: D3.1 (K), R6.1
unnamed: J1.2, SW1.2 (B)
unnamed: R2.1, U2.4 (ILIM)
unnamed: R7.1, U4.2 (PROG)
unnamed: R6.2, U4.7 (~CHRG)
unnamed: R5.2, U4.6 (~STDBY)
VBAT: C1.1, C6.1, R3.1, SW1.1 (A), U2.8 (IN1), U4.5 (BAT)
VBUS: C2.1, C5.1, D2.2 (A), D3.2 (A), J2.1 (VBUS), U2.6 (IN2), U4.4 (V_{CC}), U4.8 (CE)
VSEL: C3.1, U1.1 (VIN), U1.3 (EN), U2.7 (OUT)

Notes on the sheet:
Power + Charging
Power Input
3.3V Regulator
Rprog = 1200 / 0.2 = 6000
Imax = 500 / 1500 = 333mA
1.0
Rprog = 1200 / Ibat
Imax = 500 / RILIM
Autoswitching Power Mux
If VBUS (USB power) not present, use VBAT. If VBUS present, use VBUS so LiPo can charge
03/26
Autoswitching configuration - Figure 14
Rev 1.1 - Changed VBAT resistor dividers to 10K for reduced ADC input impedance
3.7V LiPo Charger
Charging and Cycle Status Indicator - No Temperature Monitoring
Changed MSP3V3 ESD diodes to dedicated USB ESD diodes
USB_OTG_FS
AN4879
Full LiPo: 4.2V Empty LiPo: 2.5V ADC resolution: 12 bits Voltage resolution: 3.3V / 2^12 = 0.8 mV BAT_LVL at full: 2.1V BAT_LVL at empty: 1.25V States between full and empty: (2.1V - 1.25V) / 0.8mV = ~1060 states


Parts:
C13: 10n; C_0402_1005Metric
C14: 1n; C_0402_1005Metric
C15: 2n2; C_0402_1005Metric
C16: 33n; C_0402_1005Metric
C17, C18: 22p; C_0402_1005Metric
C19, C20: 100n; C_0805_2012Metric
FB1: MPZ2012S601AT000; R_0805_2012Metric
FL1: 2450BM14A0002T; FIL_2450BM14A0002T
J4: CON-SMA-EDGE-S; RFSOLUTIONS_CON-SMA-EDGE-S
R10: 22k; R_0402_1005Metric
R11, R12, R13, R15, R16: 10k; R_0805_2012Metric
R14: 1M; R_0402_1005Metric
S1: PEC11R-4220F-S0024; XDCR_PEC11R-4220F-S0024
U6: PinHeader_1x04_P2.54mm_Vertical
U7: nRF24L01P; QFN-20-1EP_4x4mm_P0.5mm_EP2.5x2.5mm
U8, U9: PS5; PS5_Joystick
Y1: 16MHz; XTAL_ABM8AIG-16.000MHZ-12-2Z-T3

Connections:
+3V3: FB1.2, R11.1, R12.1, R13.1, U6.1 (VCC), U8.3 (H+), U8.3' (V+), U9.3 (H+), U9.3' (V+); also elsewhere on the board
/MCU/ADC1_IN7: U9.2' (V); also elsewhere on the board
/MCU/ADC1_IN8: U9.2 (H); also elsewhere on the board
/MCU/ADC1_IN9: U8.2' (V); also elsewhere on the board
/MCU/ADC1_IN16: U8.2 (H); also elsewhere on the board
/MCU/ENC_SW: R11.2, S1.2; also elsewhere on the board
/MCU/I2C1_SCL: U6.3 (SCL); also elsewhere on the board
/MCU/I2C1_SDA: U6.4 (SDA); also elsewhere on the board
/MCU/RF_CE: U7.1 (CE); also elsewhere on the board
/MCU/RF_CS: U7.2 (CSN); also elsewhere on the board
/MCU/RF_IRQ: U7.6 (IRQ); also elsewhere on the board
/MCU/SPI1_MISO: U7.5 (MISO); also elsewhere on the board
/MCU/SPI1_MOSI: U7.4 (MOSI); also elsewhere on the board
/MCU/SPI1_SCK: U7.3 (SCK); also elsewhere on the board
/MCU/TIM2_CH1: C19.1, R15.2; also elsewhere on the board
/MCU/TIM2_CH2: C20.1, R16.1; also elsewhere on the board
GND: C13.2, C14.2, C15.2, C16.2, C17.2, C18.2, C19.2, C20.2, FL1.2 (GND), J4.G1, J4.G2, J4.G3, J4.G4, R10.2, S1.1, S1.C (COM), U6.2 (GND), U7.8 (VSS), U7.14 (VSS), U7.17 (VSS), U7.20 (VSS), U8.1 (H-), U8.1' (V-), U8.c (SEL-), U9.1 (H-), U9.1' (V-), U9.c (SEL-), Y1.2 (G), Y1.4 (G); also elsewhere on the board
unnamed: C13.1, C14.1, FB1.1, U7.7 (VDD), U7.15 (VDD), U7.18 (VDD)
unnamed: FL1.3 (BALPRT1), U7.13 (ANT2)
unnamed: FL1.4 (BALPRT2), U7.12 (ANT1)
unnamed: C15.1, FL1.5 (DCFEED+RFGND/GND), U7.11 (VDD_PA)
unnamed: FL1.1 (UNBALPRT), J4.1
unnamed: R12.2, R15.1, S1.A
unnamed: R13.2, R16.2, S1.B
unnamed: C16.1, U7.19 (DVDD)
unnamed: R10.1, U7.16 (IREF)
unnamed: C18.1, R14.1, U7.10 (XC1), Y1.3
unnamed: C17.1, R14.2, U7.9 (XC2), Y1.1

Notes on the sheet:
03/26
Figure 2 - Reference Design
nRF24L01+ Radio
SSD1306
Rotary Encoder
Cload = 2 * Ceq Ceq = Cx + Cpcb + Cix
Joysticks
Cload = 12pF (from Y1 datasheet)
OLED
1.0
Sensors
Throttle/Yaw Joystick
Pitch/Roll Joystick
Possible Improvements - Add RFX210C for power boost


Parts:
C7, C8, C12: 100n; C_0805_2012Metric
C9: 10u; C_0805_2012Metric
C10: 10n; C_0805_2012Metric
C11: 1u; C_0805_2012Metric
D4: GREEN; LED_0805_2012Metric
J3: SWD; PinHeader_1x06_P2.54mm_Vertical
R8: 10K; R_0805_2012Metric
R9: 1k5; R_0805_2012Metric
SW2: NRST; SW_SPST_TL3305A
SW3: BOOT0; SW_SPDT_PCM12
U5: STM32L432KCUx; QFN-32-1EP_5x5mm_P0.5mm_EP3.45x3.45mm

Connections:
+3V3: C7.1, C8.1, C9.1, C10.1, C11.1, J3.1, SW3.1 (A), U5.1 (VDD), U5.5 (VDDA), U5.17 (VDD); also elsewhere on the board
/MCU/ADC1_IN7: U5.8 (PA2); also elsewhere on the board
/MCU/ADC1_IN8: U5.9 (PA3); also elsewhere on the board
/MCU/ADC1_IN9: U5.10 (PA4); also elsewhere on the board
/MCU/ADC1_IN15: U5.14 (PB0); also elsewhere on the board
/MCU/ADC1_IN16: U5.15 (PB1); also elsewhere on the board
/MCU/BOOT0: R8.2, U5.31 (PH3)
/MCU/ENC_SW: U5.27 (PB4); also elsewhere on the board
/MCU/I2C1_SCL: U5.29 (PB6); also elsewhere on the board
/MCU/I2C1_SDA: U5.30 (PB7); also elsewhere on the board
/MCU/NRST: C12.1, J3.4, SW2.2, U5.4 (NRST)
/MCU/RF_CE: U5.18 (PA8); also elsewhere on the board
/MCU/RF_CS: U5.20 (PA10); also elsewhere on the board
/MCU/RF_IRQ: U5.19 (PA9); also elsewhere on the board
/MCU/SPI1_MISO: U5.12 (PA6); also elsewhere on the board
/MCU/SPI1_MOSI: U5.13 (PA7); also elsewhere on the board
/MCU/SPI1_SCK: U5.11 (PA5); also elsewhere on the board
/MCU/SWCLK: J3.2, U5.24 (PA14)
/MCU/SWDIO: J3.3, U5.23 (PA13)
/MCU/SWO: J3.5, U5.26 (PB3)
/MCU/TIM2_CH1: U5.6 (PA0); also elsewhere on the board
/MCU/TIM2_CH2: U5.7 (PA1); also elsewhere on the board
/MCU/USB_D+: U5.22 (PA12); also elsewhere on the board
/MCU/USB_D-: U5.21 (PA11); also elsewhere on the board
GND: C7.2, C8.2, C9.2, C10.2, C11.2, C12.2, J3.6, R9.2, SW2.1, SW3.3 (C), U5.16 (VSS), U5.32 (VSS), U5.33 (VSS); also elsewhere on the board
unnamed: D4.2 (A), U5.25 (PA15)
unnamed: D4.1 (K), R9.1
unnamed: R8.1, SW3.2 (B)

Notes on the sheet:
03/26
AN4555 Reference Design
AN4555 100nF for each VDD pin, 10uF for package 1nF + 1uF for VDDA
MCU
1.0


Board: 4 copper layers, 100.0 x 61.0 mm, 64 parts (0 on the bottom side), 50 nets.

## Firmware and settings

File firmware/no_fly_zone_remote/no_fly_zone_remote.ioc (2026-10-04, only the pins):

Mcu.UserName=STM32L432KCUx
PA0.Signal=S_TIM2_CH1
PA1.Signal=S_TIM2_CH2
PA10.GPIO_Label=RF_CS
PA10.Signal=GPIO_Output
PA11.Signal=USB_DM
PA12.Signal=USB_DP
PA2.GPIO_Label=PITCH_ADC
PA2.Signal=ADCx_IN7
PA3.GPIO_Label=ROLL_ADC
PA3.Signal=ADCx_IN8
PA4.GPIO_Label=THROTTLE_ADC
PA4.Signal=ADCx_IN9
PA5.Signal=SPI1_SCK
PA6.Signal=SPI1_MISO
PA7.Signal=SPI1_MOSI
PA8.GPIO_Label=RF_CE
PA8.Signal=GPIO_Output
PA9.GPIO_Label=RF_IRQ
PA9.Signal=GPIO_Input
PB0.GPIO_Label=BATT_LVL
PB0.Signal=ADCx_IN15
PB1.GPIO_Label=YAW_ADC
PB1.Signal=ADCx_IN16
PB6.Signal=I2C1_SCL
PB7.Signal=I2C1_SDA

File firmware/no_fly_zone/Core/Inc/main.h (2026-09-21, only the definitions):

#define VBAT_SENSE_Pin GPIO_PIN_6
#define VBAT_SENSE_GPIO_Port GPIOA
#define CURR_SENSE_Pin GPIO_PIN_7
#define CURR_SENSE_GPIO_Port GPIOA
#define BAR_CS_Pin GPIO_PIN_12
#define BAR_CS_GPIO_Port GPIOB
#define IMU_CS_Pin GPIO_PIN_6
#define IMU_CS_GPIO_Port GPIOC
#define BAR_IRQ_Pin GPIO_PIN_7
#define BAR_IRQ_GPIO_Port GPIOC
#define BAR_IRQ_EXTI_IRQn EXTI9_5_IRQn
#define IMU_IRQ1_Pin GPIO_PIN_8
#define IMU_IRQ1_GPIO_Port GPIOA
#define IMU_IRQ1_EXTI_IRQn EXTI9_5_IRQn
#define IMU_IRQ2_Pin GPIO_PIN_9
#define IMU_IRQ2_GPIO_Port GPIOA
#define IMU_IRQ2_EXTI_IRQn EXTI9_5_IRQn
#define RF_IRQ_Pin GPIO_PIN_15
#define RF_IRQ_GPIO_Port GPIOA
#define RF_IRQ_EXTI_IRQn EXTI15_10_IRQn
#define STAT1_Pin GPIO_PIN_4
#define STAT1_GPIO_Port GPIOB
#define STAT2_Pin GPIO_PIN_5
#define STAT2_GPIO_Port GPIOB
#define RF_CS_Pin GPIO_PIN_6
#define RF_CS_GPIO_Port GPIOB
#define RF_CE_Pin GPIO_PIN_7
#define RF_CE_GPIO_Port GPIOB
#define STAT3_Pin GPIO_PIN_8
#define STAT3_GPIO_Port GPIOB

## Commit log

2026-04-16 Separated drivers from main application
2026-04-16 Added stm32 submodules
2026-04-16 Using HAL Drivers for all peripherals. Updated submodules
2026-04-27 Modified makefiles to point to local stm32_lib
2026-05-27 Added ADC + DMA functionality with interrupts. Adding OLED library for displaying relevant information
2026-05-27 Added OLED pages for battery and joystick states. Need to test with rotary encoder for menu changes
2026-06-01 Added encoder logic to move between menus. Moved all OLED functions to separate helper file. Updated submodules
2026-06-08 Modified pin layouts to match PCB and currently testing EXTI functionality with nRF and IMU
2026-06-11 Revision 1.0 of remote control and quadcopter MCU + sensor board added. Remote PCB is functional, quadcopter boards need to be tested
    [mcu.kicad_sch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]
2026-06-23 Tested nRF24L01 functionality on custom quadcopter PCB successfully
2026-06-24 Added sensor library paths
2026-06-24 Successfully tested barometer, imu, and rf interrupts
2026-07-01 Changed HSE frequency to 8MHz according to schematic
2026-07-06 Tested imu, barometer, and magnetometer. All are functioning
2026-07-06 Added simple script to print out serial values
2026-07-06 Updated submodules. Need to modify naming conventions and add more functionality for sensors
2026-07-09 Completed basic sensor trials with interrupts. Added python script to view data streamed over USB
2026-07-14 Initial testing of DShot. Need to modify it to use DMA and interrupts
2026-07-14 Tested DShot using timers + DMA on one channel. Need to update it for 4 channels
2026-07-15 Working nearly simultaneous DShot encoding for 4 channels. Had to change CH2 and CH3 to TIM5 for DMA streams
2026-07-16 Added quadcopter PCB revision 2 and updated README
    [mcu.kicad_sch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]
2026-07-21 Added helper functions for handling quaternions and first raw implementation of Madgwick filter. Need to clean up and test
2026-07-23 Fixed and tested Madgwick filter. Changed HPF cutoff to 16mHz for gyroscope for better performance. Added AI generated python scripts for orientation visualization
    [app.c, orientation.py, orientation_quat.py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]
2026-08-01 Final testing for revision 1.0 board
2026-08-02 Revision 2.0 board is configured correctly and properly working
    [app.c, main.h, no_fly_zone.ioc]
2026-08-15 Using encoder library to handle page switches. Updated OLED to use DMA. Added rudimentary tuning functions for PID
2026-08-23 Moved madgwick filter math into separate library
2026-08-23 Corrected sensor to body frame conversion in madgwick filter. Corrected packet structure for rf
    [app.c]
2026-08-23 Added function for conditioning throttle input. Corrected quaternion sending over rf
    [app.c]
2026-08-23 Added new scripts for help with debugging and corrected current scripts orientation
    [motor_monitor.py, orientation_quat.py, self_test.py]
2026-08-29 Updated DShot library to use per channel initialization and modified DMA buffer use for zero packet errors. Need to add BLDC wrapper around it
    [app.c, dshot.c, dshot.h]
2026-08-29 Modified RF struct. Need to figure out how to handle failsafe modes and general flow
    [app.c]
2026-09-07 Added BLDC wrapper for DShot library. Added watchdog and improving error handling
    [app.c, bldc.c, main.h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]
2026-09-07 Updated libs for new BMS library
2026-09-12 Fixed motor mixer commands, modified RF structs to use better naming conventions. Added watchdog reset inside of failsafe
    [app.c, no_fly_zone.ioc]
2026-09-12 Renamed RF structs using better conventions. Fixed OLED PID display truncating. Combined encoder callback functions
    [app.c, no_fly_zone_remote.ioc]
2026-09-14 Moved orientation error calculation to madgwick and corrected torque directions for motor mixing
    [app.c, bldc.c]
2026-09-17 Added 32-bit us timer for IMU and madgwick updating. Added LED status lights for modes and failsafe causes
    [app.c, no_fly_zone.ioc]
2026-09-22 Updated READMEs and added relevant screenshots
    [mcu.kicad_sch, misc.kicad_sch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]
2026-09-23 Updated BMS measurements with offset and increased ADC sample time for resistor divider
2026-09-25 Added case statement for selecting key value
2026-09-25 Added switch statement for key value. Renamed variables and OLED pages
2026-10-04 Added a 32-bit us/ms timer for accurate delays and logging. Updating OLED at 20Hz now. Trying to determine best receiver configurations to reduce packet loss
2026-10-04 Moved interrupt clears to front of if statements to eliminate race conditions. Need to determine cause for packet loss and timeouts
2026-10-05 Modified atomic operations for timeout checks to prevent erratic timeouts. Changed frequency channel to avoid WiFi interference. Test successfully ran for an hour with no timeouts
    [app.c]
2026-10-06 Updated RF struct with better names. Fixed jitter between packet transmission by aligning OLED updates with ADC timer
    [app.c]
2026-10-06 Updated arm state names
2026-10-13 Updated OLED functionality and added watchdog. Need to add joystick calibration page
2026-10-16 Fixed ADC + DMA triggering and moved battery calculation to main loop. Added additional failsafe type
2026-10-16 Created joystick conditioning functions and added calibration feature. Need to test further
2026-10-19 Moved PID tune function to joystick_helper. Moved OLED update inside ADC dr check. Tune and display functions now rely on normalized joystick inputs
2026-10-24 Removed HPF from gyroscope, eliminating drift in simulation. Added throttle minimums for directionality forces. Added I and D terms to motor torques. Potentially need to add bias offset or calibratio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
2026-10-24 Added non-acrobatic mode controls. Added diagram for software flow
2026-10-26 Using gyro LPF for HF vibrations from motors. Added bias offset for gyroscope measurements. Modified k_att to 5.0
2026-10-26 Added clamp function for desired gyro rates
2026-10-26 Moved joystick calibration features to joystick structure handle. Moved position to quaternion calculations to joystick helper
2026-10-26 Made clamp function public
2026-10-30 Updated README, added BOM and 3d files
2026-10-31 Added 3d model of remote frame
2026-11-05 Updated to receive pitch, roll, and yaw angles for debugging
2026-11-05 Fixed quadcopter incorrect roll/pitch directions after yaw. Quadcopter performs perfectly as expected
2026-11-05 Corrected roll/pitch direction after yaw. Added note for PID constants
2026-11-14 Corrected gyro bias calculation

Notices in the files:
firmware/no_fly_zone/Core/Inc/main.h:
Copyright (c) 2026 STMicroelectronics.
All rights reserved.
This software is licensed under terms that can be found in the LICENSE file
